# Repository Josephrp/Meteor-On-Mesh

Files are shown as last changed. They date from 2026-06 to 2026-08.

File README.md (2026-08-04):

# Meshtonic

**Meshtonic H4M Companion v2** is a custom carrier board and firmware stack for a [Seeed XIAO ESP32-S3 Plus](https://www.seeedstudio.com/Seeed-Studio-XIAO-ESP32S3-Plus-p-6361.html) that docks to a **HackRF + PortaPack H4M (Mayhem)** and can also run as a **standalone Meshtastic** mesh node.

**Repository:** [github.com/Josephrp/meshtonic](https://github.com/Josephrp/meshtonic) (formerly `Meteor-On-Mesh`)

<p align="center">
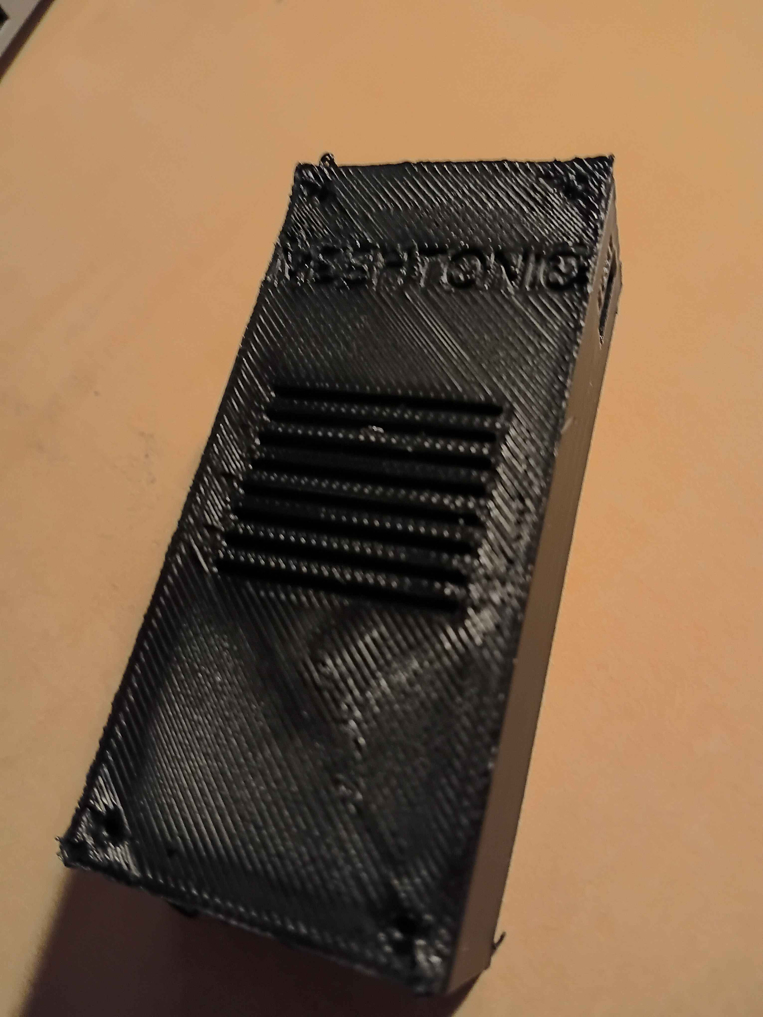
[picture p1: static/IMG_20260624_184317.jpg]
Meshtonic H4M Companion assembled
  
</p>

| Mode | Role |
|---|---|
| **Docked (Mayhem MDK)** | ESP32 is an I2C slave at `0x51` on the PortaPack MDK connector. Exposes GPS, sensors, web UI, and 1–4 LoRa radios to Mayhem; runs the on-device LoRa decoder EPApp. |
| **Standalone (Meshtastic)** | Flash the Meshtastic image instead. Board becomes a LoRa mesh node with GPS, TFT, and muxed sensors. |

The two ESP32 firmwares are **mutually exclusive** — flash one or the other depending on whether you are using the board docked or as a mesh node.

---

## Hardware overview

| Block | Parts |
|---|---|
| **MCU** | Seeed XIAO ESP32-S3 Plus (ESP32-S3, 16 MB flash, OPI PSRAM) |
| **LoRa** | Up to **4×** [Wio-SX1262](https://www.seeedstudio.com/) shields — shared SPI, per-radio CS on native GPIO, BUSY/DIO1/RST via **MCP23017** `@ 0x20` |
| **Sensors** | **TCA9548A** `@ 0x70` mux: BMM150, BMP280, SHT3x, BMI160; **AS5600** on the main I2C bus |
| **GPS** | NEO-6M (UART1) |
| **Display / storage** | ILI9341 240×320 SPI TFT, microSD |
| **Host link** | PortaPack H4M / MDK-compatible connector (I2C slave + power) |
| **Power** | USB / solar → **CN3170** LiPo charge → **TPS63020** 3.3 V buck-boost |

Canonical pin map (silicon GPIO numbers for the XIAO Plus — `Dn ≠ GPIOn` above D5):

- Shared SPI: MOSI / MISO / SCK = GPIO 38 / 39 / 40  
- I2C: SDA / SCL = GPIO 5 / 6  
- WIO1–4 CS: GPIO 3 / 4 / 10 / 13  
- MCP INTA: GPIO 44 · WIO1 DIO1: GPIO 12  
- Full table: [`firmwares/pin_mapping.cpp`](firmwares/pin_mapping.cpp) and the variant [`PIN_AUDIT.md`](firmwares/meshtastic/variants/esp32s3/diy/meshtonic_h4m_wio1/PIN_AUDIT.md)

<p align="center">
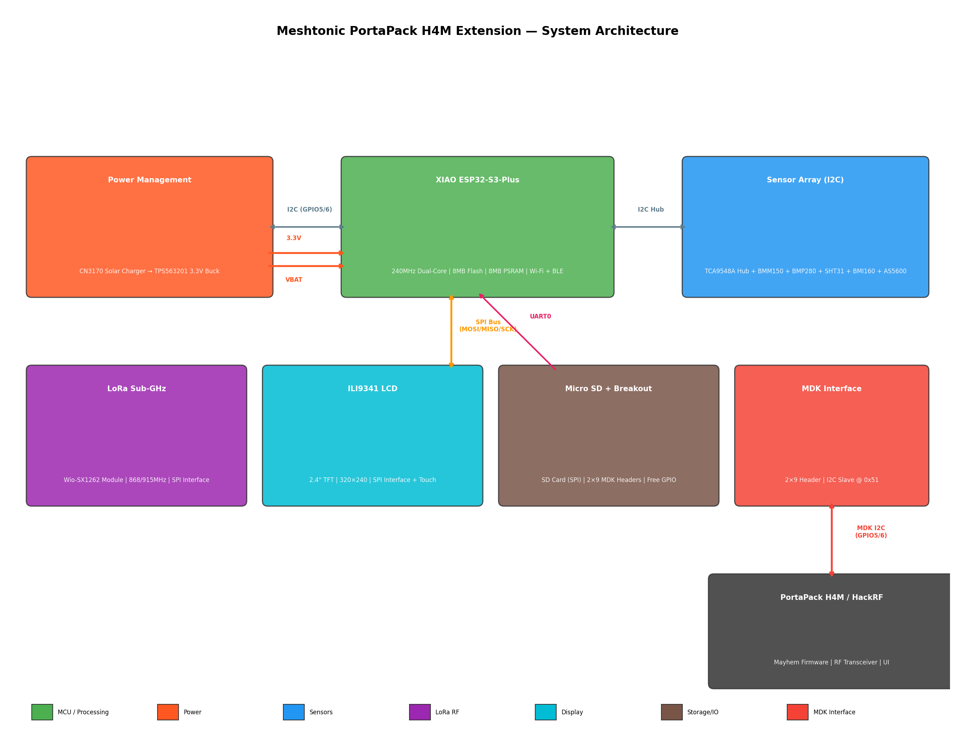
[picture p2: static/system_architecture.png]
System architecture
  
  <br />
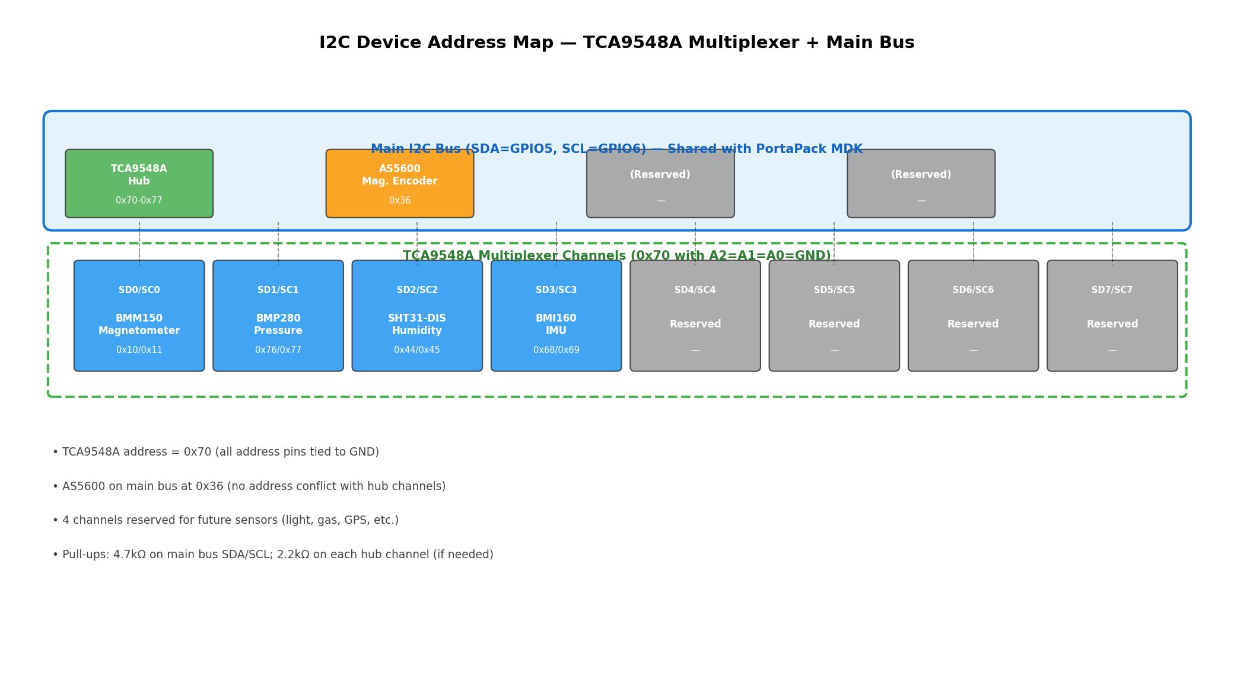
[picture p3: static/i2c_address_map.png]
I2C address map
  
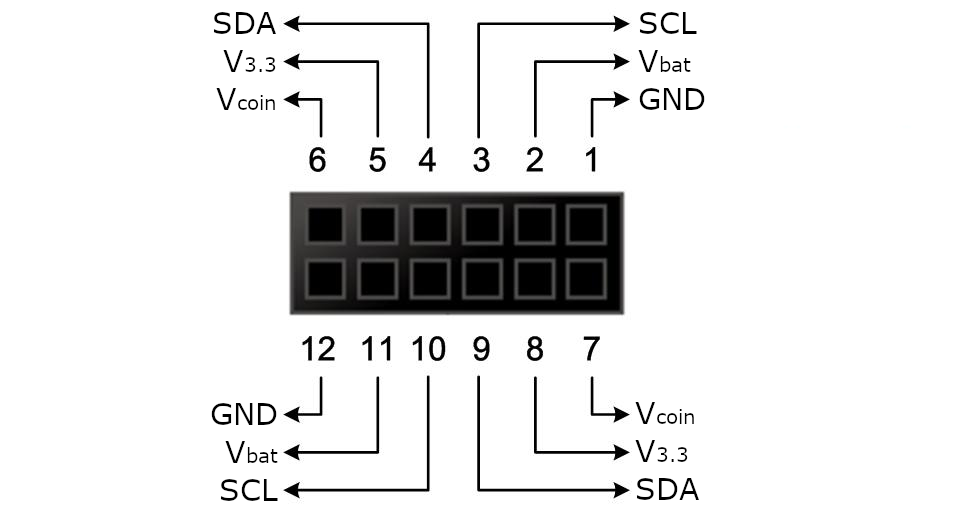
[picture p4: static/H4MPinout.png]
H4M pinout
  
</p>

Architecture notes for the docked LoRa path (MCP ISR → radio manager → decoder → web / PortaPack) live in [`static/diagrams.md`](static/diagrams.md).

### Enclosure

3D-printable case STLs (65 × 140 mm footprint):

- [`case/enclosure_base_65x140x32.stl`](case/enclosure_base_65x140x32.stl)
- [`case/enclosure_lid_65x140.stl`](case/enclosure_lid_65x140.stl)

---

## Software stack

| Tree | Upstream | Meshtonic role |
|---|---|---|
| [`firmwares/meshtastic/`](firmwares/meshtastic/) | [Meshtastic firmware](https://github.com/meshtastic/firmware) (GPL-3.0) | Custom board env `meshtonic-h4m-wio1` — WIO1-first standalone mesh |
| [`firmwares/mayhem-mdk/`](firmwares/mayhem-mdk/) | [ESP32-Portapack / Mayhem MDK](https://github.com/htotoo/ESP32-Portapack) (HTL) | Docked companion: `HW_VARIANT_MESHTONIC_H4M`, MCP + TCA drivers, multi-slot SX1262 manager, LoRa decoder EPApp, optional host LWD bridge |
| [`firmwares/mayhem-firmware/`](firmwares/mayhem-firmware/) | [PortaPack Mayhem](https://github.com/portapack-mayhem/mayhem-firmware) (GPL-3.0) | Vendored Mayhem tree + PortaPack UI app under `firmware/standalone/meshtonic_lora/` |

Shared first-party pin constants: [`firmwares/pin_mapping.cpp`](firmwares/pin_mapping.cpp).

### Docked LoRa decoder (MDK)

When Mayhem MDK is flashed with the Meshtonic H4M profile:

1. ESP32 auto-runs the LoRa Decoder EPApp.
2. Up to four Wio-SX1262 modules listen in parallel (narrowband).
3. Optional HackRF wideband path: PortaPack sends short IQ bursts over I2C (`0xA012`); ESP DSP + decode run on-device.
4. Status and packets paint on the PortaPack LCD (Apps over I2C) and/or the ESP web UI.

Protocol and backend IDs: [`firmwares/mayhem-mdk/docs/PORTAPACK_LORADEC.md`](firmwares/mayhem-mdk/docs/PORTAPACK_LORADEC.md).

```mermaid
flowchart TD
  Board["Meshtonic H4M (1-4 Wio SX1262)"] -->|MCP23017 + shared SPI| Radios["LoraRadio slots"]
  Radios --> EPApp["EPAppLoraDecoder"]
  EPApp --> Decode["Decode layer"]
  Decode --> Packets["LoraPacket"]
  Packets --> Web["Web / WS"]
  Packets --> PP["PortaPack I2C @ 0x51"]
  HostLWD["Host LWD optional"] -.-> Packets
```

---

## Repository map

```
meshtonic/
├── pcb/                 # KiCad project meshtonic_h4m_v2 (schematics, PCB, BOM, DFM)
├── firmwares/
│   ├── meshtastic/      # Meshtastic + meshtonic_h4m_wio1 variant
│   ├── mayhem-mdk/      # ESP32 Mayhem MDK + Meshtonic H4M profile
│   ├── mayhem-firmware/ # PortaPack Mayhem (+ meshtonic_lora PP app)
│   └── pin_mapping.cpp  # Canonical H4M v2 GPIO / MCP map
├── case/                # Enclosure STLs
├── static/              # Photos, pinout / architecture diagrams, demos
└── README.md
```

Local-only (gitignored) folders such as `refs/` and `backups/` may hold design plans and PCB snapshots on a developer machine; they are not part of the tracked tree.

---

## Getting started

### Prerequisites

| Firmware | Toolchain |
|---|---|
| Meshtastic | [PlatformIO](https://platformio.org/) (CLI or IDE) |
| Mayhem MDK | [ESP-IDF](https://docs.espressif.com/projects/esp-idf/en/latest/esp32s3/) targeting `esp32s3`, or the Docker builders under `firmwares/mayhem-mdk/docker/` |
| PortaPack app | Mayhem firmware build environment (see upstream Mayhem docs) |

Hardware bring-up checklist (I2C scan + radio):

- MCP23017 `@ 0x20`, TCA9548A `@ 0x70`, AS5600 `@ 0x36`
- SX1262 init on populated WIO slot(s)
- GPS NMEA on UART1
- ILI9341 bring-up (standalone Meshtastic)
- LoRa TX/RX with a second Meshtastic node (standalone)

### Flash Meshtastic (standalone)

```bash
cd firmwares/meshtastic
pio run -e meshtonic-h4m-wio1
pio run -e meshtonic-h4m-wio1 -t upload
pio device monitor -b 115200
```

- Board definition: [`boards/meshtonic_h4m_wio1.json`](firmwares/meshtastic/boards/meshtonic_h4m_wio1.json)
- Variant docs: [`variants/esp32s3/diy/meshtonic_h4m_wio1/`](firmwares/meshtastic/variants/esp32s3/diy/meshtonic_h4m_wio1/)
- Upload uses esptool @ 921600 with 1200 bps touch / wait-for-port (16 MB flash)
- Current Meshtastic port is **WIO1-first** (one radio). Multi-radio listening is implemented on the MDK side.

### Flash Mayhem MDK (docked companion)

```bash
cd firmwares/mayhem-mdk/Source
idf.py set-target esp32s3
# Select Meshtonic H4M pins: HW_VARIANT_MESHTONIC_H4M in code,
# and/or choose "Meshtonic H4M" in the web pin-config UI after first boot
idf.py build
idf.py -p <PORT> flash monitor
```

Docker alternative:

```bash
cd firmwares/mayhem-mdk/docker
# see build.ps1 / build-in-container.sh / docker-compose.yml
```

Pin preset for Meshtonic H4M: GPS RX = GPIO 7, shared I2C master+slave on GPIO 5/6 (`HW_VARIANT_MESHTONIC_H4M` in [`pinconfig.h`](firmwares/mayhem-mdk/Source/main/pinconfig.h)).

Optional host-side LoRa wideband decoder / bridge tooling: [`firmwares/mayhem-mdk/lora-wideband-decoder/`](firmwares/mayhem-mdk/lora-wideband-decoder/).

### PortaPack “Meshtonic LoRa” app

PortaPack-side UI that talks to the ESP over Apps-over-I2C lives in:

- [`firmwares/mayhem-firmware/firmware/standalone/meshtonic_lora/`](firmwares/mayhem-firmware/firmware/standalone/meshtonic_lora/)
- Reference / example: [`firmwares/mayhem-mdk/Source/extapps/meshtonic_lora_ui_example.cpp`](firmwares/mayhem-mdk/Source/extapps/meshtonic_lora_ui_example.cpp)

Build and install that app with your usual Mayhem standalone-app workflow, then launch it from the PortaPack App Manager (or rely on Meshtonic H4M auto-start of the ESP decoder).

---

## PCB and manufacturing

KiCad 8 project: **`pcb/meshtonic_h4m_v2`**

| Sheet | Contents |
|---|---|
| `meshtonic_h4m_v2.kicad_sch` | Root |
| `Power` | CN3170 charge, TPS63020 3.3 V, battery / solar |
| `Xiao_Core` | XIAO ESP32-S3 Plus |
| `LoRa` | WIO1–4 sockets, MCP23017 radio GPIO |
| `Sensors` | TCA9548A + environmental / IMU / mag |
| `Periferals` | TFT, microSD, GPS, Grove, misc |
| `H4M_Connector` / `MDK_Interface` | PortaPack dock |
| `Breakout_GPIO` | Expansion |

Also: `meshtonic_i2c-hub.kicad_*` for the I2C hub side project.

### BOM / fab

| Artifact | Purpose |
|---|---|
| [`pcb/meshtonic_h4m_v2.csv`](pcb/meshtonic_h4m_v2.csv) | Seeed Fusion–oriented PCBA BOM |
| [`pcb/meshtonic_h4m_v2_excluded_from_pcba.csv`](pcb/meshtonic_h4m_v2_excluded_from_pcba.csv) | Hand-fit / DNP (WIO sockets, display, test points, …) |
| [`pcb/_gen_seeed_bom.py`](pcb/_gen_seeed_bom.py) | Regenerates the Seeed BOM + exclusion list |
| [`pcb/dfm/`](pcb/dfm/) | Gerbers, drills, fab zip |

**Hand-fit after PCBA:** Wio-SX1262 modules (and their hybrid SMD+TH landings), display module, and any DNP connectors listed in the exclusion CSV.

Regenerate the Fusion BOM:

```bash
python pcb/_gen_seeed_bom.py
```

---

## Status

This is an active hardware + firmware bring-up project.

- PCB: Meshtonic H4M Companion **v2** (iterating layout / DFM)
- Meshtastic: custom `meshtonic-h4m-wio1` env — single-radio focus
- Mayhem MDK: Meshtonic H4M board profile, multi-radio LoRa decoder path in development
- PortaPack UI app and host LWD bridge: present; expect ongoing protocol/UI work

Demo media: [`static/`](static/) (photos + short videos).

---

## Licenses

This is a **multi-license** monorepo. The root [`LICENSE`](LICENSE) is the index; full texts live under [`LICENSES/`](LICENSES/).

| Component | License |
|---|---|
| `pcb/`, `case/`, `firmwares/pin_mapping.cpp` | [CERN-OHL-P-2.0](LICENSES/CERN-OHL-P-2.0.txt) |
| `README.md`, `static/` | [CC-BY-4.0](LICENSES/CC-BY-4.0.txt) |
| `firmwares/meshtastic/` | [GPL-3.0](firmwares/meshtastic/LICENSE) |
| `firmwares/mayhem-firmware/` | GPL-3.0 (see tree) |
| `firmwares/mayhem-mdk/` | Custom **HTL** — attribution, contribute improvements back, **no commercial use** ([`LICENSE`](firmwares/mayhem-mdk/LICENSE)) |
| `firmwares/mayhem-mdk/lora-wideband-decoder/` | See that subtree’s `LICENSE` |
| `pcb/libs/` | Upstream library licenses (unchanged) |

Meshtonic board support added inside a firmware tree follows that tree’s license unless a file says otherwise. Upstream copyrights remain with their respective authors.

---

## Links

- [This repository](https://github.com/Josephrp/meshtonic)
- [Meshtastic](https://meshtastic.org) · [firmware](https://github.com/meshtastic/firmware)
- [PortaPack Mayhem](https://github.com/portapack-mayhem/mayhem-firmware)
- [ESP32-Portapack / Mayhem MDK](https://github.com/htotoo/ESP32-Portapack) · [wiki](https://github.com/htotoo/ESP32-Portapack/wiki)
- [Seeed XIAO ESP32-S3 Plus](https://www.seeedstudio.com/Seeed-Studio-XIAO-ESP32S3-Plus-p-6361.html)
- In-repo diagrams: [`static/diagrams.md`](static/diagrams.md) · LoRa over I2C: [`docs/PORTAPACK_LORADEC.md`](firmwares/mayhem-mdk/docs/PORTAPACK_LORADEC.md)

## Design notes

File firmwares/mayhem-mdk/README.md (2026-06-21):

# ESP32-Portapack (ESP32PP)
An addon module for Portapack H4 / PortaRF to add GPS and extra sensors to it for more fun. (H2 too, but needs HW mod)

**This module is in early development. Suggest features via Issues, even for this module, even for the PortaPack (HackRf) part.**

## How to build one for yourself, or other questions? Check WIKI!
If you got the MDK hardware, it has a different pinout, so check the corresponding wiki page for that! Also download the right binary!

### Features:

- **Web interface** with remote control
- **GPS**
- **Compass**
- **Temperature + humidity + pressure + light**
- Portapack / PortaRF I2C interface support! Can add unique apps to PortaX!
- On system apps! The ESP can handle it's own apps built into it. For example Wifi SSID spoofer. (see [Wiki](https://github.com/htotoo/ESP32-Portapack/wiki/On-system-apps) for it)

For detailed info check Wiki

### Features not yet ready: 

- **IR blaster**
  - To add IR remote functions to PP. May be available only over I2C connection. Now only experimental RX.

- **LoRa**
  - Multi-protocol listener/decoder (Meshtastic, MeshCore, LoRaWAN, ...) using Meshtonic H4M 4x WIO SX1262 shields.
  - Rich native UI on HackRF/PortaPack screen via "Apps over I2C" (see docs/PORTAPACK_LORADEC.md). All RF on the WIO modules; the HackRF is used only for its screen + controls.

### Standalone apps
The module will supply additional apps for PortaX devices. Check the list in the [Wiki](https://github.com/htotoo/ESP32-Portapack/wiki/Apps-over-I2C)

Suggest in Issues if you get any ideas.

### Screenshots:
**ADS-B with location**

  

**ExtSensor app**



**Fox hunt app**



**SatTrack**



**Web app**



### More info
You can get more info in the [Wiki page](https://github.com/htotoo/ESP32-Portapack/wiki). Like, what modules are supported, functions with details. How to build and wire the module. How to flash it. How to start using it.

### Support
- Links are affiliate links! If you don't want to use them, feel free to just search for the modules yourself. Using the affiliate links gives me some credits, so I can buy and integrate more modules to this (or other) projects.
- If you want, you can buy me a coffee (fuel of programmers): https://www.buymeacoffee.com/htotoo
- This FW will be always open source and free to use all functions!

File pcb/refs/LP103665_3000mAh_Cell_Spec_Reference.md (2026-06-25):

# LP103665 / 103665 — 3.7 V 3000 mAh LiPo cell family reference

This is a **cell-format reference** for the pouch size commonly sold as Heltec / Meshtastic 3000 mAh packs (including AliExpress `1005008721775874`). It is **not** a certificate for any specific AliExpress shipment.

## Cell code meaning

| Digits | Meaning | Typical value |
| --- | --- | --- |
| `10` | Thickness (mm) | 10.0 mm |
| `36` | Width (mm) | 36.0 mm |
| `65` | Length (mm) | 65.0 mm |

Model names: **LP103665**, **PL103665**, **103665**, **FT103665P**.

## Electrical (industry typical for 3000 mAh 1S pouch + PCM)

| Parameter | Typical value | Notes |
| --- | --- | --- |
| Chemistry | 1S Li-ion / LiPo | Single-cell pouch |
| Nominal voltage | **3.7 V** | |
| Nominal capacity | **3000 mAh** | Verify printed label on received pack |
| Energy | **~11.1 Wh** | 3.7 V × 3 Ah |
| Charge voltage (max) | **4.20 V** | CC/CV; PCM may cut earlier |
| Discharge cut-off | **2.75–3.0 V** | PCM-dependent |
| Standard charge rate | **0.2C–0.5C** | 600–1500 mA for 3000 mAh |
| Max continuous charge | **1C** | 3000 mA — do not exceed without label proof |
| Standard discharge | **0.2C** | 600 mA |
| Max continuous discharge | **1C** | 3000 mA typical PCM limit |
| Peak / pulse discharge | **2C** | Some packs; verify label |
| Cycle life | **300–500** cycles to ≥80% | At 25 °C, 0.5C charge/discharge |
| Impedance | **≤50–180 mΩ** | Pack-level, vendor-dependent |

## Mechanical (bare cell vs pack)

| Item | Dimension | Notes |
| --- | --- | --- |
| Cell (T × W × L) | **10 × 36 × 65 mm** | Nominal bare pouch |
| Pack with PCM | **10 × 36 × 67 mm** | PCM adds ~1–2 mm to length |
| Weight | **~45–55 g** | With PCM and leads |
| Lead length | **50–150 mm** | Vendor-dependent |
| PCM | **Required** | OVP, UVP, over-current; some add NTC |

## Connector (often customized)

| Type | Pitch | Common on |
| --- | --- | --- |
| **JST PH** 2-pin | **2.0 mm** | Adafruit, SparkFun, many Meshtastic 3000 mAh packs, Meshtonic `J12` |
| **JST SH / “Micro JST 1.25”** 2-pin | **1.25 mm** | Heltec V3/V4 on-board battery socket, LilyGo T-Deck |

**Polarity is not standardized across vendors.** Always verify with a multimeter before first plug-in.

## Temperature and storage

| Mode | Range (typical) |
| --- | --- |
| Charge | **0 °C to +45 °C** |
| Discharge | **−20 °C to +60 °C** |
| Storage (short) | **−10 °C to +45 °C**, 45–75% RH |
| Long storage | Charge to **40–50%** SOC; cool dry place |

## Safety (pouch cell)

- No user-accessible safety vent (unlike some cylindrical cells). Failure mode is **swelling**, heat, or venting at seam — retire swollen packs.
- Do not puncture, crush, short, or charge unattended on flammable surfaces.
- PCM is mandatory for this project; bare unprotected cells are not acceptable on `J12`.

## Sources (cell family, not AliExpress listing)

| Source | URL |
| --- | --- |
| DNK Power — LP103665 3000 mAh product page | [https://www.dnkpower.com/products/103665-3-7v-3000mah-lithium-polymer-battery/](https://www.dnkpower.com/products/103665-3-7v-3000mah-lithium-polymer-battery/) |
| FelloTech — FT103665P 3000 mAh | [https://www.fellotech.com/3-7v-3000mah-103665-lipo-battery_p402.html](https://www.fellotech.com/3-7v-3000mah-103665-lipo-battery_p402.html) |
| SUJOR — 103665 3000 mAh | [https://www.sujorbattery.com/high-energy-density-battery/103665-3000mah-3-7v-lithium-polymer-battery-for-safety-helmet.html](https://www.sujorbattery.com/high-energy-density-battery/103665-3000mah-3-7v-lithium-polymer-battery-for-safety-helmet.html) |
| Akyga LP103665 distributor listing (AKY0944) | [https://elektronik.ropla.eu/en/magazyn/magazyn/?ic=AKY0944](https://elektronik.ropla.eu/en/magazyn/magazyn/?ic=AKY0944) |
| JST PH 2.0 mm connector guide | [https://keszoox.com/blogs/news/jst-ph-connector-complete-guide](https://keszoox.com/blogs/news/jst-ph-connector-complete-guide) |

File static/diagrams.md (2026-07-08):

#### Architecture Overview (data flow for backend=1)

```mermaid
flowchart TD
    A[MCP INTA GPIO ISR] -->|serviceInterruptsFromIsr| B[SXRadioManager]
    B -->|pending mask + handleDio1Irq| C[LoraRadio per slot]
    C -->|checkRxDone / poll| D[EPAppLoraDecoder::Loop]
    D -->|raw buf + rssi/snr| E[lora_decode_try_decrypt + parse + dispatch]
    E -->|enriched LoraPacket| F[pushPacket → packets ring]
    F --> G[sendPacketsToWeb / PP / display]
    H[Web/WS or PP SETCONFIG] --> I[setConfig → NVS → re-arm if needed]
    J[Radio policy] --> K[startCad or startRxContinuous per slot]
```

```mermaid
flowchart TD
  Board["Meshtonic H4M (1-4 Wio SX1262 + antennas)"] -->|MCP23017 CS/DIO1/BUSY/RST + shared SPI 11/12/13| LoraRadios["LoraRadio[0..3] (lora_radio.*)"]
  LoraRadios -->|CAD detect / RxDone + payload + RSSI/SNR| EPApp["EPAppLoraDecoder backend=1 (apps/ep_app_loradecoder.*)"]
  EPApp --> DecodeLayer["C++ decode layer (port LWD: header, CRC, AES retry, Meshtastic ports)"]
  DecodeLayer --> LoraPacket["LoraPacket (enriched)"]
  LoraPacket -->|push| Web["WS/HTTP /lwd or onboard + JSON packets"]
  LoraPacket --> Display
  LoraPacket -->|extend PP cmds| PP["PortaPack I2C @0x51"]
  HostLWD["Host LWD (HackRF wideband, optional)"] -->|bridge JSONL| LoraPacket
  Config["NVS + profile (radio_count, channels, keys) + web"] --> EPApp
```

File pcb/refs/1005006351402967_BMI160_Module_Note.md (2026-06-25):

# AliExpress item 1005006351402967 - BMI160 module note

Source URL:

- [AliExpress item 1005006351402967](https://fr.aliexpress.com/item/1005006351402967.html)

Identification status: medium confidence. Public search results identify the listing as a BMI160 6-axis motion sensor module. The authoritative chip datasheet was saved as `1005006351402967_BMI160_Bosch_Datasheet.pdf`.

Unverified details from the listing:

- Exact breakout PCB dimensions and mounting hole pattern.
- Whether the breakout has level shifting, onboard regulator, pullups, or selectable I2C address jumpers.
- Connector style and pin order.

Design implications:

- Treat the chip as 3.3 V logic unless the breakout proves otherwise.
- If using I2C, verify address `0x68` or `0x69` before sharing a downstream bus.
- Mount rigidly to the case/PCB if vibration or orientation data matters; do not leave on a loose cable.

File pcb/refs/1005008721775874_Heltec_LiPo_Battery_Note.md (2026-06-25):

# AliExpress item 1005008721775874 — Heltec LiPo battery note

Source URL:

- [AliExpress item 1005008721775874](https://www.aliexpress.com/item/1005008721775874.html)

## Identification

| Field | Value |
| --- | --- |
| Listing title (cached) | **Heltec 3.7 V LiPo Battery 3000 mAh / 800 mAh PL103665** — for T114 V2, LoRa 32 V3, LoRa node dev boards |
| Likely cell format | **PL103665 / LP103665** (10 × 36 × 65 mm pouch) when 3000 mAh variant is shipped |
| Alternate SKU on same listing | **800 mAh** smaller pack — same listing ID, different capacity |
| Manufacturer datasheet | **None tied to this AliExpress ID** |
| Cell-family reference | `pcb/refs/LP103665_3000mAh_Cell_Spec_Reference.md` |

**Confidence:** **medium** for 3000 mAh PL103665 identity from listing title and community cross-use; **low** for exact connector type, polarity, PCM thresholds, and true capacity until the received pack is measured and labeled.

## Unverified until received part

- Printed mAh on pouch label (3000 vs 800 vs overstated).
- Connector: **JST PH 2.0 mm** vs **JST SH 1.25 mm** (Heltec boards often use 1.25 mm on-board).
- Wire polarity at connector (vendor-dependent).
- PCM over-current and charge-current limit on protection board.
- True thickness with PCM (67 mm length is common).

## Meshtonic design implications

- `J12` is **JST PH 2.0 mm** horizontal (`PCM_SparkFun-Connector:JST_1x02_P2.0mm_Horizontal_SMD`). If the pack ships **1.25 mm**, use an adapter cable or re-crimp — do not force the wrong pitch.
- **Verify polarity with a meter** before first connection. Meshtonic `J12` PCB pads: **pin 1 = GND**, **pin 2 = VBAT** (SparkFun footprint `-_1` / `+_2`). This matches Adafruit/SparkFun LiPo convention but **differs from `SPEC.md` §14** (which incorrectly states pin 1 = VBAT).
- Board charge current (`CN3170` `R6` = 2.0 kΩ) ≈ **594 mA** — appropriate for **3000 mAh** (~0.2C). If the **800 mAh** variant arrives, **lower `R6`** or do not charge on-board until current is reduced (~160 mA for 0.2C).
- Reserve a **padded battery pocket** (~67 × 38 × 12 mm planning envelope) and **strain relief**; keep cell away from `U1`/`U2` heat and sharp case edges.
- Pouch cells **swell** slightly; do not design a friction-fit cavity from nominal dimensions alone.

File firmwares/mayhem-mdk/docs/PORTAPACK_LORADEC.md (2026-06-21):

# PortaPack LoRa Decoder — On-Device Protocol (no host PC)

The Meshtonic H4M runs the **LoRa Decoder** EPApp on the ESP32 at boot. When a PortaPack/HackRF is attached over I2C, the ESP32 processes IQ bursts on-chip and shows status on **both** the ESP OLED and the PortaPack LCD.

## Architecture

```
HackRF (in PortaPack)  →  energy detect + short IQ burst
        ↓ I2C (PP CMD 0xA012)
ESP32-S3               →  lora_dsp (Schmidl-Cox + dechirp) + lora_decode (multi-protocol)
        ↓
ESP OLED + PP LCD      →  decoded packets, preset, band stats
        ↑
4× WIO SX1262          →  narrowband multi-slot listen (parallel, no PC)
```

No computer is required. Optional WiFi web UI is for remote monitoring only.

## Start the app on PortaPack

1. Launch ESP app **04** (LoRa Decoder) via App Manager, or rely on Meshtonic H4M auto-start.
2. PortaPack polls `PPCMD_LORADEC_GETUI` (0xA013) at ~2 Hz to paint its screen.
3. PortaPack wideband path: capture 1–2 Msps burst (~2–8 ms), send via `PPCMD_LORADEC_FEEDIQ` (0xA012).

## I2C commands (ESP32 slave 0x51)

| CMD | Dir | Purpose |
|-----|-----|---|
| `0xA00E` | PP→ESP req | GETSTATUS — running, backend, center, slot mask |
| `0xA00F` | PP→ESP req | GETPACKETS — last 4 packets (compact binary) |
| `0xA010` | PP→ESP data | SETCONFIG — center_mhz, radio_count, backend |
| `0xA011` | PP→ESP data | CONTROL — see below |
| `0xA012` | PP→ESP data | FEEDIQ — HackRF IQ burst chunks |
| `0xA013` | PP→ESP req | GETUI — 6×20 char lines for PP LCD |

### CONTROL (0xA011) byte 0

| Op | Action |
|----|---|
| 0 | STOP |
| 1 | START |
| 2 | Arm WIO radios |
| 3 | Disarm WIO radios |
| 4 | Backend = HackRF DSP only |
| 5 | Backend = WIO only |
| 6 | Backend = hybrid (WIO + HackRF) |
| 7 | Apply preset — bytes 1…N = preset id ASCII (e.g. `US915-meshtastic`) |

### FEEDIQ (0xA012) payload

| Sub | Bytes | Meaning |
|-----|---|---|
| 0 | 1+4+4+4 | START: `float center_mhz`, `float fs_hz`, `uint32_t sample_count` |
| 1 | 1+4N | CHUNK: little-endian sc16 IQ pairs (I,Q,I,Q,…) |
| 2 | 0 | FLUSH — process partial buffer |

Max burst: **4096** complex samples per transaction (~8 ms @ 2 Msps). PortaPack should:

1. Tune HackRF to preset center (e.g. 915 MHz US).
2. Run coarse energy / max-hold on PP firmware.
3. On trigger, capture burst at **1–2 Msps sc16**, send START + CHUNK(s) + FLUSH.
4. ESP32 runs `lora_dsp_feed_sc16` + `lora_decode_process_air_ex`, pushes packets to both displays.

### GETUI (0xA013) response

| Offset | Field |
|---|---|
| 0 | running (0/1) |
| 1 | backend (0=bridge, 1=wio, 2=hackrf, 3=hybrid) |
| 2 | packet count (mod 256) |
| 3 | PortaPack linked (0/1) |
| 4 | active WIO radio count |
| 5 | HackRF burst count (mod 256) |
| 6–125 | six lines × 20 ASCII chars (space padded) |

## Backends

| ID | Name | Use |
|----|---|-----|
| 1 | `wio` | Standalone H4M — 4× SX1262 only |
| 2 | `hackrf` | PortaPack only — IQ bursts |
| 3 | `hybrid` | Both (default when PP connects) |
| 0 | `bridge` | Optional WiFi ingest from host (dev only) |

ESP web/serial: `LORA:BACKEND:hybrid`, `LORA:PRESET:US915-meshtastic`, `LORA:START`.

## Rich Native "Apps over I2C" UI (SatTrack pattern) — Recommended

For the best experience on the HackRF color screen:

- The ESP32PP registers a **MeshtonicLoRa** app via `PPHandler::add_app(...)` (binary starts with `standalone_app_info` header).
- PP discovers it via the standard module protocol (`I2cDev_PPmod` → device_info + getStandaloneAppInfo).
- User taps the icon (placed under RX); PP downloads the UI binary over the standard APP_TRANSFER path and runs it natively.
- While running, the PP-side UI uses the high-level custom commands below to fetch live data and send controls.
- All actual RF and decode happens on the Meshtonic 4× WIO SX1262 shields (WIO backend preferred). HackRF is used only for its screen + controls.

### New high-level custom commands for the rich UI (0xa02x range)

| CMD | Dir | Purpose |
|---|---|---|
| `PPCMD_LORADEC_STATUS`  (0xa020) | PP req → ESP | Returns `lora_rich_status_t` (running, backend, radio_count, active_preset, total, mask) |
| `PPCMD_LORADEC_PACKETS` (0xa021) | PP req → ESP | Returns array of `lora_packet_compact_t` (slot/region/preset/proto/rssi/info + preview) |
| `PPCMD_LORADEC_PRESETS` (0xa022) | PP req → ESP | Returns list of `lora_preset_entry_t` from the generated presets (presets.toml is the source) |
| `PPCMD_LORADEC_APPLY` (0xa023) | PP → ESP | Send preset id (null-terminated) to apply immediately on the WIO radios |
| `PPCMD_LORADEC_CONTROL` (0xa024) | PP → ESP | start/stop, clear, backend hints, etc. (byte 0 = op) |

These coexist with the older basic LORADEC commands (0xa00e–0xa013) and GETUI.

### Fallback / coexistence

- The basic EPApp commands (`GETSTATUS`, `GETPACKETS`, `CONTROL`, `GETUI`, `FEEDIQ`) continue to work for simple views and the on-ESP OLED.
- The rich app uses the new 0xa02x commands for full packet lists, preset browsing, and live status.
- When the rich app is active on the PP screen, the ESP should be in WIO (or hybrid-as-appropriate) backend and must **not** arm the HackRF RF path for LoRa demod.

## Legacy / simple PortaPack integration (still supported)

The older flow (launch EPApp 04, poll GETUI, optionally FEEDIQ) remains for basic LCD status or when no rich binary is registered.

## Implementation notes (this repo)

- `pp_commands.hpp` — command IDs
- `ppi2c/pp_structures.hpp` — `standalone_app_info`, `lora_*_t` compact records
- `main.cpp` — registration of app binary + `add_custom_command` send/got callbacks
- `apps/ep_app_loradecoder.*` + `lora_decoder_feed.h` — data providers and `lora_rich_apply_preset`
- `extapps/meshtonic_lora.h` — placeholder binary (header + tiny body). Replace with a real built image from the Mayhem firmware tree following the SatTrack example.

Reference real pattern: `extapps/sattrack.h`, registration + callbacks in `main.cpp`, `I2cDev_PPmod` on the PP side.

## Building the real rich UI binary (PortaPack Mayhem firmware side)

1. In the Mayhem repo, create `firmware/standalone/meshtonic_lora/` (or a minimal module app) that:
   - Begins with a correct `standalone_app_info` at the image front.
   - Uses the PP UI framework (Painter, widgets, encoder) to render packet list / slot bars / preset picker.
   - On a timer or button, issues the 0xa02x custom commands via the module I2C path to fetch data from the ESP.
   - On user action (choose preset, start/stop) sends APPLY / CONTROL.
2. Build the image, convert to C array (e.g. `xxd -i meshtonic_lora.bin > meshtonic_lora.h`), and drop into this repo's `Source/extapps/`.
3. Rebuild the ESP firmware — the app will now appear and run as a first-class citizen on the HackRF screen.

All RF work stays on the WIO shields. The onboard HackRF RF is not used for LoRa in this app.

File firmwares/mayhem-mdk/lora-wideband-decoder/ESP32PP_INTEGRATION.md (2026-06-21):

# LoRa Wideband Decoder — Vendored + ESP32PP / Mayhem MDK Integration

This directory is a **comprehensive vendor** of the LoRa Wideband Decoder (LWD) into the Mayhem MDK (ESP32PP) firmware tree.

## Architecture (on-device first — no PC required)

| Layer | Component | Role |
|---|---|---|
| ESP32 EPApp | `ep_app_loradecoder.cpp` | Standalone app on Meshtonic OLED; auto-starts on H4M |
| 4× WIO SX1262 | `lora_radio` + `lora_decode.cpp` | Narrowband multi-band listen + full C++ decode |
| HackRF + PortaPack | I2C `PPCMD_LORADEC_FEEDIQ` | IQ bursts → ESP32 `lora_dsp` + decode (see `docs/PORTAPACK_LORADEC.md`) |
| Presets | `presets.toml` → `lora_bands.h` | Single source for region/profile PHY |
| Optional host | Python LWD + bridge | Dev/lab only — **not required** for field use |

## Backends (`config.backend`)

1. **WIO (1)** — 4× SX1262 on Meshtonic H4M; default standalone mode
2. **HackRF DSP (2)** — PortaPack sends IQ bursts over I2C; ESP32 processes on-chip
3. **Hybrid (3)** — WIO narrowband + HackRF wideband bursts (auto when PortaPack connects)
4. **Host bridge (0)** — optional WiFi POST from a PC (development only)

## Registered band presets (29)

Generated from `presets.toml`. Examples:

| Preset | Region | PHY | Use |
|---|---|---|---|
| `US915-meshtastic` | US915 | SF11/250k @ 906.875+ | Default H4M US listen |
| `US-meshcore` | US915 | SF7/62.5k @ 910.525+ | MeshCore narrow |
| `US915-lorawan` | US915 | LoRaWAN grid 902.3+ | LoRaWAN monitor |
| `EU868-meshtastic` | EU868 | 869.525 | EU Meshtastic |
| `EU-meshcore` | EU868 | 869.525/869.618 | EU MeshCore |
| `CN470-meshtastic` | CN470 | 486.3+ | China |
| … | … | … | See `LORA:PRESETS` |

Regenerate C headers after editing presets:

```bash
python firmwares/mayhem-mdk/tools/gen_lora_bands.py
```

## ESP32 web commands (`LORA:` prefix, app id 04)

| Command | Effect |
|---|---|
| `LORA:START` / `STOP` | Session on/off |
| `LORA:PRESET:US915-meshtastic` | Apply 4-slot preset + re-arm |
| `LORA:REGION:EU868` | Shorthand region preset |
| `LORA:SLOT:3=US-meshcore` | Single slot preset |
| `LORA:PRESETS` | List preset IDs (JSON) |
| `LORA:CHLIST:0=906.875,11,250000,5,cad,US915-meshtastic` | Manual PHY + optional preset |
| `LORA:DECODE:mode=cpp\|python\|auto` | Decode tier |
| `LORA:DECODE:sidecar=http://host:8765` | Python sidecar URL |
| `LORA:KEYS:…` / `LORA:KEYS:sync` | Key management / export JSON |
| `LORA:STATUS` / `PACKETS` | Push JSON status / packets |

## JSON contract (`loradec_status` / `loradec_packets`)

Packets include: `slot`, `region`, `profile`, `band`, `proto`, `confidence`, `decrypted`, `decode_backend`.

Status includes `bands_in_use[]` with per-protocol counts and `presets_available`.

## Host workflows

### Wideband + bridge

```bash
cd lora-wideband-decoder
python run/meshtonic_listener.py --preset US915-meshtastic --mode wideband --esp http://192.168.4.1
# Or manually:
python -m src.soapy_rx --driver hackrf -f 915.0e6 -s 20e6 --format sc16 \
  | python src/decoder.py --harness /tmp/lwd.jsonl
python meshtonic_bridge_example.py --url http://192.168.4.1/lwd/packet --infile /tmp/lwd.jsonl
```

### Narrowband Python decode (sidecar)

```bash
python run/narrowband_service.py --esp http://192.168.4.1 --preset US915-meshtastic
# On ESP: LORA:DECODE:mode=python
```

### Decode test vector

```bash
python tools/decode_payload.py --preset US915-meshtastic --hex "ff..."
python firmwares/mayhem-mdk/tools/equiv_harness.py
```

## HTTP endpoints

| Endpoint | Method | Purpose |
|---|---|---|
| `/lwd/packet` | POST | Full `LoraDecodedRecord` JSON from host bridge |
| `/lwd/presets` | GET | List all band presets (JSON) |
| `/meshtonic/packet` | POST | Alias for `/lwd/packet` |

## Key store

- ESP NVS: `lora_keys` blob (structured entries with `protocol` field)
- Host: `lora-wideband-decoder/lora_keys.json` (Meshtastic + MeshCore defaults)
- Sync: `LORA:KEYS:sync` exports ESP key list as JSON

## Protocols decoded

| Protocol | Python LWD | On-device C++ |
|---|---|---|
| Meshtastic | Full AES-CTR + protobuf | Full |
| MeshCore | Full (Ed25519, channel decrypt) | Structural sniff |
| LoRaWAN | MHDR + grid + behavioral | Structural + grid |
| LoRaMesher, APRS, Reticulum, disaster.radio, RadioHead, EByte | Full | Structural sniff |

## Hardware

- WIO modules are band-matched (433 / 868 / 915). Match preset region to installed modules.
- Recommended US H4M: slots 0–2 `US915-meshtastic`, slot 3 `US-meshcore`.
- CAD RX policy recommended for 4-radio power budget.

## Files

- `src/lora/` — presets loader, LoRaWAN grid (all regions)
- `src/narrowband_dispatch.py` — payload-only decode API
- `presets.toml` — band registry
- `tools/gen_lora_bands.py` — generates firmware `lora_bands.h/.cpp`

## Updating the vendor

1. Replace `lora-wideband-decoder/` from upstream
2. Re-run `tools/gen_lora_bands.py` if presets changed
3. Re-test bridge + `equiv_harness.py`

Passive receive only where permitted.

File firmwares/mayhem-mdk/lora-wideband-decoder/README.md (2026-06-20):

# LORA Wideband Decoder

A self-hosted, single-user intercept receiver for LoRa traffic on typical and non-typical frequencies. Streams
IQ from your SDR, demodulates and decodes in software near-real-time, surfaces
everything in a local web UI.

## I wanna use it!

Debian / Ubuntu:

```bash
./install.sh
python3 run/web.py          # opens http://127.0.0.1:5000
```

Open the URL it prints, configure your SDR in the Config tab, hit **Start** in the UI, and intercepted
packets stream in live. The pipeline (SDR capture + detector + decoder)
is launched from the web UI based on `lora.toml`.

If your SDR is already plugged in and you've rebooted (or re-logged in)
after the installer added you to `plugdev`, the UI's **Config →
SDR/Radio → Detect** finds it automatically.

## What it does

- Captures wideband IQ from any SoapySDR-compatible SDR or bladeRF.
- Decodes Meshtastic, LoRaWAN, and MeshCore across SF7–SF12 at every
  standard bandwidth (62.5, 125, 250, 500 kHz).
- Surfaces decoded packets, node identities, and a live spectrum
  waterfall in a local Flask web UI.
- Keeps up with real-world Meshtastic and LoRaWAN traffic in real time
  on a multi-core host at 28 Msps wideband.
- Will attempt to give you as much information as possible for LORA protocols that has non-typical byte ordering to allow for custom protocol implementation.

## Supported SDRs

| Device | Path | Notes |
|---|---|---|
| **bladeRF** | native `bladeRF-cli` | Validated default at 28 Msps. (SoapyBladeRF fails at this rate; native CLI works) |
| **USRP B210 / B205mini** | SoapyUHD | Rated ~30 Msps over USB 3.0. (Tested at 28MHz)|
| HackRF | SoapySDR | Capped at 20 Msps (hardware). |
| RTL-SDR, Airspy, LimeSDR, PlutoSDR, … | SoapySDR | Varies — see device specs. |

Named profiles + live capability probing live in `src/sdr_profiles.py`.

## Building from source

If `./install.sh` doesn't fit (non-Debian distro, custom Python):

```bash
pip install -r requirements.txt
# distro packages: soapysdr-tools, python3-soapysdr,
# soapysdr-module-{bladerf,hackrf,rtlsdr,...},
# libusb-1.0, libfftw3-dev, python3-dev
```

Requires Python 3.11+ for `lora.toml` (stdlib `tomllib`). Older Python
runs fine but falls back to coded defaults from `src/lora_config.py`.

### Running in a Python venv (optional)

If you prefer an isolated install (e.g. deploying to `/opt/lwd/`),
create the venv with `--system-site-packages` so it can reach the
apt-installed SoapySDR:

```bash
python3 -m venv --system-site-packages /opt/lwd/virtenv
source /opt/lwd/virtenv/bin/activate
pip install -r requirements.txt
```

**Why this flag is required**: `python3-soapysdr` ships as a SWIG-
generated C extension bound to the system python interpreter — it is
NOT pip-installable. Without `--system-site-packages`, `import SoapySDR`
from inside the venv fails even though `apt` reports it installed.
Other Python deps (numpy, scipy, flask, etc.) still pin cleanly inside
the venv; the flag only adds a fallback to system `dist-packages` for
modules the venv itself doesn't provide.

A venv created without the flag can't be retrofitted — delete and
recreate it. If `install.sh` is run inside an active venv, it detects
whether the flag is set and warns if it isn't.

Most users don't need a venv — `./install.sh` installs to the user site
via `pip --user` and the project runs without any activation step. Use
a venv only if you specifically want isolation or are deploying to a
controlled path.

## Reporting issues

If something isn't working — pipeline failure, crash, or a protocol that
isn't being recognised — please include the matching artifact below so the
problem can be reproduced without guessing.

1. **Verbose server (recommended for almost everything)**:

   ```bash
   python3 run/web.py --debug
   ```

   Starts the server normally and writes `lora_debug_<timestamp>.txt`
   to the project root, while also streaming the SDR capture
   subprocess output live to the terminal. Click **Start** in the UI
   and reproduce the issue; the bundle grows as the pipeline runs.
   Attach the file to the GitHub issue.

2. **Standalone collector** — use when the web UI won't start at all:

   ```bash
   python3 run/collect_debug.py
   ```

   Writes the same `lora_debug_<timestamp>.txt` to the project root —
   environment info, SoapySDR/SDR state, USB inventory, your config,
   plus a brief capture probe against your configured SDR. Attach the
   file to the GitHub issue.

3. **Unknown-protocol report** — use when frames are being received but
   not decoded (mystery devices, "no decodes" with traffic visible in
   the waterfall, suspected new/unsupported protocol):

   - In the web UI: open the **Advanced Options** panel and toggle
     **Unknown** on.
   - Click **Start** and let it run while the unknown traffic is
     active — a few minutes is usually enough, longer is better.
   - Scroll back to **Advanced Options → Unknown-protocol report**
     and click **Download**. That saves
     `lora_unknown_report.jsonl` — raw bytes plus PHY parameters
     (SF, BW, sync word, frequency) for every captured frame the
     decoder couldn't identify.
   - Attach the file to the GitHub issue.

All three modes scrub `$HOME` paths, hostname, IPs, and MAC addresses
before output; SDR serials and SoapySDR module versions are kept
because they are needed to diagnose hardware-specific bugs. The
unknown-protocol report contains only on-air bytes and PHY parameters
— no PII, no decoded content.

## Docs

- [Identification & protocols](docs/identification.md): how protocols
  are labeled, channel keys, Meshtastic preset list.
- [Headless mode](docs/headless.md): running it without the web UI.
- [Performance & tuning](docs/performance.md): throughput knobs and
  what to change when things drop samples.
- [Environment-variable overrides](docs/env-overrides.md): optional
  runtime overrides for `lora.toml`.
- [Security & deployment](docs/security.md): network exposure,
  privileges, hosting.

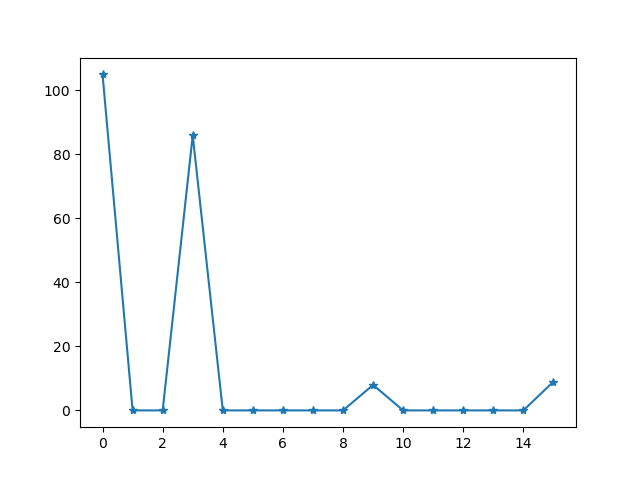
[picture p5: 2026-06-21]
firmwares/mayhem-firmware/hackrf/docs/images/dc_spike_example_spectrum.png

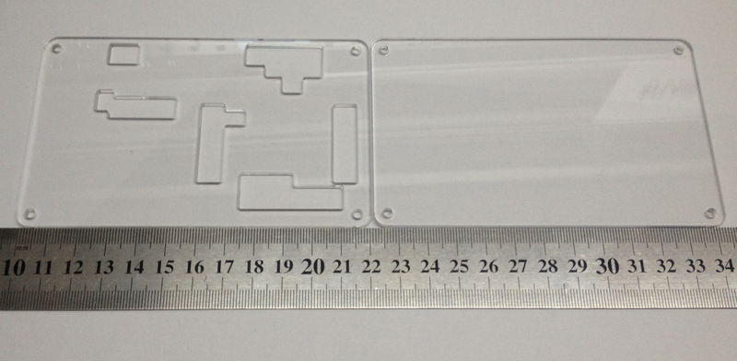
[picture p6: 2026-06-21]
firmwares/mayhem-firmware/hackrf/hardware/hackrf-one/PlasticCase_CAD/HackRF_One_Case.png

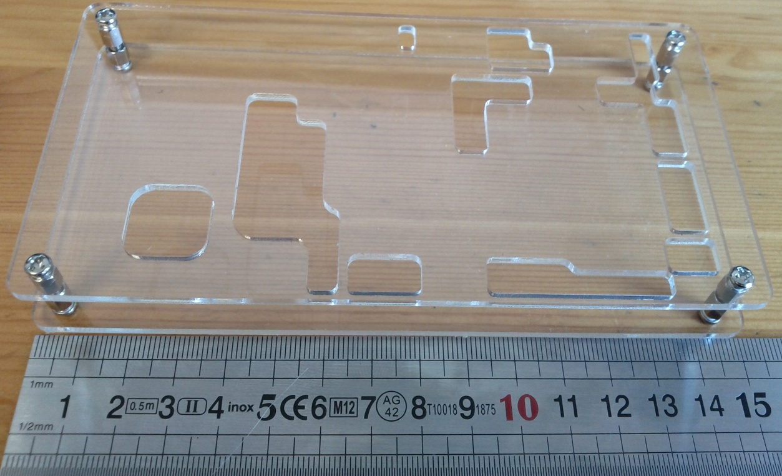
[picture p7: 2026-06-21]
firmwares/mayhem-firmware/hackrf/hardware/jawbreaker/SoBv1_DP17298/SoBv1-DP17298-jawbreaker.jpg

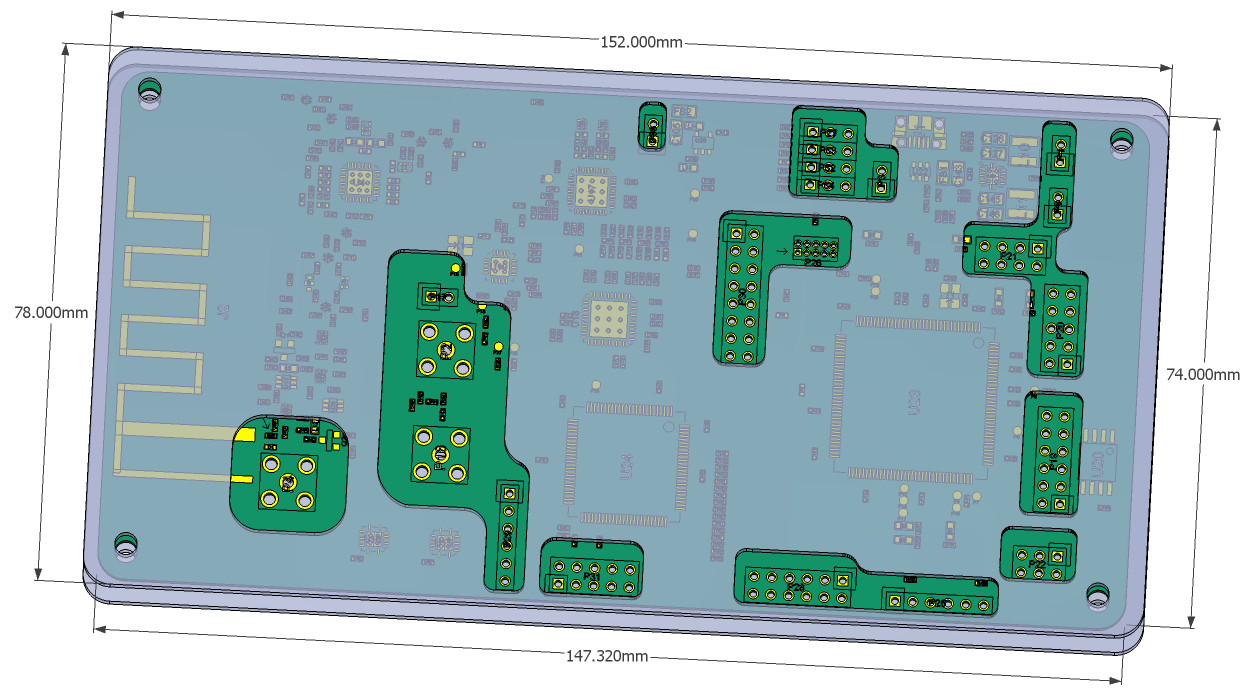
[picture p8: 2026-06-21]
firmwares/mayhem-firmware/hackrf/hardware/jawbreaker/SoBv1_DP17298/jawbreaker_and_case.png

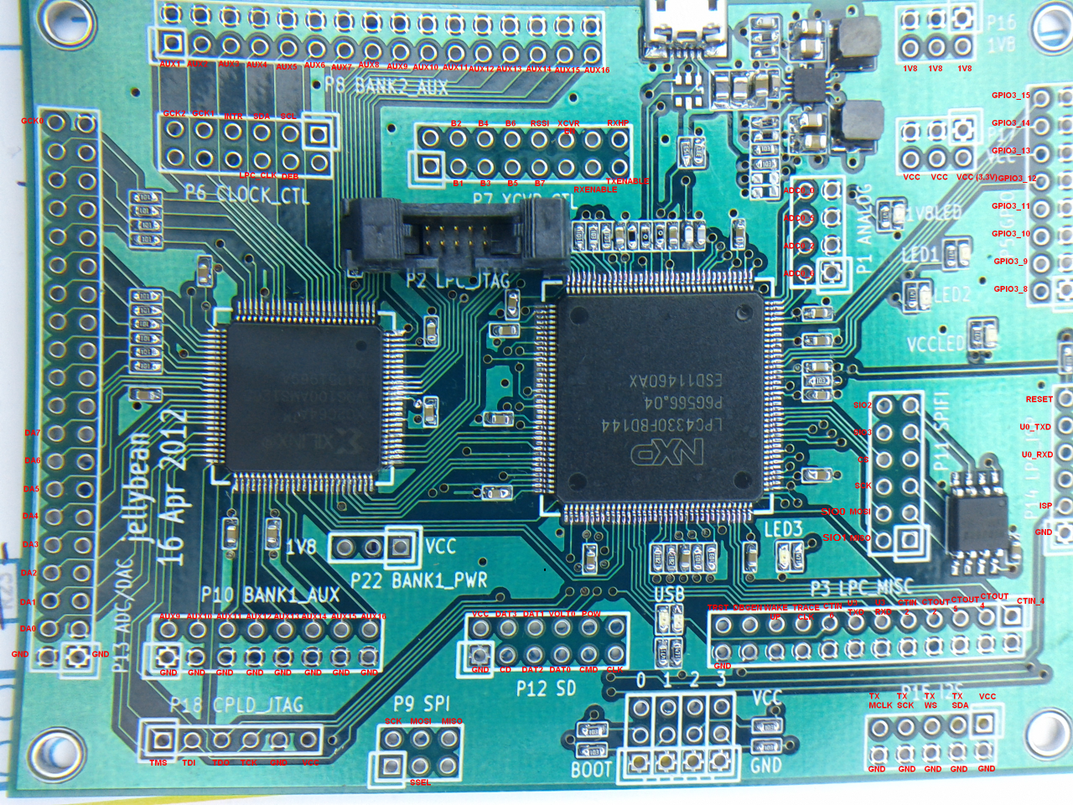
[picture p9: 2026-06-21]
firmwares/mayhem-firmware/hackrf/hardware/jellybean/JellyBean_pins.png

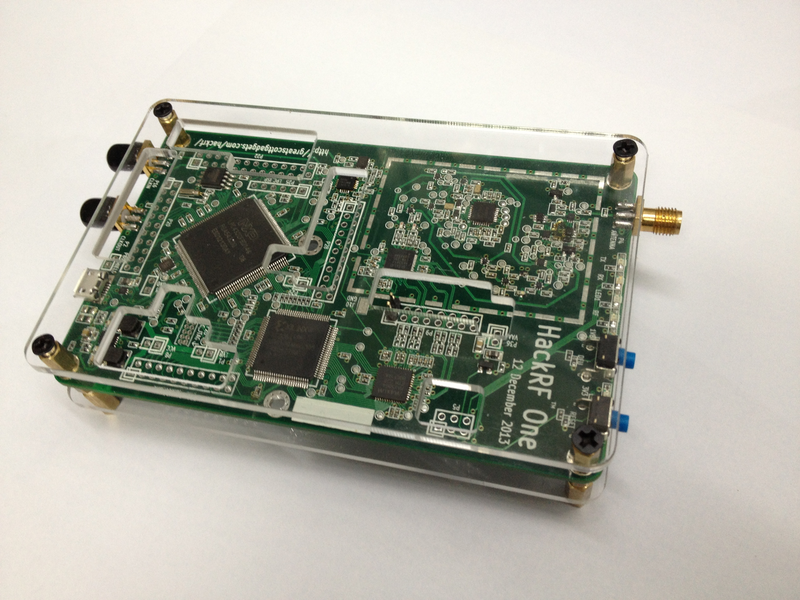
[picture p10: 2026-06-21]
firmwares/mayhem-firmware/hackrf/hardware/hackrf-one/PlasticCase_CAD/Case_With_HackRF.png

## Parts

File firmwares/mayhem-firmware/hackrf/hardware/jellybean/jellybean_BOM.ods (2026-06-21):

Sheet: JellyBean_BOM
Ref | Value | Manufacturer | Footprint | Details | DigiKey Quantity | DigiKey PN
R1 | 0 | Panasonic | ERJ-3GEY0R00V | RES 0.0 OHM 1/10W 0603 SMD | 2 | P0.0GCT-ND
R2 | 0 | Panasonic | ERJ-3GEY0R00V | RES 0.0 OHM 1/10W 0603 SMD
R18 | 100 | Panasonic | ERJ-3GEYJ101V | RES 100 OHM 1/10W 5% 0603 SMD | 10 | P100GCT-ND
R19 | 100 | Panasonic | ERJ-3GEYJ101V | RES 100 OHM 1/10W 5% 0603 SMD
R20 | 100 | Panasonic | ERJ-3GEYJ101V | RES 100 OHM 1/10W 5% 0603 SMD
R21 | 100 | Panasonic | ERJ-3GEYJ101V | RES 100 OHM 1/10W 5% 0603 SMD
R22 | 100 | Panasonic | ERJ-3GEYJ101V | RES 100 OHM 1/10W 5% 0603 SMD
R23 | 100 | Panasonic | ERJ-3GEYJ101V | RES 100 OHM 1/10W 5% 0603 SMD
R24 | 100 | Panasonic | ERJ-3GEYJ101V | RES 100 OHM 1/10W 5% 0603 SMD
R25 | 100 | Panasonic | ERJ-3GEYJ101V | RES 100 OHM 1/10W 5% 0603 SMD
R26 | 100 | Panasonic | ERJ-3GEYJ101V | RES 100 OHM 1/10W 5% 0603 SMD
R27 | 100 | Panasonic | ERJ-3GEYJ101V | RES 100 OHM 1/10W 5% 0603 SMD
R12 | 470 | Panasonic | ERJ-3GEYJ471V | RES 470 OHM 1/10W 5% 0603 SMD | 7 | P470GCT-ND
R13 | 470 | Panasonic | ERJ-3GEYJ471V | RES 470 OHM 1/10W 5% 0603 SMD
R15 | 470 | Panasonic | ERJ-3GEYJ471V | RES 470 OHM 1/10W 5% 0603 SMD
R29 | 470 | Panasonic | ERJ-3GEYJ471V | RES 470 OHM 1/10W 5% 0603 SMD
R3 | 470 | Panasonic | ERJ-3GEYJ471V | RES 470 OHM 1/10W 5% 0603 SMD
R8 | 470 | Panasonic | ERJ-3GEYJ471V | RES 470 OHM 1/10W 5% 0603 SMD
R9 | 470 | Panasonic | ERJ-3GEYJ471V | RES 470 OHM 1/10W 5% 0603 SMD
R30 | 1k8 | Panasonic | ERJ-3GEYJ182V | RES 1.8K OHM 1/10W 5% 0603 SMD | 2 | P1.8KGCT-ND
R31 | 1k8 | Panasonic | ERJ-3GEYJ182V | RES 1.8K OHM 1/10W 5% 0603 SMD
R16 | 10k | Panasonic | ERJ-3GEYJ103V | RES 10K OHM 1/10W 5% 0603 SMD | 13 | P10KGCT-ND
R17 | 10k | Panasonic | ERJ-3GEYJ103V | RES 10K OHM 1/10W 5% 0603 SMD
R28 | 10k | Panasonic | ERJ-3GEYJ103V | RES 10K OHM 1/10W 5% 0603 SMD
R32 | 10k | Panasonic | ERJ-3GEYJ103V | RES 10K OHM 1/10W 5% 0603 SMD
R39 | 10k | Panasonic | ERJ-3GEYJ103V | RES 10K OHM 1/10W 5% 0603 SMD
R4 | 10k | Panasonic | ERJ-3GEYJ103V | RES 10K OHM 1/10W 5% 0603 SMD
R40 | 10k | Panasonic | ERJ-3GEYJ103V | RES 10K OHM 1/10W 5% 0603 SMD
R41 | 10k | Panasonic | ERJ-3GEYJ103V | RES 10K OHM 1/10W 5% 0603 SMD
R42 | 10k | Panasonic | ERJ-3GEYJ103V | RES 10K OHM 1/10W 5% 0603 SMD
R43 | 10k | Panasonic | ERJ-3GEYJ103V | RES 10K OHM 1/10W 5% 0603 SMD
R5 | 10k | Panasonic | ERJ-3GEYJ103V | RES 10K OHM 1/10W 5% 0603 SMD
R6 | 10k | Panasonic | ERJ-3GEYJ103V | RES 10K OHM 1/10W 5% 0603 SMD
R7 | 10k | Panasonic | ERJ-3GEYJ103V | RES 10K OHM 1/10W 5% 0603 SMD
R14 | 12k | Panasonic | ERJ-3EKF1202V | RES 12.0K OHM 1/10W 1% 0603 SMD | 1 | P12.0KHCT-ND
R10 | 15k | Panasonic | ERJ-3GEYJ153V | RES 15K OHM 1/10W 5% 0603 SMD | 1 | P15KGCT-ND
R11 | 33k | Panasonic | ERJ-3GEYJ333V | RES 33K OHM 1/10W 5% 0603 SMD | 1 | P33KGCT-ND
R36 | 160k+560k in parallel (to obtain 3,3V instead of 2.7V) | Panasonic | ERJ-3EKF1603V | RES 160K OHM 1/10W 1% 0603 SMD | 1 | P160KHCT-ND
R35 | 180k | Panasonic | ERJ-3EKF1803V | RES 180K OHM 1/10W 1% 0603 SMD | 1 | P180KHCT-ND
R37 | 360k | Panasonic | ERJ-3EKF3603V | RES 360K OHM 1/10W 1% 0603 SMD | 1 | P360KHCT-ND
R38 | 560k | Panasonic | ERJ-3EKF5603V | RES 560K OHM 1/10W 1% 0603 SMD | 2 | P560KHCT-ND
C24 | 22pF | Murata | GRM1885C1H220JA01D | CAP CER 22PF 50V 5% NP0 0603 | 10 | 490-1411-1-ND
C18 | 47pF | Murata | GRM1885C1H470JA01D | CAP CER 47PF 50V 5% NP0 0603 | 10 | 490-1419-1-ND
C1 | 100nF | Murata | GRM188R71C104KA01D | CAP CER 0.1UF 16V 10% X7R 0603 | 30 | 490-1532-1-ND
C10 | 100nF | Murata | GRM188R71C104KA01D | CAP CER 0.1UF 16V 10% X7R 0603
C11 | 100nF | Murata | GRM188R71C104KA01D | CAP CER 0.1UF 16V 10% X7R 0603
C12 | 100nF | Murata | GRM188R71C104KA01D | CAP CER 0.1UF 16V 10% X7R 0603
C13 | 100nF | Murata | GRM188R71C104KA01D | CAP CER 0.1UF 16V 10% X7R 0603
C14 | 100nF | Murata | GRM188R71C104KA01D | CAP CER 0.1UF 16V 10% X7R 0603
C15 | 100nF | Murata | GRM188R71C104KA01D | CAP CER 0.1UF 16V 10% X7R 0603
C17 | 100nF | Murata | GRM188R71C104KA01D | CAP CER 0.1UF 16V 10% X7R 0603
C19 | 100nF | Murata | GRM188R71C104KA01D | CAP CER 0.1UF 16V 10% X7R 0603
C2 | 100nF | Murata | GRM188R71C104KA01D | CAP CER 0.1UF 16V 10% X7R 0603
C20 | 100nF | Murata | GRM188R71C104KA01D | CAP CER 0.1UF 16V 10% X7R 0603
C22 | 100nF | Murata | GRM188R71C104KA01D | CAP CER 0.1UF 16V 10% X7R 0603
C23 | 100nF | Murata | GRM188R71C104KA01D | CAP CER 0.1UF 16V 10% X7R 0603
C25 | 100nF | Murata | GRM188R71C104KA01D | CAP CER 0.1UF 16V 10% X7R 0603
C26 | 100nF | Murata | GRM188R71C104KA01D | CAP CER 0.1UF 16V 10% X7R 0603
C29 | 100nF | Murata | GRM188R71C104KA01D | CAP CER 0.1UF 16V 10% X7R 0603
C3 | 100nF | Murata | GRM188R71C104KA01D | CAP CER 0.1UF 16V 10% X7R 0603
C32 | 100nF | Murata | GRM188R71C104KA01D | CAP CER 0.1UF 16V 10% X7R 0603
C33 | 100nF | Murata | GRM188R71C104KA01D | CAP CER 0.1UF 16V 10% X7R 0603
C4 | 100nF | Murata | GRM188R71C104KA01D | CAP CER 0.1UF 16V 10% X7R 0603
C5 | 100nF | Murata | GRM188R71C104KA01D | CAP CER 0.1UF 16V 10% X7R 0603
C7 | 100nF | Murata | GRM188R71C104KA01D | CAP CER 0.1UF 16V 10% X7R 0603
C8 | 100nF | Murata | GRM188R71C104KA01D | CAP CER 0.1UF 16V 10% X7R 0603
C9 | 100nF | Murata | GRM188R71C104KA01D | CAP CER 0.1UF 16V 10% X7R 0603
C16 | 100pF | Murata | GRM1885C1H101JA01D | CAP CER 100PF 50V 5% NP0 0603 | 10 | 490-1427-1-ND
C6 | 4u7 | Taiyo Yuden | LMK212BJ475KD-T | CAP CER 4.7UF 10V 10% X5R 0805 | 1 | 587-1297-1-ND
C21 | 10uF | Murata | GRM21BR61A106KE19L | CAP CER 10UF 10V 10% X5R 0805 | 10 | 490-1709-1-ND
C27 | 10uF | Murata | GRM21BR61A106KE19L | CAP CER 10UF 10V 10% X5R 0805
C28 | 10uF | Murata | GRM21BR61A106KE19L | CAP CER 10UF 10V 10% X5R 0805
C30 | 10uF | Murata | GRM21BR61A106KE19L | CAP CER 10UF 10V 10% X5R 0805
C31 | 10uF | Murata | GRM21BR61A106KE19L | CAP CER 10UF 10V 10% X5R 0805
L1 | 4u7 | Taiyo Yuden | NRG4026T4R7M | INDUCTOR 4.7UH 1.6A 20% SMD | 2 | 587-2382-1-ND
L2 | 4u7 | Taiyo Yuden | NRG4026T4R7M | INDUCTOR 4.7UH 1.6A 20% SMD
FB1 | FILTER | Murata | BLM21PG221SN1D | FERRITE CHIP 220 OHM 2000MA 0805 | 1 | 490-1054-1-ND
U1 | GSG-IP4220CZ6 | NXP | IP4220CZ6,125 | IC USB DUAL ESD PROTECT 6TSOP | 1 | 568-3529-1-ND
J1 | GSG-USB-MICRO-B | FCI | 10103594-0001LF | CONN RCPT STD MICRO USB TYPE B | 1 | 609-4050-1-ND
U4 | GSG-XC2C64A-7VQG100C | Xilinx | XC2C64A-7VQG100C | IC CR-II CPLD 64MCELL 100-VQFP | 1 | 122-1409-ND
U2 | LPC43XXFBD144 | NXP | LPC4330FBD144,551 | IC MCU 32BIT 144LQFP | 1 | 568-9450-ND
U5 | TPS62410 | Texas Instruments | TPS62410DRCR | IC BUCK SYNC DUAL ADJ 0.8A 10SON | 1 | 296-25488-1-ND
D3 | LED3 | Everlight | QTLP601CRTR | LED RED STD BRIGHT 0603 SMD | 1 | 1080-1407-1-ND
D5 | 1V8LED | Everlight | QTLP600CYTR | LED YLW SUPER BRIGHT 0606 SMD | 3 | 1080-1404-1-ND
D2 | LED2 | Everlight | QTLP600CYTR | LED YLW SUPER BRIGHT 0606 SMD
D7 | USBLED0 | Everlight | QTLP600CYTR | LED YLW SUPER BRIGHT 0606 SMD
D1 | LED1 | Everlight | QTLP601C4TR | LED GREEN STD BRIGHT 0603 SMD | 3 | 1080-1405-1-ND
D6 | USBLED1 | Everlight | QTLP601C4TR | LED GREEN STD BRIGHT 0603 SMD
D4 | VCCLED | Everlight | QTLP601C4TR | LED GREEN STD BRIGHT 0603 SMD
U3 | W25Q80BV | Winbond | W25Q80BVSSIG | IC FLASH 8MBIT 8SOIC | 1 | W25Q80BVSSIG-ND
P2 | LPC_JTAG | Samtec Inc | EHF-105-01-L-D | CONN HEADER .05" 10POS DUAL T/H | 1 | SAM8205-ND
P16 | 1V8
P13 | ADC/DAC
P1 | ANALOG
P10 | BANK1_AUX
P22 | BANK1_PWR
P8 | BANK2_AUX
P4 | BOOT0
P19 | BOOT1
P20 | BOOT2
P21 | BOOT3
P6 | CLOCK_CTL
P18 | CPLD_JTAG
R33 | DNP
R34 | DNP
P5 | GPIO
P15 | I2S
P14 | LPC_ISP
P3 | LPC_MISC
P12 | SD
P9 | SPI
P11 | SPIFI
P7 | XCVR_CTL
P17 | VCC

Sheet: ImportPart_DigiKey
2,P0.0GCT-ND
10,P100GCT-ND
7,P470GCT-ND
2,P1.8KGCT-ND
13,P10KGCT-ND
1,P12.0KHCT-ND
1,P15KGCT-ND
1,P33KGCT-ND
1,P160KHCT-ND
1,P180KHCT-ND
1,P360KHCT-ND
2,P560KHCT-ND
10,490-1411-1-ND
10,490-1419-1-ND
30,490-1532-1-ND
10,490-1427-1-ND
1,587-1297-1-ND
10,490-1709-1-ND
2,587-2382-1-ND
1,490-1054-1-ND
1,568-3529-1-ND
1,609-4050-1-ND
1,122-1409-ND
1,568-9450-ND
1,296-25488-1-ND
1,1080-1407-1-ND
3,1080-1404-1-ND
3,1080-1405-1-ND
1,W25Q80BVSSIG-ND
1,SAM8205-ND

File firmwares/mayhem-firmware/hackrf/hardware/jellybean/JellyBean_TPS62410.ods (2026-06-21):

 | TPS62410 VCC |  | TPS62410 1V8
R36 (OHM) | 160000 | R35 (OHM) | 180000
R38 (OHM) | 560000 | R37 (OHM) | 360000
 | VCC (Converter1) |  | 1V8
Out Voltage | 2,7 | Out Voltage | 1,8
After Fix 3.3V
 | TPS62410 VCC
R36 (OHM) | 124444 | 160KOHM in // with 560KOHM
R38 (OHM) | 560000
 | VCC (Converter1)
Out Voltage | 3,3

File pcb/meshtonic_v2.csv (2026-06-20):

Reference | Qty | Value | DNP | Exclude from BOM | Exclude from Board | Footprint | Datasheet
C1,C2,C8,C10,C12,C14 | 6 | 10uF |  |  |  | PCM_SparkFun-Capacitor:C_0603_1608Metric_Polar | https://datasheets.kyocera-avx.com/tc-series.pdf
C3,C4,C5 | 3 | 22uF |  |  |  | PCM_SparkFun-Capacitor:C_0603_1608Metric | https://cdn.sparkfun.com/assets/8/a/4/a/5/Kemet_Capacitor_Datasheet.pdf
C6,C7,C9,C11,C13,C15,C18 | 7 | CERAMIC-100NF-50V-10%-X7R_0805_ |  |  |  | Capacitor_SMD:C_0805_2012Metric
C16,C17 | 2 | 100nF |  |  |  | Capacitor_SMD:C_0603_1608Metric
D1 | 1 | Red |  |  |  | PCM_SparkFun-LED:LED_0402_1005Metric_Red | https://www.sunledusa.com/products/spec/XZMDK68W-2.pdf
D2,D3 | 2 | 1N5819 |  |  |  | Diode_THT:D_DO-41_SOD81_P10.16mm_Horizontal | http://www.vishay.com/docs/88525/1n5817.pdf
D4,D5 | 2 | Green |  |  |  | PCM_SparkFun-LED:LED_1206_3216Metric_Green | https://www.inolux-corp.com/datasheet/SMDLED/Mono%20Color%20Top%20View/IN-S126AT%20Series_V1.0.pdf
D6,D7,D8 | 3 | LED-SMD-RED-DIFFUSED_0603_ |  |  |  | LED_SMD:LED_0603_1608Metric
DISP1 | 1 | CR2013-MI2120 |  |  | Excluded from board |  | http://pan.baidu.com/s/11Y990
J1,J3,J4,J5,J6 | 5 | GROVE-CONNECTOR-DIP_4P-2.0_ |  |  |  | seeed:GROVE-HW4-2.0
J2 | 1 | GROVE-CONNECTOR-DIP-90D_4P-2.0_ |  |  |  | seeed:GROVE-HW4-2.0-90D
J7 | 1 | seeed:GROVE-HW4-2.0 |  |  |  | seeed:GROVE-HW4-2.0
J8 | 1 | GROVE-CONNECTOR-SMD_4+2P-2.0_ |  |  |  | Connector:GROVE-HW4-SMD-2.0
J9,J10,J11 | 3 | Conn_01x02 |  |  |  | PCM_SparkFun-Connector:1x02_P2.54mm
J12 | 1 | JST_2mm_LiPo |  |  |  | PCM_SparkFun-Connector:JST_1x02_P2.0mm_Horizontal_SMD
J13 | 1 | Screw_Terminal_01x02 |  |  |  | Connector_PinHeader_2.54mm:PinHeader_1x02_P2.54mm_Vertical
J14 | 1 | Micro_SD_Card_passive_clk |  |  |  | seeed:MICRO-SD9+4P-SMD-16.1X14.5X1.85MM | https://www.we-online.com/components/products/datasheet/693072010801.pdf
J15 | 1 | H4M_2x6_MDK |  |  |  | Connector_PinHeader_2.54mm:PinHeader_2x06_P2.54mm_Horizontal | H4M/MDK mirrored 2x6
J16,J17,J18,J19 | 4 | Conn_Coaxial | DNP |  | Excluded from board | PCM_SparkFun-Connector:1x02
JP_H4M_3V1 | 1 | 3V3_ISO |  |  |  | PCM_SparkFun-Connector:1x02_P2.54mm
JP_VBAT_H4M1 | 1 | VBAT_ISO |  |  |  | PCM_SparkFun-Connector:1x02_P2.54mm
J_AS1 | 1 | AS5600_LANDING |  |  |  | Connector:GROVE-HW4-SMD-2.0
J_BMI1 | 1 | BMI160_LANDING |  |  |  | Connector:GROVE-HW4-SMD-2.0
J_BMM1 | 1 | BMM150_LANDING |  |  |  | Connector:GROVE-HW4-SMD-2.0
J_BMP1 | 1 | BMP280_LANDING |  |  |  | Connector:GROVE-HW4-SMD-2.0
J_DISP1 | 1 | DISP_SPI_9P |  |  |  | Connector_PinHeader_2.54mm:PinHeader_1x09_P2.54mm_Vertical | http://pan.baidu.com/s/11Y990
J_SHT1 | 1 | SHT31_LANDING |  |  |  | Connector:GROVE-HW4-SMD-2.0
J_WIO1,J_WIO2,J_WIO3,J_WIO4 | 4 | WioSX1262_Shield_Socket |  |  |  | New_XIAO_Series_Footprints:XIAO-ESP32-S3-DIP
L1 | 1 | 1.5uH |  |  |  | PCM_SparkFun-Coil:0805 | https://mm.digikey.com/Volume0/opasdata/d220001/medias/docus/1221/MBKK2012T1R0M_SS.pdf
R1,R_H4M_SCL1,R_H4M_SDA1 | 3 | 33 |  |  |  | PCM_SparkFun-Resistor:R_0402_1005Metric | https://www.vishay.com/docs/20035/dcrcwe3.pdf
R2 | 1 | 1k |  |  |  | PCM_SparkFun-Resistor:R_0402_1005Metric | https://www.vishay.com/docs/20035/dcrcwe3.pdf
R3,R7 | 2 | 1k |  |  |  | PCM_SparkFun-Resistor:R_0603_1608Metric | https://www.vishay.com/docs/20035/dcrcwe3.pdf
R4 | 1 | 560k |  |  |  | PCM_SparkFun-Resistor:R_0402_1005Metric | https://www.vishay.com/docs/20035/dcrcwe3.pdf
R5 | 1 | 2.0k |  |  |  | PCM_SparkFun-Resistor:R_0402_1005Metric | https://www.vishay.com/docs/20035/dcrcwe3.pdf
R6 | 1 | 100k |  |  |  | PCM_SparkFun-Resistor:R_0603_1608Metric | https://www.vishay.com/docs/20035/dcrcwe3.pdf
R8 | 1 | 0 |  |  |  | PCM_SparkFun-Resistor:R_0603_1608Metric | https://industrial.panasonic.com/cdbs/www-data/pdf/RDN0000/AOA0000C313.pdf
R9,R10,R11,R12,R13,R14,R15,R16,R17,R18,R19,R20,R21,R22,R23,R24,R25,R26,R27,R28,R29,R30,R31,R32,R33,R36,R37,R38,R39,R40,R41 | 31 | 10k |  |  |  | PCM_SparkFun-Resistor:R_0603_1608Metric | https://www.vishay.com/docs/20035/dcrcwe3.pdf
R34,R35 | 2 | R_0603 |  |  |  | PCM_Resistor_SMD_AKL:R_0603_1608Metric
R42,R43,R44 | 3 | 330 |  |  |  | PCM_SparkFun-Resistor:R_0603_1608Metric | https://www.vishay.com/docs/20035/dcrcwe3.pdf
SC1 | 1 | Solar_Cells |  |  |  | Connector_PinHeader_2.54mm:PinHeader_1x02_P2.54mm_Vertical
ST1,ST2,ST3 | 3 | Standoff |  |  |  | PCM_SparkFun-Hardware:Standoff_Reflow-M3.0
ST4 | 1 | Standoff |  |  | Excluded from board | PCM_SparkFun-Hardware:Standoff_Reflow-M3.0
TP1 | 1 | TestPoint |  |  |  | PCM_SparkFun-Connector:TestPoint-0.5mm
TP_H4M_3V1,TP_H4M_SCL1,TP_H4M_SDA1,TP_VBAT_H4M1 | 4 | 0.5mm |  |  |  | PCM_SparkFun-Connector:TestPoint-0.5mm
U1 | 1 | TPS63020DSJR |  |  |  | TPS63020:DSJ14_2P85X1P58 | TPS63020DSJR
U2 | 1 | CN3170 |  |  |  | Package_SO:SOIC-8-1EP_3.9x4.9mm_P1.27mm_EP2.41x3.3mm_ThermalVias | http://www.consonance-elec.com/en/static/upload/file/20221107/1667805770192920.pdf
U3 | 1 | XIAO-S3-Plus |  |  |  | Seeed_Xiao:XIAO-ESP32-S3-Plus-SMD
U4 | 1 | TCA9548APWR |  |  |  | Package_SO:TSSOP-24_4.4x7.8mm_P0.65mm | http://www.ti.com/lit/ds/symlink/tca9548a.pdf
U5 | 1 | MCP23017x-x-SS |  |  |  | Package_SO:SSOP-28_5.3x10.2mm_P0.65mm | https://ww1.microchip.com/downloads/aemDocuments/documents/APID/ProductDocuments/DataSheets/MCP23017-Data-Sheet-DS20001952.pdf
WIO1,WIO2,WIO3,WIO4 | 4 | WIO_LANDING_12P |  |  | Excluded from board | Wio:Wio-SX1262-12P

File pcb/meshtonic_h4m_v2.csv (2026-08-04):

Designator | Manufacturer Part Number or Seeed SKU | Qty | Link
C1,C2,C8,C10,C12,C14 | TACL106M006XTA | 6 | https://www.digikey.com/en/products/detail/kyocera-avx/TACL106M006XTA/3885426
C3,C4,C5 | GRM188R60J226MEA0D | 3 | https://www.digikey.com/en/products/detail/murata-electronics/GRM188R60J226MEA0D/4280542
C6,C7,C9,C11,C13,C15,C18 | 302010165 | 7 | https://www.seeedstudio.com/opl.html
C16,C17 | 302010138 | 2 | https://www.seeedstudio.com/opl.html
D1 | XZMDK68W-2 | 1 | https://www.sunledusa.com/products/spec/XZMDK68W-2.pdf
D2,D3 | 1N5819-E3/54 | 2 | https://www.digikey.com/en/products/detail/vishay-general-semiconductor-diodes-division/1N5819-E3-54/2799665
D4,D5 | IN-S126ATG | 2 | https://www.inolux-corp.com/datasheet/SMDLED/Mono%20Color%20Top%20View/IN-S126AT%20Series_V1.0.pdf
D6,D7,D8 | 304090042 | 3 | https://www.seeedstudio.com/opl.html
J1,J3,J4,J5,J6,J7 | 320110033 | 6 | https://www.seeedstudio.com/opl.html
J2 | 320110034 | 1 | https://www.seeedstudio.com/opl.html
J8,J_AS1,J_BMI1,J_BMM1,J_BMP1,J_SHT1 | 1125S-SMT-4P | 6 | https://statics3.seeedstudio.com/fusion/opl/datasheet/320110030.pdf
J9,J10,J11,JP_H4M_3V1,JP_VBAT_H4M1,J13,SC1 | 320020016 | 7 | https://www.seeedstudio.com/opl.html
J12 | S2B-PH-SM4-TB(LF)(SN) | 1 | https://www.digikey.com/en/products/detail/jst-sales-america-inc/S2B-PH-SM4-TB-LF-SN/926633
J14 | TF-01 | 1 | https://statics3.seeedstudio.com/fusion/opl/datasheet/320090008.pdf
J15 | 68021-212HLF | 1 | https://www.digikey.com/en/products/detail/amphenol-icc-fci/68021-212HLF/1535637
J_DISP1 | PRPC009SAAN-RC | 1 | https://www.digikey.com/en/products/detail/sullins-connector-solutions/PRPC009SAAN-RC/2775213
L1 | MBKK2012T1R5M | 1 | https://www.digikey.com/en/products/detail/taiyo-yuden/MBKK2012T1R5M/5035317
R1,R_H4M_SCL1,R_H4M_SDA1 | RC0402JR-0733RL | 3 | https://www.digikey.com/en/products/detail/yageo/RC0402JR-0733RL/727310
R2 | 301010006 | 1 | https://www.seeedstudio.com/opl.html
R3,R7 | 301010291 | 2 | https://www.seeedstudio.com/opl.html
R4 | RC0402JR-07560KL | 1 | https://www.digikey.com/en/products/detail/yageo/RC0402JR-07560KL/5918752
R5 | RC0402JR-072KL | 1 | https://www.digikey.com/en/products/detail/yageo/RC0402JR-072KL/5918740
R6 | 301010089 | 1 | https://www.seeedstudio.com/opl.html
R8,R34 | 301010292 | 2 | https://www.seeedstudio.com/opl.html
R9,R10,R11,R12,R13,R14,R15,R16,R17,R18,R19,R20,R21,R22,R23,R24,R25,R26,R27,R28,R29,R30,R31,R32,R33,R35,R36,R37,R38,R39,R40,R41,R45 | 301010293 | 33 | https://www.seeedstudio.com/opl.html
R42,R43,R44 | 301010300 | 3 | https://www.seeedstudio.com/opl.html
ST1,ST2,ST3 | 9774030360R | 3 | https://www.digikey.com/en/products/detail/w%C3%BCrth-elektronik/9774030360R/4810228
U1 | TPS63020DSJR | 1 | https://www.ti.com/product/TPS63020
U2 | CN3170 | 1 | http://www.consonance-elec.com/en/static/upload/file/20221107/1667805770192920.pdf
U3 | 102010671 | 1 | https://www.seeedstudio.com/Seeed-Studio-XIAO-ESP32S3-Plus-p-6361.html
U4 | TCA9548APWR | 1 | https://www.ti.com/product/TCA9548A
U5 | MCP23017-E/SS | 1 | https://www.microchip.com/en-us/product/mcp23017

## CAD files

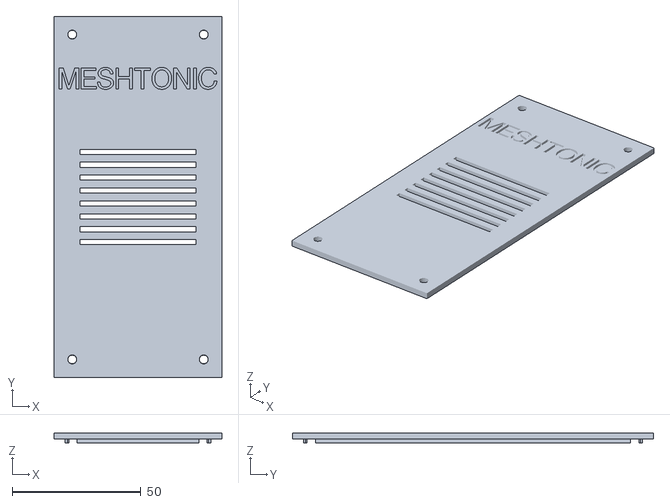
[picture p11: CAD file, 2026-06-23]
case/enclosure_lid_65x140.stl
65.0 x 140.0 x 4.00

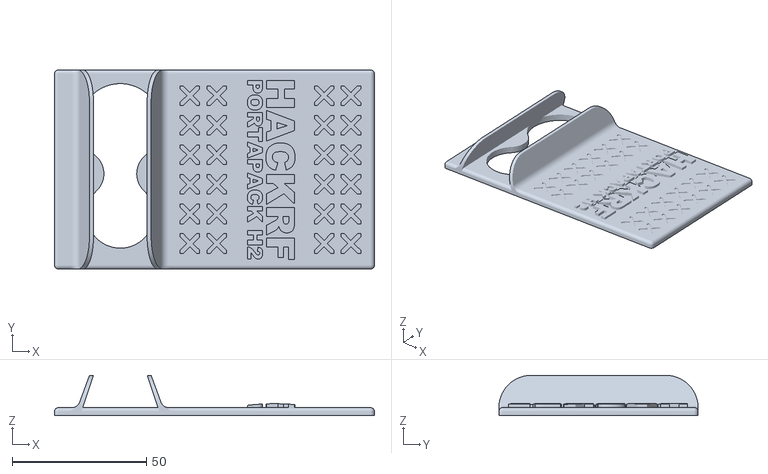
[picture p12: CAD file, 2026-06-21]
firmwares/mayhem-firmware/hardware/portapack_h2/3d_printed/cover/revisited_cover.stl
119.2 x 74.2 x 15.0

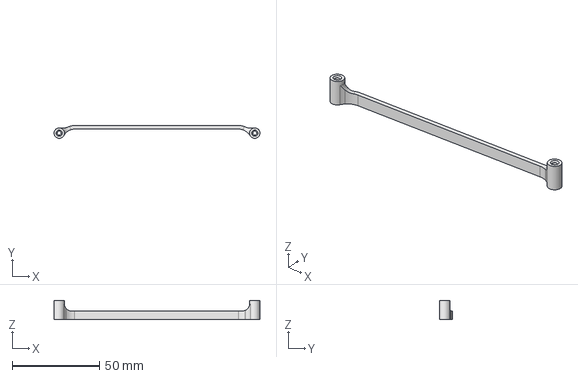
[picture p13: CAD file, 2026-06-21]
firmwares/mayhem-firmware/hardware/portapack_h2/3d_printed/enclosure/revisited_support.stp
118.3 x 7.32 x 11.0 mm

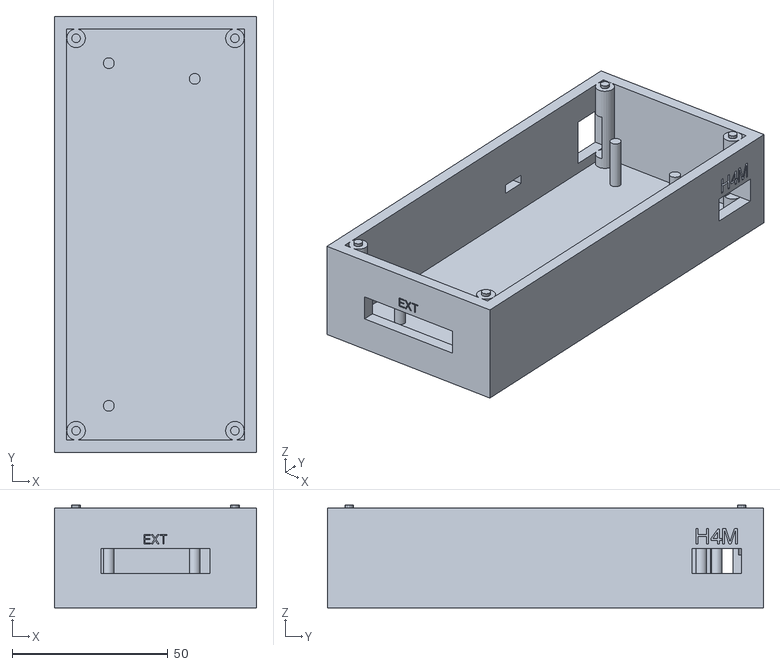
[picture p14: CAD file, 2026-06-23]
case/enclosure_base_65x140x32.stl
65.0 x 140.0 x 33.0

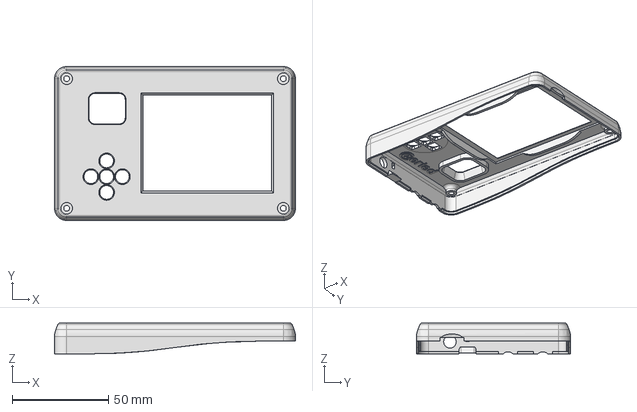
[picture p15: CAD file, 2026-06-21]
firmwares/mayhem-firmware/hardware/portapack_h2/3d_printed/enclosure/revisited_up.stp
124.9 x 79.8 x 15.9 mm

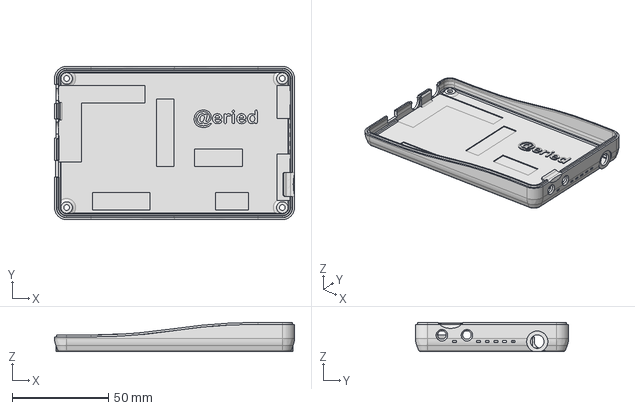
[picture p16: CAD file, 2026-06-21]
firmwares/mayhem-firmware/hardware/portapack_h2/3d_printed/enclosure/revisited_down.stp
124.9 x 79.8 x 15.2 mm

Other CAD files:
firmwares/mayhem-firmware/hackrf/hardware/jawbreaker/SoBv1_DP17298/SoBv1-DP17298-jawbreaker-Bottom.skp
firmwares/mayhem-firmware/hackrf/hardware/jawbreaker/SoBv1_DP17298/SoBv1-DP17298-jawbreaker-Top.skp
firmwares/mayhem-firmware/hardware/portapack_h2/3d_printed/enclosure/revisited_down.stl
firmwares/mayhem-firmware/hardware/portapack_h2/3d_printed/enclosure/revisited_support.stl
firmwares/mayhem-firmware/hardware/portapack_h2/3d_printed/enclosure/revisited_up.stl

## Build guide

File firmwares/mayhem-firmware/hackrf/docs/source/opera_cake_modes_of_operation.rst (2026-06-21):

==================
Modes of Operation
==================

Opera Cake supports three modes of operation: ``manual``, ``frequency``, and ``time``. The operating mode can be set with the ``--mode`` or ``-m`` option, and the active operating mode is displayed with the ``--list`` or ``-l`` option.

Manual Mode
~~~~~~~~~~~

The default mode of operation is ``manual``. In manual mode, fixed port connections are configured with the ``-a`` and ``-b`` options as in the :ref:`port configuration examples <portconfiguration>`. If the operating mode has been changed, it can be changed back to manual mode with:

.. code-block:: sh

	hackrf_operacake -m manual

Frequency Mode
~~~~~~~~~~~~~~

In frequency mode, the A0 port connection switches automatically whenever the HackRF is tuned to a different frequency. This is useful when antennas for different frequency bands are connected to various ports.

The bands are specified in priority order. The final band specified will be used for frequencies not covered by the other bands specified.

To assign frequency bands to ports you must use the ``-f <port:min:max>`` option for each band, with the minimum and maximum frequencies specified in MHz. For example, to use port A1 for 100 MHz to 600 MHz, A3 for 600 MHz to 1200 MHz, and B2 for 0 MHz to 4 GHz:

.. code-block:: sh

	hackrf_operacake -m frequency -f A1:100:600 -f A3:600:1200 -f B2:0:4000

If tuning to precisely 600 MHz, A1 will be used as it is listed first. Tuning to any frequency over 4 GHz will use B2 as it is the last listed and therefore the default port.

Only the A0 port connection is specified in frequency mode. Whenever the A0 connection is switched, the B0 connection is also switched to the secondary port mirroring A0's secondary port. For example, when A0 switches to B2, B0 is switched to A2.

Once configured, an Opera Cake will remain in frequency mode until the mode is reconfigured or until the HackRF One is reset. You can pre-configure the Opera Cake in frequency mode, and the automatic switching will continue to work while using other software.

Although multiple Opera Cakes on a single HackRF One may be set to frequency mode at the same time, they share a single switching plan. This can be useful, for example, for a filter bank consisting of eight filters.

Time Mode
~~~~~~~~~

In time mode, the A0 port connection switches automatically over time, counted in units of the sample period. This is useful for experimentation with pseudo-doppler direction finding.

To cycle through four ports, one port every 1000 samples:

.. code-block:: none

	hackrf_operacake -m time -t A1:1000 -t A2:1000 -t A3:1000 -t A4:1000

When the duration on multiple ports is the same, the ``-w`` option can be used to set the default dwell time:

.. code-block:: none

	hackrf_operacake --mode time -w 1000 -t A1 -t A2 -t A3 -t A4

Only the A0 port connection is specified in time mode. Whenever the A0 connection is switched, the B0 connection is switched to the secondary port mirroring A0's secondary port. For example, when A0 switches to B2, B0 is switched to A2.

Once configured, an Opera Cake will remain in time mode until the mode is reconfigured or until the HackRF One is reset. You can pre-configure the Opera Cake in time mode, and the automatic switching will continue to work while using other software.

Although multiple Opera Cakes on a single HackRF One may be set to time mode at the same time, they share a single switching plan.

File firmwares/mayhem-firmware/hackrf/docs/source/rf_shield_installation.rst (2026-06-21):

===============================================
RF Shield Installation Instructions
===============================================

HackRF Pro ships with an RF shield as standard.

Official Great Scott Gadgets HackRF Ones do not come from the factory with an RF shield installed around the radio section of the PCB. They do, however, have pads in place so that one may be installed if a user has a reason and an inclination to do so. The reason that they do not come preinstalled is that early testing revealed that the RF shield did little to improve the performance of the HackRF One. The recommended RF shield is the BMI-S-230-F-R (frame) with the BMI-S-230-C (shield). A two part RF shield is recommended because the shield section can be removed to allow access to the RF section of the HackRF One. This can be important if it becomes necessary to probe any part of the RF section, or to replace any parts of the RF section. However, even with a two part RF shield, it can be difficult to access the RF section of the HackRF One in certain situations. The following steps are a basic set of instructions for installing a RF shield on a HackRF One.

**CAUTION: Soldering a RF shield onto a HackRF One comes with a certain amount of risk. Beyond the inherent risks of soldering itself, this process may damage the HackRF One and no warranty is available to cover damage incurred from this process. If you do choose to install a RF shield on your HackRF One please proceed with caution.**

1. Remove the HackRF One from the injection molded plastic case. 

  **BE WARNED: Opening the plastic case of your HackRF One will most likely destroy the tabs that hold it together.**  

  Instructions for removing a HackRF One from its case can be found :ref:`here <open_your_hackrf_one>`.

2. Prepare the HackRF One PCB for soldering on the shield frame, by adding flux to the RF shield pads around the radio section on the PCB.

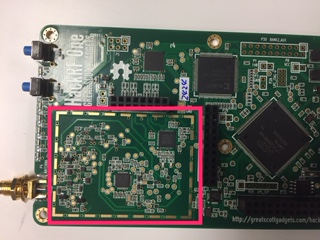
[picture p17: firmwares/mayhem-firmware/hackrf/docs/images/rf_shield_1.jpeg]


3. Place the RF shield frame on the HackRF One, aligning it so that it makes contact with all of the pads around the RF section of the board.

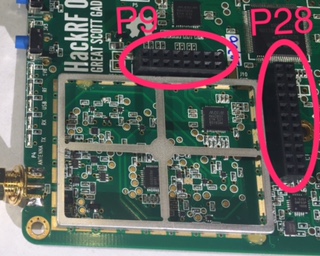
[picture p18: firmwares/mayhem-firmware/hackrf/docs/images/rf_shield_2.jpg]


4. Solder the shield to one pad to anchor it to the H1. Visually inspect the frame to assure that it is still aligned properly.

+---------------------------------------+---------------------------------------+
| 
+---------------------------------------+---------------------------------------+

5. Connect the frame to another pad on the opposite side from the first connection. Again, check that the frame is still aligned properly.

+---------------------------------------+---------------------------------------+
| 
+---------------------------------------+---------------------------------------+

6. Connect at least one more pad, and then remove the pick and place bridge from the frame. *Removing the pick and place bridge is optional, but it is recommended.*

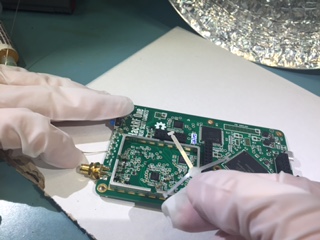
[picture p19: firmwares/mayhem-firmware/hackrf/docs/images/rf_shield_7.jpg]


7. Continue soldering the rest of the pads to the frame.

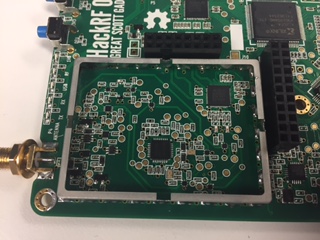
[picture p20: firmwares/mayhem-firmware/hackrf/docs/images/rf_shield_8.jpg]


8. Clean the flux and soldering residue with the appropriate solvent for the type of flux used. Be sure to let the HackRF One dry completely before plugging it in to a power source.

9. Place the RF shield onto the frame and snap it into place.

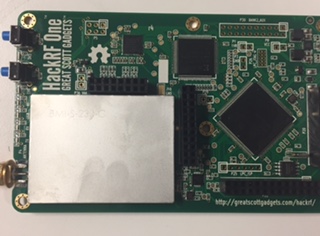
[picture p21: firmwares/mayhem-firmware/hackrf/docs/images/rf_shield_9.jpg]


10. If desired, put the HackRF One back into the plastic case, if it is still able to click together.

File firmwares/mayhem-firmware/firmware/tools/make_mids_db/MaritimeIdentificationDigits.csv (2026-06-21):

Digit | Allocated to
201 | Albania (Republic of)
202 | Andorra (Principality of)
203 | Austria
204 | Portugal - Azores
205 | Belgium
206 | Belarus (Republic of)
207 | Bulgaria (Republic of)
208 | Vatican City State
209 | Cyprus (Republic of)
210 | Cyprus (Republic of)
211 | Germany (Federal Republic of)
212 | Cyprus (Republic of)
213 | Georgia
214 | Moldova (Republic of)
215 | Malta
216 | Armenia (Republic of)
218 | Germany (Federal Republic of)
219 | Denmark
220 | Denmark
224 | Spain
225 | Spain
226 | France
227 | France
228 | France
229 | Malta
230 | Finland
231 | Denmark - Faroe Islands
232 | United Kingdom of Great Britain and Northern Ireland
233 | United Kingdom of Great Britain and Northern Ireland
234 | United Kingdom of Great Britain and Northern Ireland
235 | United Kingdom of Great Britain and Northern Ireland
236 | United Kingdom of Great Britain and Northern Ireland - Gibraltar
237 | Greece
238 | Croatia (Republic of)
239 | Greece
240 | Greece
241 | Greece
242 | Morocco (Kingdom of)
243 | Hungary
244 | Netherlands (Kingdom of the)
245 | Netherlands (Kingdom of the)
246 | Netherlands (Kingdom of the)
247 | Italy
248 | Malta
249 | Malta
250 | Ireland
251 | Iceland
252 | Liechtenstein (Principality of)
253 | Luxembourg
254 | Monaco (Principality of)
255 | Portugal - Madeira
256 | Malta
257 | Norway
258 | Norway
259 | Norway
261 | Poland (Republic of)
262 | Montenegro
263 | Portugal
264 | Romania
265 | Sweden
266 | Sweden
267 | Slovak Republic
268 | San Marino (Republic of)
269 | Switzerland (Confederation of)
270 | Czech Republic
271 | Turkey
272 | Ukraine
273 | Russian Federation
274 | North Macedonia (Republic of)
275 | Latvia (Republic of)
276 | Estonia (Republic of)
277 | Lithuania (Republic of)
278 | Slovenia (Republic of)
279 | Serbia (Republic of)
301 | United Kingdom of Great Britain and Northern Ireland - Anguilla
303 | United States of America - Alaska (State of)
304 | Antigua and Barbuda
305 | Antigua and Barbuda
306 | Netherlands (Kingdom of the) - Bonaire, Sint Eustatius and Saba
306 | Netherlands (Kingdom of the) - Curaçao
306 | Netherlands (Kingdom of the) - Sint Maarten (Dutch part)
307 | Netherlands (Kingdom of the) - Aruba
308 | Bahamas (Commonwealth of the)
309 | Bahamas (Commonwealth of the)
310 | United Kingdom of Great Britain and Northern Ireland - Bermuda
311 | Bahamas (Commonwealth of the)
312 | Belize
314 | Barbados
316 | Canada
319 | United Kingdom of Great Britain and Northern Ireland - Cayman Islands
321 | Costa Rica
323 | Cuba
325 | Dominica (Commonwealth of)
327 | Dominican Republic
329 | France - Guadeloupe (French Department of)
330 | Grenada
331 | Denmark - Greenland
332 | Guatemala (Republic of)
334 | Honduras (Republic of)
336 | Haiti (Republic of)
338 | United States of America
339 | Jamaica
341 | Saint Kitts and Nevis (Federation of)
343 | Saint Lucia
345 | Mexico
347 | France - Martinique (French Department of)
348 | United Kingdom of Great Britain and Northern Ireland - Montserrat
350 | Nicaragua
351 | Panama (Republic of)
352 | Panama (Republic of)
353 | Panama (Republic of)
354 | Panama (Republic of)
355 | Panama (Republic of)
356 | Panama (Republic of)
357 | Panama (Republic of)
358 | United States of America - Puerto Rico
359 | El Salvador (Republic of)
361 | France - Saint Pierre and Miquelon (Territorial Collectivity of)
362 | Trinidad and Tobago
364 | United Kingdom of Great Britain and Northern Ireland - Turks and Caicos Islands
366 | United States of America
367 | United States of America
368 | United States of America
369 | United States of America
370 | Panama (Republic of)
371 | Panama (Republic of)
372 | Panama (Republic of)
373 | Panama (Republic of)
374 | Panama (Republic of)
375 | Saint Vincent and the Grenadines
376 | Saint Vincent and the Grenadines
377 | Saint Vincent and the Grenadines
378 | United Kingdom of Great Britain and Northern Ireland - British Virgin Islands
379 | United States of America - United States Virgin Islands
401 | Afghanistan
403 | Saudi Arabia (Kingdom of)
405 | Bangladesh (People's Republic of)
408 | Bahrain (Kingdom of)
410 | Bhutan (Kingdom of)
412 | China (People's Republic of)
413 | China (People's Republic of)
414 | China (People's Republic of)
416 | China (People's Republic of) - Taiwan (Province of China)
417 | Sri Lanka (Democratic Socialist Republic of)
419 | India (Republic of)
422 | Iran (Islamic Republic of)
423 | Azerbaijan (Republic of)
425 | Iraq (Republic of)
428 | Israel (State of)
431 | Japan
432 | Japan
434 | Turkmenistan
436 | Kazakhstan (Republic of)
437 | Uzbekistan (Republic of)
438 | Jordan (Hashemite Kingdom of)
440 | Korea (Republic of)
441 | Korea (Republic of)
443 | State of Palestine (In accordance with Resolution 99 Rev. Dubai, 2018)
445 | Democratic People's Republic of Korea
447 | Kuwait (State of)
450 | Lebanon
451 | Kyrgyz Republic
453 | China (People's Republic of) - Macao (Special Administrative Region of China)
455 | Maldives (Republic of)
457 | Mongolia
459 | Nepal (Federal Democratic Republic of)
461 | Oman (Sultanate of)
463 | Pakistan (Islamic Republic of)
466 | Qatar (State of)
468 | Syrian Arab Republic
470 | United Arab Emirates
471 | United Arab Emirates
472 | Tajikistan (Republic of)
473 | Yemen (Republic of)
475 | Yemen (Republic of)
477 | China (People's Republic of) - Hong Kong (Special Administrative Region of China)
478 | Bosnia and Herzegovina
501 | France - Adelie Land
503 | Australia
506 | Myanmar (Union of)
508 | Brunei Darussalam
510 | Micronesia (Federated States of)
511 | Palau (Republic of)
512 | New Zealand
514 | Cambodia (Kingdom of)
515 | Cambodia (Kingdom of)
516 | Australia - Christmas Island (Indian Ocean)
518 | New Zealand - Cook Islands
520 | Fiji (Republic of)
523 | Australia - Cocos (Keeling) Islands
525 | Indonesia (Republic of)
529 | Kiribati (Republic of)
531 | Lao People's Democratic Republic
533 | Malaysia
536 | United States of America - Northern Mariana Islands (Commonwealth of the)
538 | Marshall Islands (Republic of the)
540 | France - New Caledonia
542 | New Zealand - Niue
544 | Nauru (Republic of)
546 | France - French Polynesia
548 | Philippines (Republic of the)
550 | Timor-Leste (Democratic Republic of)
553 | Papua New Guinea
555 | United Kingdom of Great Britain and Northern Ireland - Pitcairn Island
557 | Solomon Islands
559 | United States of America - American Samoa
561 | Samoa (Independent State of)
563 | Singapore (Republic of)
564 | Singapore (Republic of)
565 | Singapore (Republic of)
566 | Singapore (Republic of)
567 | Thailand
570 | Tonga (Kingdom of)
572 | Tuvalu
574 | Viet Nam (Socialist Republic of)
576 | Vanuatu (Republic of)
577 | Vanuatu (Republic of)
578 | France - Wallis and Futuna Islands
601 | South Africa (Republic of)
603 | Angola (Republic of)
605 | Algeria (People's Democratic Republic of)
607 | France - Saint Paul and Amsterdam Islands
608 | United Kingdom of Great Britain and Northern Ireland - Ascension Island
609 | Burundi (Republic of)
610 | Benin (Republic of)
611 | Botswana (Republic of)
612 | Central African Republic
613 | Cameroon (Republic of)
615 | Congo (Republic of the)
616 | Comoros (Union of the)
617 | Cabo Verde (Republic of)
618 | France - Crozet Archipelago
619 | Côte d'Ivoire (Republic of)
620 | Comoros (Union of the)
621 | Djibouti (Republic of)
622 | Egypt (Arab Republic of)
624 | Ethiopia (Federal Democratic Republic of)
625 | Eritrea
626 | Gabonese Republic
627 | Ghana
629 | Gambia (Republic of the)
630 | Guinea-Bissau (Republic of)
631 | Equatorial Guinea (Republic of)
632 | Guinea (Republic of)
633 | Burkina Faso
634 | Kenya (Republic of)
635 | France - Kerguelen Islands
636 | Liberia (Republic of)
637 | Liberia (Republic of)
638 | South Sudan (Republic of)
642 | Libya (State of)
644 | Lesotho (Kingdom of)
645 | Mauritius (Republic of)
647 | Madagascar (Republic of)
649 | Mali (Republic of)
650 | Mozambique (Republic of)
654 | Mauritania (Islamic Republic of)
655 | Malawi
656 | Niger (Republic of the)
657 | Nigeria (Federal Republic of)
659 | Namibia (Republic of)
660 | France - Reunion (French Department of)
661 | Rwanda (Republic of)
662 | Sudan (Republic of the)
663 | Senegal (Republic of)
664 | Seychelles (Republic of)
665 | United Kingdom of Great Britain and Northern Ireland - Saint Helena
666 | Somalia (Federal Republic of)
667 | Sierra Leone
668 | Sao Tome and Principe (Democratic Republic of)
669 | Eswatini (Kingdom of)
670 | Chad (Republic of)
671 | Togolese Republic
672 | Tunisia
674 | Tanzania (United Republic of)
675 | Uganda (Republic of)
676 | Democratic Republic of the Congo
677 | Tanzania (United Republic of)
678 | Zambia (Republic of)
679 | Zimbabwe (Republic of)
701 | Argentine Republic
710 | Brazil (Federative Republic of)
720 | Bolivia (Plurinational State of)
725 | Chile
730 | Colombia (Republic of)
735 | Ecuador
740 | United Kingdom of Great Britain and Northern Ireland - Falkland Islands (Malvinas)
745 | France - Guiana (French Department of)
750 | Guyana
755 | Paraguay (Republic of)
760 | Peru
765 | Suriname (Republic of)
770 | Uruguay (Eastern Republic of)
775 | Venezuela (Bolivarian Republic of)

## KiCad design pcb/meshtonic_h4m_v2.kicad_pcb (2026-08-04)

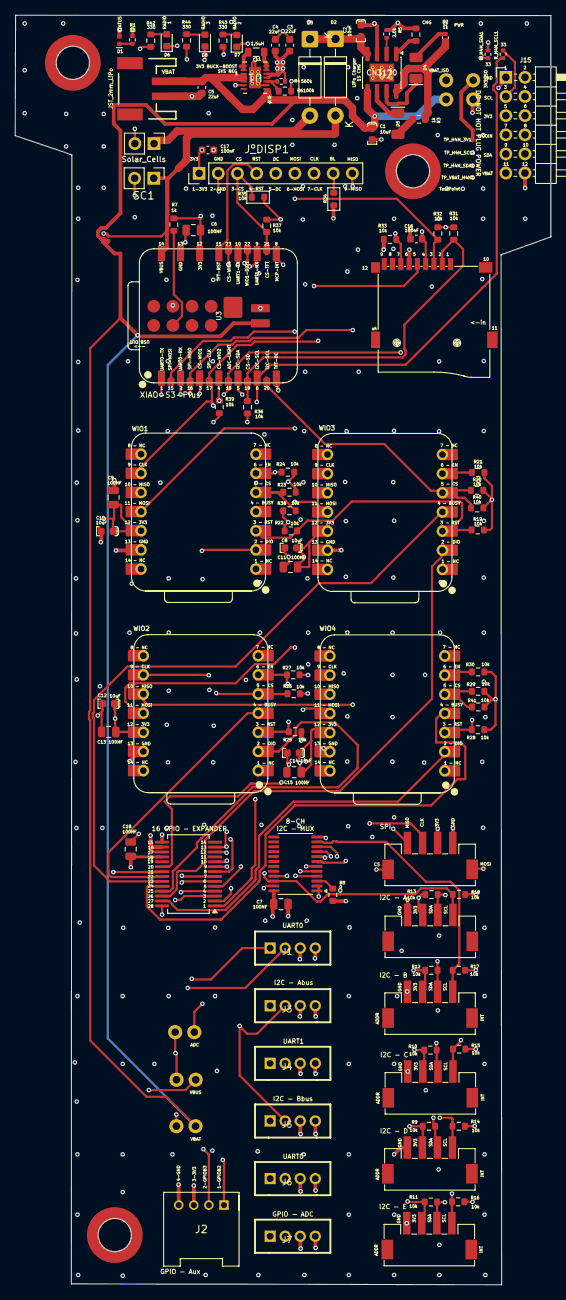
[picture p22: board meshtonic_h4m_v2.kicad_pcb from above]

Board: 6 copper layers, 71.1 x 168.4 mm, 115 parts (0 on the bottom side), 70 nets.

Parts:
C1, C2, C8, C10, C12, C14: 10uF; C_0603_1608Metric_Polar
C3, C4, C5: 22uF; C_0603_1608Metric
C6, C7, C9, C11, C13, C15, C18: CERAMIC-100NF-50V-10%-X7R_0805_; C_0805_2012Metric
C16, C17: 100nF; C_0603_1608Metric
D1: Red; LED_0402_1005Metric_Red
D2, D3: 1N5819; D_DO-41_SOD81_P10.16mm_Horizontal
D4, D5: Green; LED_1206_3216Metric_Green
D6, D7, D8: LED-SMD-RED-DIFFUSED_0603_; LED_0603_1608Metric
J1, J3, J4, J5, J6, J7: GROVE-CONNECTOR-DIP_4P-2.0_; GROVE-HW4-2.0
J2: GROVE-CONNECTOR-DIP-90D_4P-2.0_; GROVE-HW4-2.0-90D
J8: GROVE-CONNECTOR-SMD_4+2P-2.0_; GROVE-HW4-SMD-2.0
J9, J10, J11: Conn_01x02; 1x02_P2.54mm
J12: JST_2mm_LiPo; JST_1x02_P2.0mm_Horizontal_SMD
J13: Screw_Terminal_01x02; PinHeader_1x02_P2.54mm_Vertical
J14: Micro_SD_Card_passive_clk; MICRO-SD9+4P-SMD-16.1X14.5X1.85MM
J15: H4M_2x6_MDK; PinHeader_2x06_P2.54mm_Horizontal
JP_H4M_3V1: 3V3_ISO; 1x02_P2.54mm
JP_VBAT_H4M1: VBAT_ISO; 1x02_P2.54mm
J_AS1: AS5600_LANDING; GROVE-HW4-SMD-2.0
J_BMI1: BMI160_LANDING; GROVE-HW4-SMD-2.0
J_BMM1: BMM150_LANDING; GROVE-HW4-SMD-2.0
J_BMP1: BMP280_LANDING; GROVE-HW4-SMD-2.0
J_DISP1: DISP_SPI_9P; PinHeader_1x09_P2.54mm_Vertical
J_SHT1: SHT31_LANDING; GROVE-HW4-SMD-2.0
J_WIO1, J_WIO2, J_WIO3, J_WIO4: WioSX1262_Shield_Socket; XIAO-ESP32-S3-DIP
L1: 1.5uH; 0805
R1: 33; R_0402_1005Metric
R2: 1k; R_0402_1005Metric
R3, R7: 1k; R_0603_1608Metric
R4: 560k; R_0402_1005Metric
R5: 2.0k; R_0402_1005Metric
R6: 100k; R_0603_1608Metric
R8, R34: 0; R_0603_1608Metric
R9, R10, R11, R12, R13, R14, R15, R16, R17, R18, R19, R20, R21, R22, R23, R24, R25, R26, R27, R28, R29, R30, R31, R32, R33, R35, R36, R37, R38, R39, R40, R41, R45: 10k; R_0603_1608Metric
R42, R43, R44: 330; R_0603_1608Metric
R_H4M_SCL1, R_H4M_SDA1: 33; R_0402_1005Metric
SC1: Solar_Cells; PinHeader_1x02_P2.54mm_Vertical
ST1, ST2, ST3: Standoff; Standoff_Reflow-M3.0
TP1: TestPoint; TestPoint-0.5mm
TP_H4M_3V1, TP_H4M_SCL1, TP_H4M_SDA1: 0.5mm; TestPoint-0.5mm
TP_VBAT_H4M1: 0.5mm; TestPoint-0.5mm
U1: TPS63020DSJR; DSJ14_2P85X1P58
U2: CN3170; SOIC-8-1EP_3.9x4.9mm_P1.27mm_EP2.41x3.3mm_ThermalVias
U3: XIAO-S3-Plus; XIAO-ESP32-S3-Plus-SMD
U4: TCA9548APWR; TSSOP-24_4.4x7.8mm_P0.65mm
U5: MCP23017x-x-SS; SSOP-28_5.3x10.2mm_P0.65mm

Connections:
3V3: C3.1, C4.1, C6.2, C7.1, C8.1, C9.1, C10.1, C11.1, C12.1, C13.1, C14.1, C15.1, C16.1, C17.2, C18.2, D1.2 (A), D6.1 (+), D7.1 (+), D8.1 (+), J1.3, J2.3, J3.3, J4.3, J5.3, J6.3, J7.3, J8.2, J14.4 (VDD), JP_H4M_3V1.2, J_AS1.3, J_BMI1.3, J_BMM1.3, J_BMP1.3, J_DISP1.1 (VCC), J_SHT1.3, J_WIO1.12, J_WIO2.12, J_WIO3.12, J_WIO4.12, R4.1, R7.2, R8.1, R9.1, R10.1, R11.1, R12.1, R13.1, R14.1, R15.1, R16.1, R17.1, R18.1, R19.2, R20.2, R21.2, R22.2, R23.2, R24.2, R25.2, R26.2, R27.2, R28.2, R29.2, R30.2, R31.2, R32.2, R33.2, R34.2, R35.2, R36.2, R37.2, R38.2, R39.2, R40.2, R41.2, U1.4 (VOUT), U1.5 (VOUT), U3.12 (3V3_OUT), U4.24 (VCC), U5.9 (V_{DD}), U5.18 (~RESET)
/Periferals/LED WIO 1: R42.1, U5.6 (GPB5)
/Periferals/LED WIO 2: R43.1, U5.7 (GPB6)
/Periferals/LED WIO 3: R44.1, U5.8 (GPB7)
/Power/VIN_CHG: C2.2, D2.1 (K), D3.1 (K), U2.4 (VIN)
ADC_LIGHT: J7.2, J11.1, TP1.1 (1_1), U3.18 (D14)
CS_GROVE: J8.6, U5.2 (GPB1)
CS_SD: J14.2 (DAT3/CD), R31.1, R36.1, U3.19 (D15)
CS_TFT: J_DISP1.3 (CS), R35.1, R37.1, U3.21 (D19)
CS_WIO1: J_WIO1.5, R23.1, R38.1, U3.3 (D2)
CS_WIO2: J_WIO2.5, R26.1, R39.1, U3.4 (D3)
CS_WIO3: J_WIO3.5, R20.1, R40.1, U3.20 (D16)
CS_WIO4: J_WIO4.5, R29.1, R41.1, U3.23 (D17)
GND: C1.2, C2.1, C3.2, C4.2, C5.1, C6.1, C7.2, C8.2, C9.2, C10.2, C11.2, C12.2, C13.2, C14.2, C15.2, C16.2, C17.1, C18.1, J1.4, J2.4, J3.4, J4.4, J5.4, J6.4, J7.4, J8.1, J9.2, J10.2, J11.2, J12.1 (-), J13.2, J14.6 (VSS), J15.1, J15.12, J_AS1.4, J_BMI1.4, J_BMM1.4, J_BMP1.4, J_DISP1.2 (GND), J_SHT1.4, J_WIO1.13, J_WIO2.13, J_WIO3.13, J_WIO4.13, R1.2, R5.1, R6.1, R45.2, SC1.2 (-), U1.2 (GND), U1.13 (PS/SYNC), U1.15 (EPAD), U2.3 (GND), U2.9 (GND), U3.13 (GND), U3.27 (GND), U3.33 (GND), U4.1 (A0), U4.2 (A1), U4.12 (GND), U4.21 (A2), U5.10 (V_{SS}), U5.15 (A0), U5.16 (A1), U5.17 (A2)
H4M_3V3: J15.5, J15.8, JP_H4M_3V1.1, TP_H4M_3V1.1 (1_1)
H4M_SCL: J15.3, J15.10, R_H4M_SCL1.1, TP_H4M_SCL1.1 (1_1)
H4M_SDA: J15.4, J15.9, R_H4M_SDA1.1, TP_H4M_SDA1.1 (1_1)
I2C_SCL: J3.1, J5.1, J_AS1.1, R18.2, R_H4M_SCL1.2, U3.6 (D5), U4.22 (SCL), U5.12 (SCK)
I2C_SDA: J3.2, J5.2, J_AS1.2, R13.2, R_H4M_SDA1.2, U3.5 (D4), U4.23 (SDA), U5.13 (SDA)
LORA_RST: J_WIO1.3, J_WIO2.3, J_WIO3.3, J_WIO4.3, R19.1, R22.1, R25.1, R28.1, U5.5 (GPB4)
MCP_GPA7: J7.1, U5.28 (GPA7)
MCP_GPB2: J2.1, U5.3 (GPB2)
MCP_GPB3: J2.2, U5.4 (GPB3)
MCP_INT: U3.8 (D7), U5.20 (INTA)
unnamed: D1.1 (K), R1.1
unnamed: D4.2 (A), R2.2
unnamed: D4.1 (K), U2.7 (~CHRG)
unnamed: D5.2 (A), R3.2
unnamed: D5.1 (K), U2.6 (~DONE)
unnamed: D6.2 (-), R42.2
unnamed: D7.2 (-), R43.2
unnamed: D8.2 (-), R44.2
unnamed: L1.1, U1.6 (L2), U1.7 (L2)
unnamed: L1.2, U1.8 (L1), U1.9 (L1)
unnamed: R4.2, R6.2, U1.3 (FB)
unnamed: R5.2, U2.2 (ISET)
unnamed: R45.1, U2.1 (TEMP)
unnamed: R7.1, U3.26 (EN)
unnamed: R8.2, U4.3 (~RESET)
SENS0_SCL: J_BMM1.1, R14.2, U4.5 (SC0)
SENS0_SDA: J_BMM1.2, R9.2, U4.4 (SD0)
SENS1_SCL: J_BMP1.1, R15.2, U4.7 (SC1)
SENS1_SDA: J_BMP1.2, R10.2, U4.6 (SD1)
SENS2_SCL: J_SHT1.1, R16.2, U4.9 (SC2)
SENS2_SDA: J_SHT1.2, R11.2, U4.8 (SD2)
SENS3_SCL: J_BMI1.1, R17.2, U4.11 (SC3)
SENS3_SDA: J_BMI1.2, R12.2, U4.10 (SD3)
SPI_CLK: J8.3, J14.5 (CLK), J_DISP1.7 (SCK), J_WIO1.9, J_WIO2.9, J_WIO3.9, J_WIO4.9, U3.17 (D13)
SPI_MISO: J8.4, J14.7 (DAT0), J_DISP1.9 (MISO), J_WIO1.10, J_WIO2.10, J_WIO3.10, J_WIO4.10, R33.1, U3.16 (D12)
SPI_MOSI: J8.5, J14.3 (CMD), J_DISP1.6 (MOSI), J_WIO1.11, J_WIO2.11, J_WIO3.11, J_WIO4.11, R32.1, U3.15 (D11)
TFT_BL: J_DISP1.8 (LED), R34.1
TFT_DC: J_DISP1.5 (D/C), U3.7 (D6)
TFT_RST: J_DISP1.4 (RESET), U3.11 (D10)
UART0_RX: J1.1, J6.1, U3.2 (D1)
UART0_TX: J1.2, J6.2, U3.1 (D0)
UART1_RX: J4.1, U3.9 (D8)
UART1_TX: J4.2, U3.10 (D9)
VBAT: C1.1, C5.2, J9.1, J12.2 (+), JP_VBAT_H4M1.2, R2.1, R3.1, U1.1 (VINA), U1.10 (VIN), U1.11 (VIN), U1.12 (EN), U2.5 (BAT), U2.8 (FB), U3.32 (VBAT)
VBAT_H4M: J15.2, J15.11, JP_VBAT_H4M1.1, TP_VBAT_H4M1.1 (1_1)
VBUS: D2.2 (A), D3.2 (A), J10.1, J13.1, SC1.1 (+), U3.14 (VBUS)
VCOIN_H4M: J15.6, J15.7
WIO1_BUSY: J_WIO1.4, U5.21 (GPA0)
WIO1_DIO1: J_WIO1.2, U3.22 (D18)
WIO2_BUSY: J_WIO2.4, U5.22 (GPA1)
WIO2_DIO1: J_WIO2.2, U5.25 (GPA4)
WIO3_BUSY: J_WIO3.4, U5.23 (GPA2)
WIO3_DIO1: J_WIO3.2, U5.26 (GPA5)
WIO4_BUSY: J_WIO4.4, U5.24 (GPA3)
WIO4_DIO1: J_WIO4.2, U5.27 (GPA6)
WIO_RF_SW_EN: J_WIO1.6, J_WIO2.6, J_WIO3.6, J_WIO4.6, R21.1, R24.1, R27.1, R30.1, U5.1 (GPB0)

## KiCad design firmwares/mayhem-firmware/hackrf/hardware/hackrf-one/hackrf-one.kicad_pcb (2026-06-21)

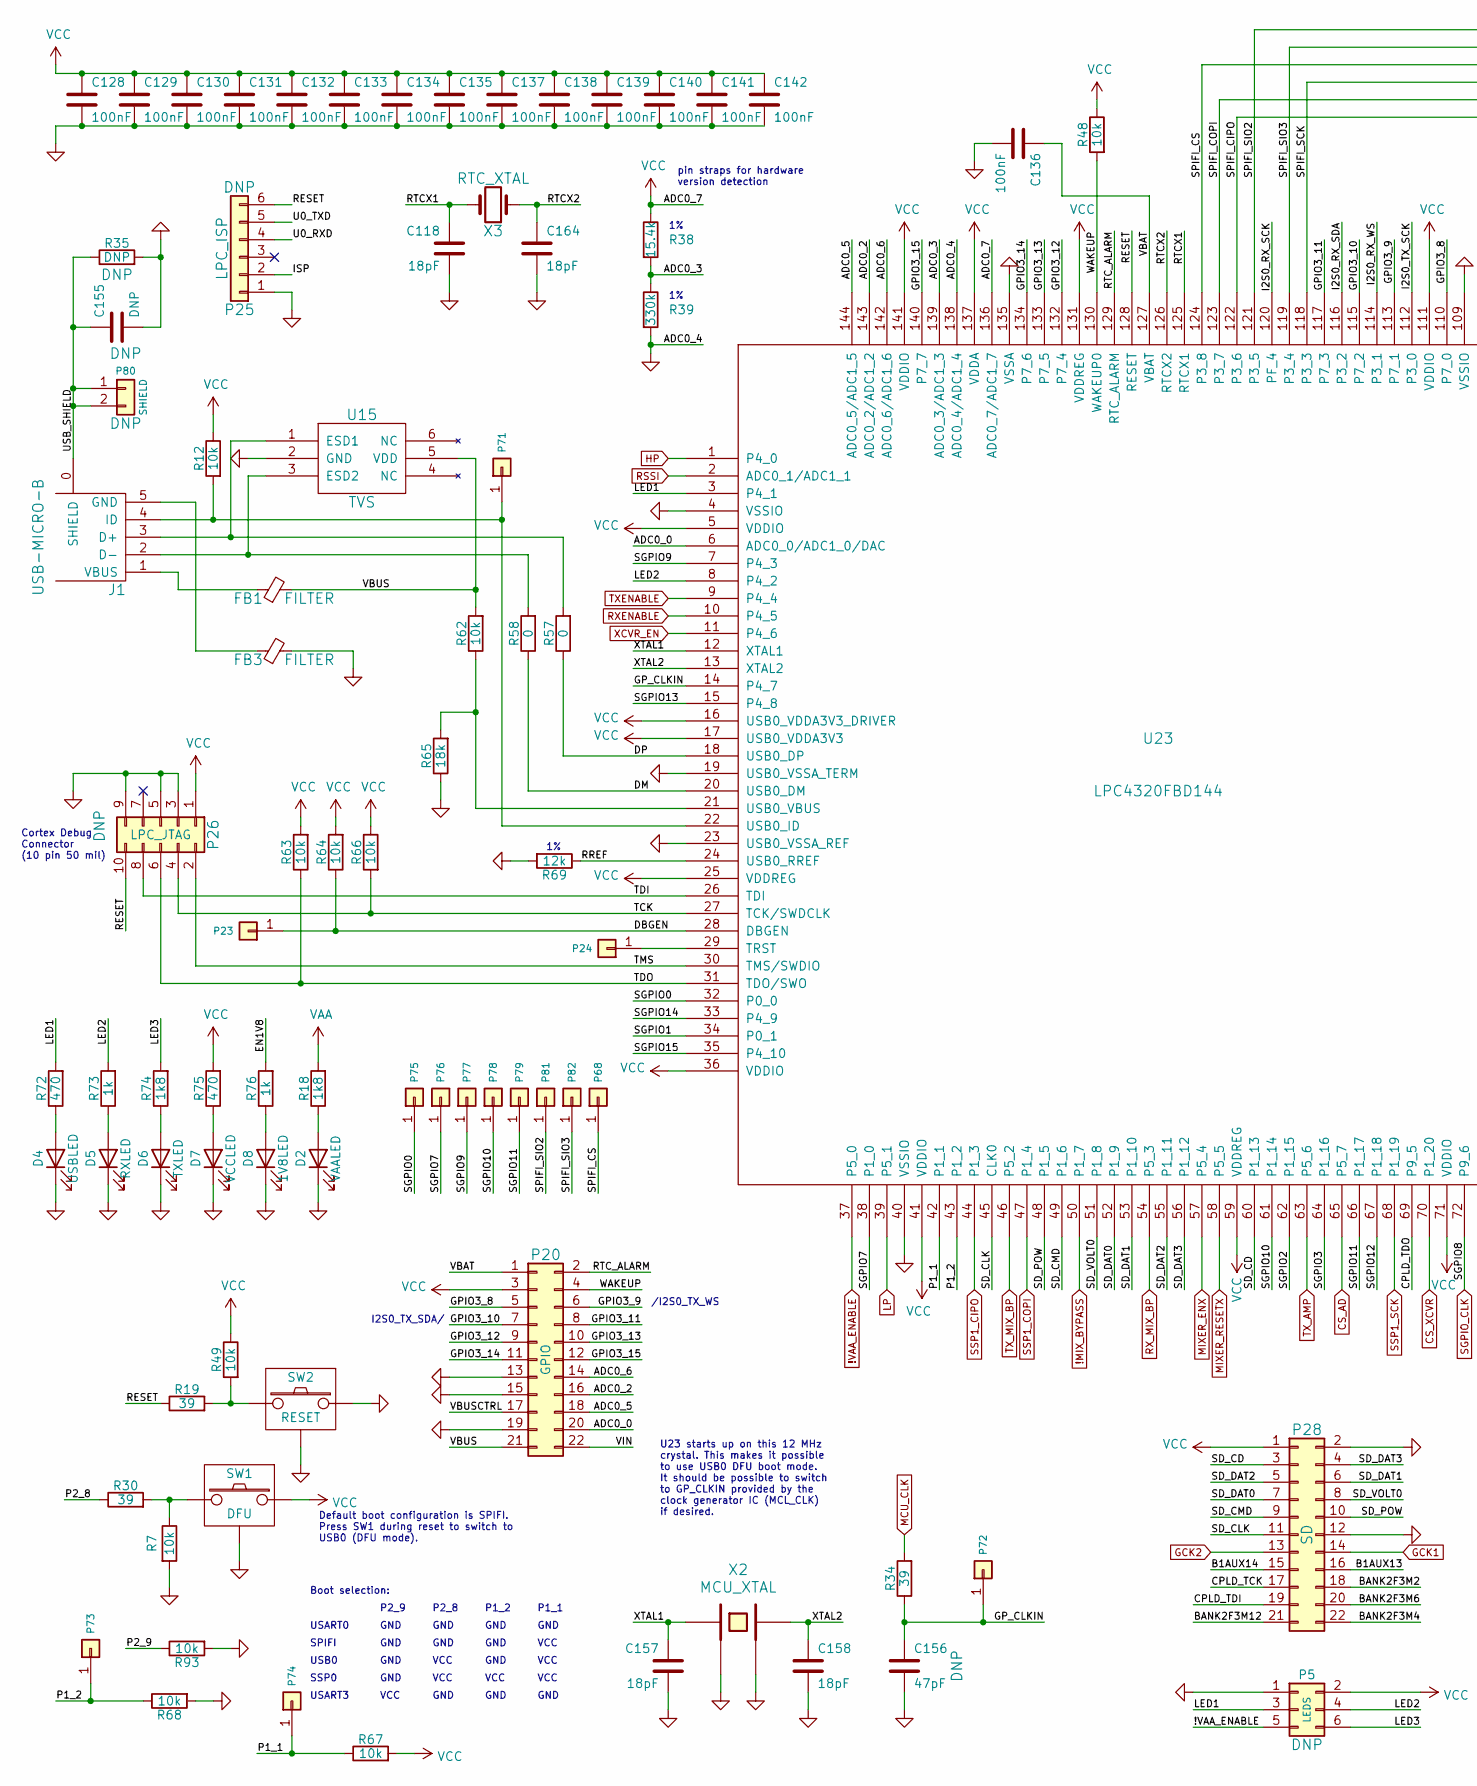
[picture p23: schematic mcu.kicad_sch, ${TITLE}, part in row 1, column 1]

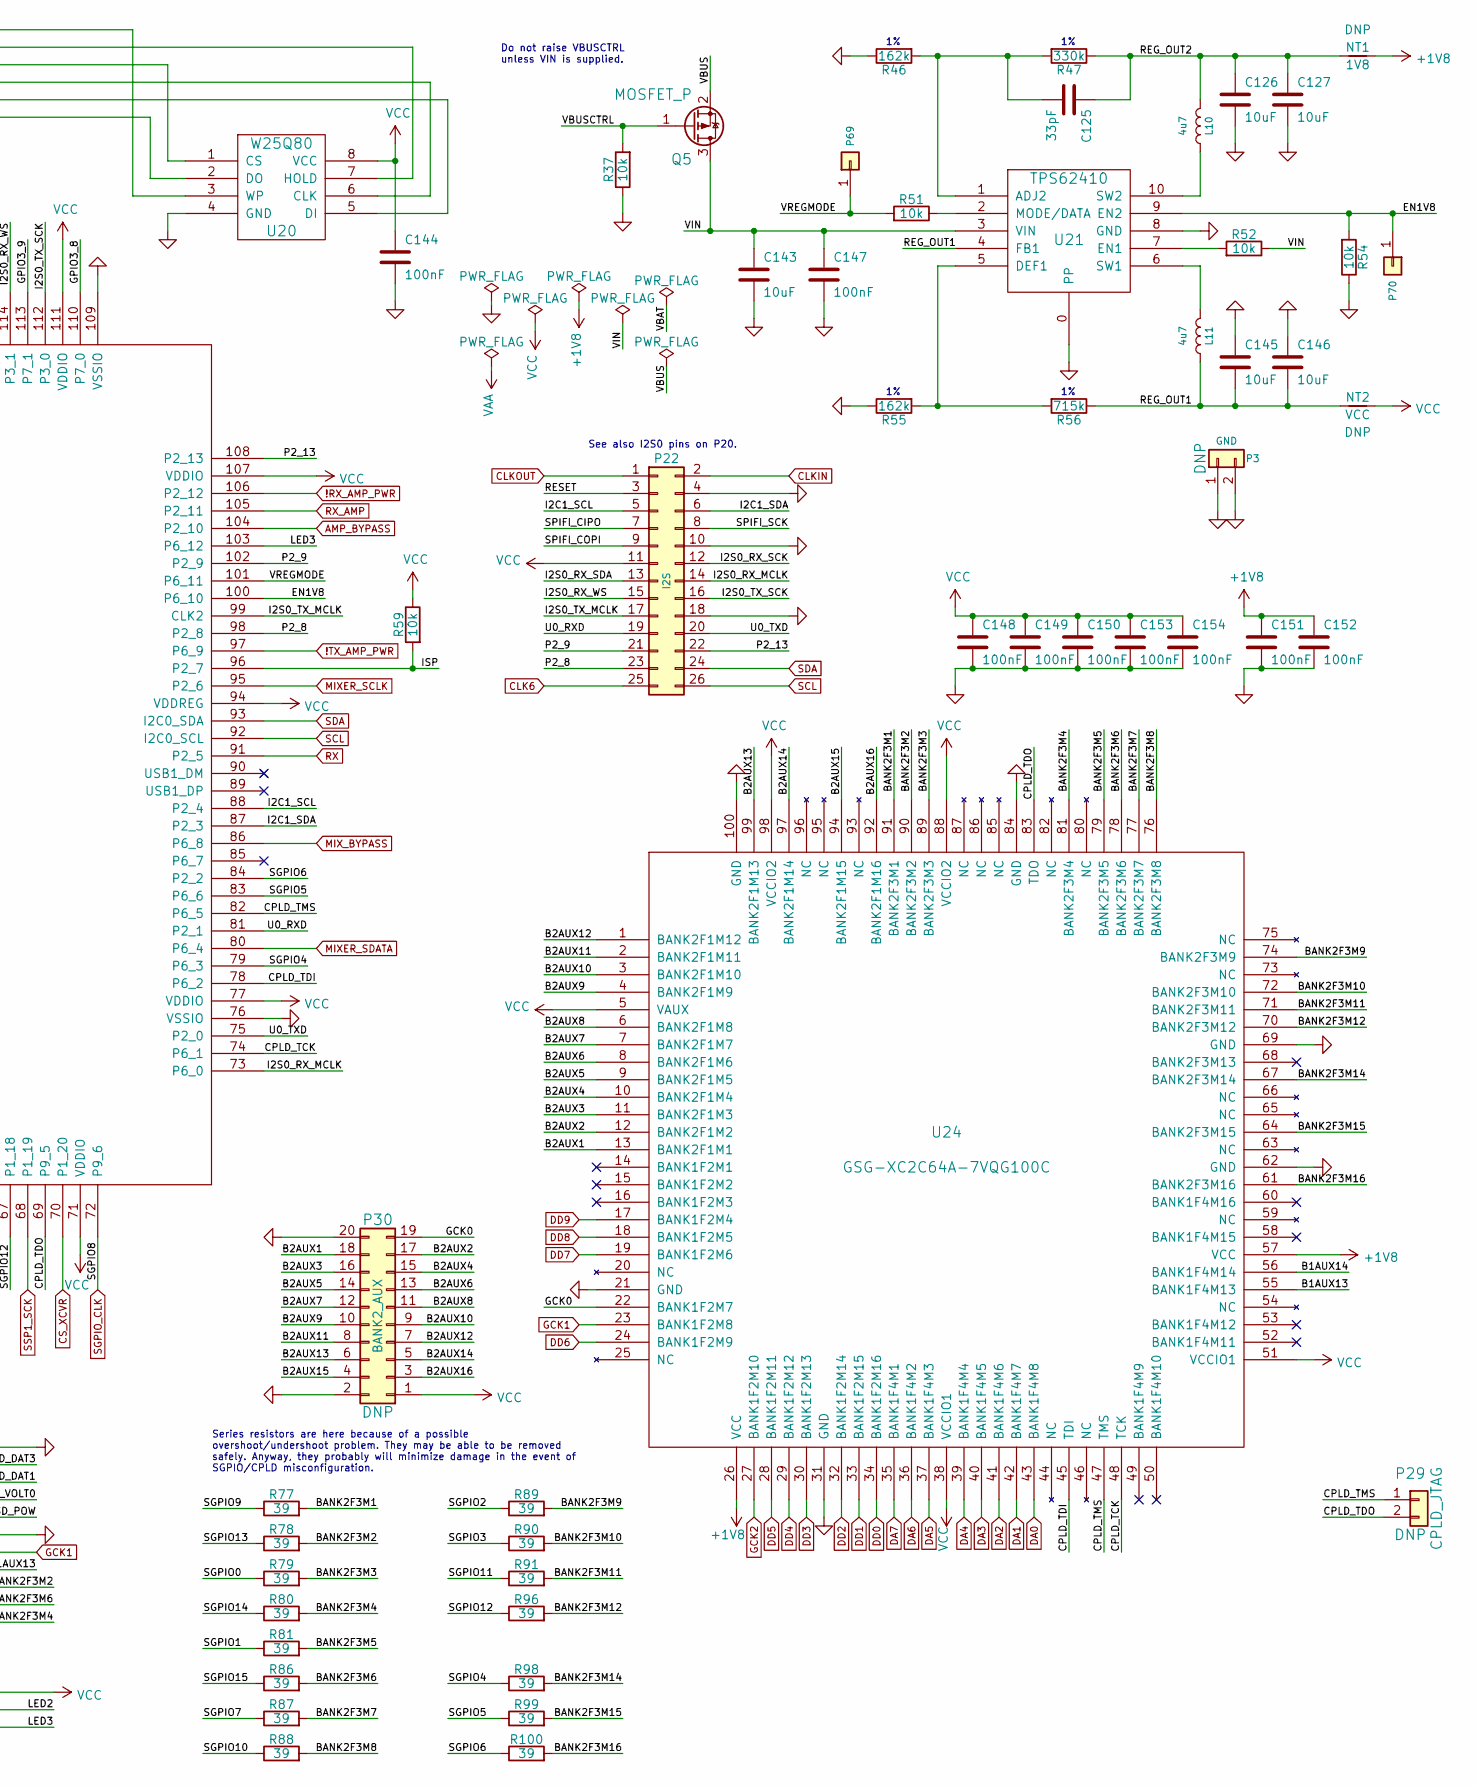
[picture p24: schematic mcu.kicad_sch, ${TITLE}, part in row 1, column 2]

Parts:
C118, C157, C158, C164: 18pF; GSG-0402; Part Number CL05C180JB5NNNC
C125: 33pF; GSG-0402; Part Number CL05C330JB5NNNC
C126, C127, C143, C145, C146: 10uF; GSG-0805; Part Number CL21A106KOQNNNE
C128, C129, C130, C131, C132, C133, C134, C135, C136, C137, C138, C139, C140, C141, C142, C144, C147, C148, C149, C150, C151, C152, C153, C154: 100nF; GSG-0402; Part Number CL05A104KA5NNNC
C155: DNP; GSG-0805
C156: 47pF; GSG-0402; Part Number CL05C470JB5NNNC
D2: VAALED; LTST-S220; Part Number LTST-S220KRKT
D4: USBLED; LTST-S220; Part Number LTST-S220KGKT
D5: RXLED; LTST-S220; Part Number LTST-S220KSKT
D6: TXLED; LTST-S220; Part Number LTST-S220KRKT
D7: VCCLED; LTST-S220; Part Number LTST-S220KGKT
D8: 1V8LED; LTST-S220; Part Number LTST-S220KSKT
FB1, FB3: FILTER; GSG-0805; Part Number BLM21PG221SN1D
J1: USB-MICRO-B; GSG-USB-MICROB-FCI-10103592-EXT; Part Number 10103592-0001LF
L10, L11: 4u7; GSG-NRG4026; Part Number NRS4018T4R7MDGJ
NT1: 1V8; HEADER-1x2-SHORTED
NT2: VCC; HEADER-1x2-SHORTED
P3: GND; GSG-HEADER-NOMARK-1x2
P5: LEDS; GSG-HEADER-2x3
P20: GPIO; GSG-HEADER-2x11; Part Number PPPC112LFBN-RC
P22: I2S; GSG-HEADER-2x13; Part Number PPPC132LFBN-RC
P23: DBGEN; GSG-TESTPOINT-50MIL
P24: TRST; GSG-TESTPOINT-50MIL
P25: LPC_ISP; GSG-HEADER-1x6
P26: LPC_JTAG; GSG-50MIL-HEADER-2x5-TH; Part Number GRPB052VWVN-RC
P28: SD; GSG-HEADER-2x11; Part Number PPPC112LFBN-RC
P29: CPLD_JTAG; GSG-HEADER-1x2
P30: BANK2_AUX; GSG-HEADER-2x10
P68: SPIFI_CS; GSG-TESTPOINT-50MIL
P69: VREGMODE; GSG-TESTPOINT-50MIL
P70: EN_1V8; GSG-TESTPOINT-50MIL
P71: ID; GSG-TESTPOINT-50MIL
P72: GP_CLKIN; GSG-TESTPOINT-50MIL
P73: P1_2; GSG-TESTPOINT-50MIL
P74: P1_1; GSG-TESTPOINT-50MIL
P75: SGPIO0; GSG-TESTPOINT-50MIL
P76: SGPIO7; GSG-TESTPOINT-50MIL
P77: SGPIO9; GSG-TESTPOINT-50MIL
P78: SGPIO10; GSG-TESTPOINT-50MIL
P79: SGPIO11; GSG-TESTPOINT-50MIL
P80: SHIELD; GSG-HEADER-NOMARK-1x2
P81: SPIFI_SIO2; GSG-TESTPOINT-50MIL
P82: SPIFI_SIO3; GSG-TESTPOINT-50MIL
Q5: MOSFET_P; SOT23-3; Part Number YJL2301C
R7, R12, R37, R48, R49, R51, R52, R54, R59, R62, R63, R64, R66, R67, R68, R93: 10k; GSG-0402; Part Number RMCF0402JT10K0
R18, R74: 1k8; GSG-0402; Part Number RMCF0402JT1K80
R19, R30, R34, R77, R78, R79, R80, R81, R86, R87, R88, R89, R90, R91, R96, R98, R99, R100: 39; GSG-0402; Part Number RMCF0402JT39R0
R35: DNP; GSG-0805
R38: 15.4k; GSG-0402; Part Number RC0402FR-0715K4L
R39, R47: 330k; GSG-0402; Part Number RMCF0402FT330K
R46, R55: 162k; GSG-0402; Part Number RMCF0402FT162K
R56: 715k; GSG-0402; Part Number RMCF0402FT715K
R57, R58: 0; GSG-0402; Part Number RMCF0402ZT0R00
R65: 18k; GSG-0402; Part Number RC0402JR-0718KL
R69: 12k; GSG-0402; Part Number RC0402FR-0712KL
R72, R75: 470; GSG-0402; Part Number RMCF0402JT470R
R73, R76: 1k; GSG-0402; Part Number RMCF0402FT1K00
SW1: DFU; GSG-SWITCH-FSMRA; Part Number FSMRA3JH
SW2: RESET; GSG-SWITCH-FSMRA; Part Number FSMRA3JH
U15: TVS; GSG-LXES1TBCC2-004; Part Number VBUS54CV-HSF-G4-08
U20: W25Q80; GSG-SOIC8-208; Part Number W25Q80DVSSIG
U21: TPS62410; GSG-S-PVSON-N10; Part Number TPS62410DRCR
U23: LPC4320FBD144; GSG-LQFP144; Part Number LPC4320FBD144,551
U24: GSG-XC2C64A-7VQG100C; GSG-VQ100; Part Number XC2C64A-7VQG100C
X2: MCU_XTAL; GSG-XTAL3.2x2.5mm; Part Number 7V-12.000MAAE-T
X3: RTC_XTAL; GSG-XTAL-AB26TRQ; Part Number AB26TRQ-32.768KHZ-T

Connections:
!MIX_BYPASS: U23.50 (P1_7); also elsewhere on the board
!RX_AMP_PWR: U23.106 (P2_12); also elsewhere on the board
!TX_AMP_PWR: U23.97 (P6_9); also elsewhere on the board
!VAA_ENABLE: P5.5, U23.37 (P5_0); also elsewhere on the board
+1V8: C151.1, C152.1, NT1.1, U24.26 (VCC), U24.57 (VCC)
/mcu/usb/power/ADC0_0: P20.20, U23.6 (ADC0_0/ADC1_0/DAC)
/mcu/usb/power/ADC0_2: P20.16, U23.143 (ADC0_2/ADC1_2)
/mcu/usb/power/ADC0_3: R38.2, R39.1, U23.139 (ADC0_3/ADC1_3)
/mcu/usb/power/ADC0_5: P20.18, U23.144 (ADC0_5/ADC1_5)
/mcu/usb/power/ADC0_6: P20.14, U23.142 (ADC0_6/ADC1_6)
/mcu/usb/power/B1AUX13: P28.16, U24.55 (BANK1F4M13)
/mcu/usb/power/B1AUX14: P28.15, U24.56 (BANK1F4M14)
/mcu/usb/power/B2AUX1: P30.18, U24.13 (BANK2F1M1)
/mcu/usb/power/B2AUX2: P30.17, U24.12 (BANK2F1M2)
/mcu/usb/power/B2AUX3: P30.16, U24.11 (BANK2F1M3)
/mcu/usb/power/B2AUX4: P30.15, U24.10 (BANK2F1M4)
/mcu/usb/power/B2AUX5: P30.14, U24.9 (BANK2F1M5)
/mcu/usb/power/B2AUX6: P30.13, U24.8 (BANK2F1M6)
/mcu/usb/power/B2AUX7: P30.12, U24.7 (BANK2F1M7)
/mcu/usb/power/B2AUX8: P30.11, U24.6 (BANK2F1M8)
/mcu/usb/power/B2AUX9: P30.10, U24.4 (BANK2F1M9)
/mcu/usb/power/B2AUX10: P30.9, U24.3 (BANK2F1M10)
/mcu/usb/power/B2AUX11: P30.8, U24.2 (BANK2F1M11)
/mcu/usb/power/B2AUX12: P30.7, U24.1 (BANK2F1M12)
/mcu/usb/power/B2AUX13: P30.6, U24.99 (BANK2F1M13)
/mcu/usb/power/B2AUX14: P30.5, U24.97 (BANK2F1M14)
/mcu/usb/power/B2AUX15: P30.4, U24.94 (BANK2F1M15)
/mcu/usb/power/B2AUX16: P30.3, U24.92 (BANK2F1M16)
/mcu/usb/power/BANK2F3M1: R77.2, U24.91 (BANK2F3M1)
/mcu/usb/power/BANK2F3M2: P28.18, R78.2, U24.90 (BANK2F3M2)
/mcu/usb/power/BANK2F3M3: R79.2, U24.89 (BANK2F3M3)
/mcu/usb/power/BANK2F3M4: P28.22, R80.2, U24.81 (BANK2F3M4)
/mcu/usb/power/BANK2F3M5: R81.2, U24.79 (BANK2F3M5)
/mcu/usb/power/BANK2F3M6: P28.20, R86.2, U24.78 (BANK2F3M6)
/mcu/usb/power/BANK2F3M7: R87.2, U24.77 (BANK2F3M7)
/mcu/usb/power/BANK2F3M8: R88.2, U24.76 (BANK2F3M8)
/mcu/usb/power/BANK2F3M9: R89.2, U24.74 (BANK2F3M9)
/mcu/usb/power/BANK2F3M10: R90.2, U24.72 (BANK2F3M10)
/mcu/usb/power/BANK2F3M11: R91.2, U24.71 (BANK2F3M11)
/mcu/usb/power/BANK2F3M12: P28.21, R96.2, U24.70 (BANK2F3M12)
/mcu/usb/power/BANK2F3M14: R98.2, U24.67 (BANK2F3M14)
/mcu/usb/power/BANK2F3M15: R99.2, U24.64 (BANK2F3M15)
/mcu/usb/power/BANK2F3M16: R100.2, U24.61 (BANK2F3M16)
/mcu/usb/power/CPLD_TCK: P28.17, U23.74 (P6_1), U24.48 (TCK)
/mcu/usb/power/CPLD_TDI: P28.19, U23.78 (P6_2), U24.45 (TDI)
/mcu/usb/power/CPLD_TDO: P29.2, U23.69 (P9_5), U24.83 (TDO)
/mcu/usb/power/CPLD_TMS: P29.1, U23.82 (P6_5), U24.47 (TMS)
/mcu/usb/power/DBGEN: P23.1, R64.1, U23.28 (DBGEN)
/mcu/usb/power/DM: R58.1, U23.20 (USB0_DM)
/mcu/usb/power/DP: R57.1, U23.18 (USB0_DP)
/mcu/usb/power/EN1V8: P70.1, R54.2, R76.2, U21.9 (EN2), U23.100 (P6_10)
/mcu/usb/power/GCK0: P30.19, U24.22 (BANK1F2M7)
/mcu/usb/power/GPIO3_8: P20.5, U23.110 (P7_0)
/mcu/usb/power/GPIO3_9: P20.6, U23.113 (P7_1)
/mcu/usb/power/GPIO3_10: P20.7, U23.115 (P7_2)
/mcu/usb/power/GPIO3_11: P20.8, U23.117 (P7_3)
/mcu/usb/power/GPIO3_12: P20.9, U23.132 (P7_4)
/mcu/usb/power/GPIO3_13: P20.10, U23.133 (P7_5)
/mcu/usb/power/GPIO3_14: P20.11, U23.134 (P7_6)
/mcu/usb/power/GPIO3_15: P20.12, U23.140 (P7_7)
/mcu/usb/power/GP_CLKIN: C156.1, P72.1, R34.1, U23.14 (P4_7)
/mcu/usb/power/I2C1_SCL: P22.5, U23.88 (P2_4)
/mcu/usb/power/I2C1_SDA: P22.6, U23.87 (P2_3)
/mcu/usb/power/I2S0_RX_MCLK: P22.14, U23.73 (P6_0)
/mcu/usb/power/I2S0_RX_SCK: P22.12, U23.120 (PF_4)
/mcu/usb/power/I2S0_RX_SDA: P22.13, U23.116 (P3_2)
/mcu/usb/power/I2S0_RX_WS: P22.15, U23.114 (P3_1)
/mcu/usb/power/I2S0_TX_MCLK: P22.17, U23.99 (CLK2)
/mcu/usb/power/I2S0_TX_SCK: P22.16, U23.112 (P3_0)
/mcu/usb/power/ISP: P25.2, R59.2, U23.96 (P2_7)
/mcu/usb/power/LED1: P5.3, R72.2, U23.3 (P4_1)
/mcu/usb/power/LED2: P5.4, R73.2, U23.8 (P4_2)
/mcu/usb/power/LED3: P5.6, R74.2, U23.103 (P6_12)
/mcu/usb/power/P1_1: P74.1, R67.1, U23.42 (P1_1)
/mcu/usb/power/P1_2: P73.1, R68.1, U23.43 (P1_2)
/mcu/usb/power/P2_8: P22.23, R30.1, U23.98 (P2_8)
/mcu/usb/power/P2_9: P22.21, R93.1, U23.102 (P2_9)
/mcu/usb/power/P2_13: P22.22, U23.108 (P2_13)
/mcu/usb/power/REG_OUT1: C145.2, C146.2, L11.1, NT2.2, R56.1, U21.4 (FB1)
/mcu/usb/power/REG_OUT2: C125.1, C126.1, C127.1, L10.2, NT1.2, R47.1
/mcu/usb/power/RESET: P22.3, P25.6, P26.10, R19.1, U23.128 (RESET)
/mcu/usb/power/RREF: R69.1, U23.24 (USB0_RREF)
/mcu/usb/power/RTCX1: C118.1, U23.125 (RTCX1), X3.2
/mcu/usb/power/RTCX2: C164.1, U23.126 (RTCX2), X3.1
/mcu/usb/power/RTC_ALARM: P20.2, U23.129 (RTC_ALARM)
/mcu/usb/power/SD_CD: P28.3, U23.60 (P1_13)
/mcu/usb/power/SD_CLK: P28.11, U23.45 (CLK0)
/mcu/usb/power/SD_CMD: P28.9, U23.49 (P1_6)
/mcu/usb/power/SD_DAT0: P28.7, U23.52 (P1_9)
/mcu/usb/power/SD_DAT1: P28.6, U23.53 (P1_10)
/mcu/usb/power/SD_DAT2: P28.5, U23.55 (P1_11)
/mcu/usb/power/SD_DAT3: P28.4, U23.56 (P1_12)
/mcu/usb/power/SD_POW: P28.10, U23.48 (P1_5)
/mcu/usb/power/SD_VOLT0: P28.8, U23.51 (P1_8)
/mcu/usb/power/SGPIO0: P75.1, R79.1, U23.32 (P0_0)
/mcu/usb/power/SGPIO1: R81.1, U23.34 (P0_1)
/mcu/usb/power/SGPIO2: R89.1, U23.62 (P1_15)
/mcu/usb/power/SGPIO3: R90.1, U23.64 (P1_16)
/mcu/usb/power/SGPIO4: R98.1, U23.79 (P6_3)
/mcu/usb/power/SGPIO5: R99.1, U23.83 (P6_6)
/mcu/usb/power/SGPIO6: R100.1, U23.84 (P2_2)
/mcu/usb/power/SGPIO7: P76.1, R87.1, U23.38 (P1_0)
/mcu/usb/power/SGPIO9: P77.1, R77.1, U23.7 (P4_3)
/mcu/usb/power/SGPIO10: P78.1, R88.1, U23.61 (P1_14)
/mcu/usb/power/SGPIO11: P79.1, R91.1, U23.66 (P1_17)
/mcu/usb/power/SGPIO12: R96.1, U23.67 (P1_18)
/mcu/usb/power/SGPIO13: R78.1, U23.15 (P4_8)
/mcu/usb/power/SGPIO14: R80.1, U23.33 (P4_9)
/mcu/usb/power/SGPIO15: R86.1, U23.35 (P4_10)
/mcu/usb/power/SPIFI_CIPO: P22.7, U20.2 (DO), U23.122 (P3_6)
/mcu/usb/power/SPIFI_COPI: P22.9, U20.5 (DI), U23.123 (P3_7)
/mcu/usb/power/SPIFI_CS: P68.1, U20.1 (CS), U23.124 (P3_8)
/mcu/usb/power/SPIFI_SCK: P22.8, U20.6 (CLK), U23.118 (P3_3)
/mcu/usb/power/SPIFI_SIO2: P81.1, U20.3 (WP), U23.121 (P3_5)
/mcu/usb/power/SPIFI_SIO3: P82.1, U20.7 (HOLD), U23.119 (P3_4)
/mcu/usb/power/TCK: P26.4, R66.2, U23.27 (TCK/SWDCLK)
/mcu/usb/power/TDI: P26.8, U23.26 (TDI)
/mcu/usb/power/TDO: P26.6, R63.1, U23.31 (TDO/SWO)
/mcu/usb/power/TMS: P26.2, U23.30 (TMS/SWDIO)
/mcu/usb/power/U0_RXD: P22.19, P25.4, U23.81 (P2_1)
/mcu/usb/power/U0_TXD: P22.20, P25.5, U23.75 (P2_0)
/mcu/usb/power/USB_SHIELD: C155.1, J1.0 (SHIELD), P80.1, P80.2, R35.1
/mcu/usb/power/VBAT: C136.1, P20.1, U23.127 (VBAT)
/mcu/usb/power/VBUS: FB1.2, P20.21, Q5.2 (S), R62.2, U15.5 (VDD)
/mcu/usb/power/VBUSCTRL: P20.17, Q5.1 (G), R37.2
/mcu/usb/power/VIN: C143.1, C147.1, P20.22, Q5.3 (D), R52.1, U21.3 (VIN)
/mcu/usb/power/VREGMODE: P69.1, R51.2, U23.101 (P6_11)
/mcu/usb/power/WAKEUP: P20.4, R48.2, U23.130 (WAKEUP0)
/mcu/usb/power/XTAL1: C157.1, U23.12 (XTAL1), X2.1
/mcu/usb/power/XTAL2: C158.1, U23.13 (XTAL2), X2.3
AMP_BYPASS: U23.104 (P2_10); also elsewhere on the board
CLK6: P22.25; also elsewhere on the board
CLKIN: P22.2; also elsewhere on the board
CLKOUT: P22.1; also elsewhere on the board
CS_AD: U23.65 (P5_7); also elsewhere on the board
CS_XCVR: U23.70 (P1_20); also elsewhere on the board
DA0: U24.43 (BANK1F4M8); also elsewhere on the board
DA1: U24.42 (BANK1F4M7); also elsewhere on the board
DA2: U24.41 (BANK1F4M6); also elsewhere on the board
DA3: U24.40 (BANK1F4M5); also elsewhere on the board
DA4: U24.39 (BANK1F4M4); also elsewhere on the board
DA5: U24.37 (BANK1F4M3); also elsewhere on the board
DA6: U24.36 (BANK1F4M2); also elsewhere on the board
DA7: U24.35 (BANK1F4M1); also elsewhere on the board
DD0: U24.34 (BANK1F2M16); also elsewhere on the board
DD1: U24.33 (BANK1F2M15); also elsewhere on the board
DD2: U24.32 (BANK1F2M14); also elsewhere on the board
DD3: U24.30 (BANK1F2M13); also elsewhere on the board
DD4: U24.29 (BANK1F2M12); also elsewhere on the board
DD5: U24.28 (BANK1F2M11); also elsewhere on the board
DD6: U24.24 (BANK1F2M9); also elsewhere on the board
DD7: U24.19 (BANK1F2M6); also elsewhere on the board
DD8: U24.18 (BANK1F2M5); also elsewhere on the board
DD9: U24.17 (BANK1F2M4); also elsewhere on the board
GCK1: P28.14, U24.23 (BANK1F2M8); also elsewhere on the board
GCK2: P28.13, U24.27 (BANK1F2M10); also elsewhere on the board
GND: C118.2, C126.2, C127.2, C128.2, C129.2, C130.2, C131.2, C132.2, C133.2, C134.2, C135.2, C136.2, C137.2, C138.2, C139.2, C140.2, C141.2, C142.2, C143.2, C144.2, C145.1, C146.1, C147.2, C148.2, C149.2, C150.2, C151.2, C152.2, C153.2, C154.2, C155.2, C156.2, C157.2, C158.2, C164.2, D2.1 (K), D4.1 (K), D5.1 (K), D6.1 (K), D7.1 (K), D8.1 (K), FB3.2, P3.1, P3.2, P5.1, P20.13, P20.15, P20.19, P22.4, P22.10, P22.18, P25.1, P26.3, P26.5, P26.9, P28.2, P28.12, P30.2, P30.20, R7.2, R35.2, R37.1, R39.2, R46.1, R54.1, R55.1, R65.1, R68.2, R69.2, R93.2, SW1.0 (SHIELD), SW2.0 (SHIELD), SW2.1, U15.2 (GND), U20.4 (GND), U21.0 (PP), U21.8 (GND), U23.4 (VSSIO), U23.19 (USB0_VSSA_TERM), U23.23 (USB0_VSSA_REF), U23.40 (VSSIO), U23.76 (VSSIO), U23.109 (VSSIO), U23.135 (VSSA), U23.138 (ADC0_4/ADC1_4), U24.21 (GND), U24.31 (GND), U24.62 (GND), U24.69 (GND), U24.84 (GND), U24.100 (GND), X2.2, X2.4; also elsewhere on the board
HP: U23.1 (P4_0); also elsewhere on the board
LP: U23.39 (P5_1); also elsewhere on the board
MCU_CLK: R34.2; also elsewhere on the board
MIXER_ENX: U23.57 (P5_4); also elsewhere on the board
MIXER_RESETX: U23.58 (P5_5); also elsewhere on the board
MIXER_SCLK: U23.95 (P2_6); also elsewhere on the board
MIXER_SDATA: U23.80 (P6_4); also elsewhere on the board
MIX_BYPASS: U23.86 (P6_8); also elsewhere on the board
unnamed: C125.2, R46.2, R47.2, U21.1 (ADJ2)
unnamed: D2.2 (A), R18.1
unnamed: D4.2 (A), R72.1
unnamed: D5.2 (A), R73.1
unnamed: D6.2 (A), R74.1
unnamed: D7.2 (A), R75.1
unnamed: D8.2 (A), R76.1
unnamed: FB1.1, J1.1 (VBUS)
unnamed: FB3.1, J1.5 (GND)
unnamed: J1.2 (D-), R58.2, U15.3 (ESD2)
unnamed: J1.3 (D+), R57.2, U15.1 (ESD1)
unnamed: J1.4 (ID), P71.1, R12.2, U23.22 (USB0_ID)
unnamed: L10.1, U21.10 (SW2)
unnamed: L11.2, U21.6 (SW1)
unnamed: P24.1, U23.29 (TRST)
unnamed: R19.2, R49.2, SW2.2
unnamed: R7.1, R30.2, SW1.2
unnamed: R51.1, U21.2 (MODE/DATA)
unnamed: R52.2, U21.7 (EN1)
unnamed: R55.2, R56.2, U21.5 (DEF1)
unnamed: R62.1, R65.2, U23.21 (USB0_VBUS)
RSSI: U23.2 (ADC0_1/ADC1_1); also elsewhere on the board
RX: U23.91 (P2_5); also elsewhere on the board
RXENABLE: U23.10 (P4_5); also elsewhere on the board
RX_AMP: U23.105 (P2_11); also elsewhere on the board
RX_MIX_BP: U23.54 (P5_3); also elsewhere on the board
SCL: P22.26, U23.92 (I2C0_SCL); also elsewhere on the board
SDA: P22.24, U23.93 (I2C0_SDA); also elsewhere on the board
SGPIO_CLK: U23.72 (P9_6); also elsewhere on the board
SSP1_CIPO: U23.44 (P1_3); also elsewhere on the board
SSP1_COPI: U23.47 (P1_4); also elsewhere on the board
SSP1_SCK: U23.68 (P1_19); also elsewhere on the board
TXENABLE: U23.9 (P4_4); also elsewhere on the board
TX_AMP: U23.63 (P5_6); also elsewhere on the board
TX_MIX_BP: U23.46 (P5_2); also elsewhere on the board
VAA: R18.2; also elsewhere on the board
VCC: C128.1, C129.1, C130.1, C131.1, C132.1, C133.1, C134.1, C135.1, C137.1, C138.1, C139.1, C140.1, C141.1, C142.1, C144.1, C148.1, C149.1, C150.1, C153.1, C154.1, NT2.1, P5.2, P20.3, P22.11, P26.1, P28.1, P30.1, R12.1, R38.1, R48.1, R49.1, R59.1, R63.2, R64.2, R66.1, R67.2, R75.2, SW1.1, U20.8 (VCC), U23.5 (VDDIO), U23.16 (USB0_VDDA3V3_DRIVER), U23.17 (USB0_VDDA3V3), U23.25 (VDDREG), U23.36 (VDDIO), U23.41 (VDDIO), U23.59 (VDDREG), U23.71 (VDDIO), U23.77 (VDDIO), U23.94 (VDDREG), U23.107 (VDDIO), U23.111 (VDDIO), U23.131 (VDDREG), U23.136 (ADC0_7/ADC1_7), U23.137 (VDDA), U23.141 (VDDIO), U24.5 (VAUX), U24.38 (VCCIO1), U24.51 (VCCIO1), U24.88 (VCCIO2), U24.98 (VCCIO2); also elsewhere on the board
XCVR_EN: U23.11 (P4_6); also elsewhere on the board

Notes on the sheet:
GND
VCC
Series resistors are here because of a possible overshoot/undershoot problem. They may be able to be removed safely. Anyway, they probably will minimize damage in the event of SGPIO/CPLD misconfiguration.
Default boot configuration is SPIFI. Press SW1 during reset to switch to USB0 (DFU mode).
I2S0_TX_SDA/
USB0
Boot selection:
pin straps for hardware version detection
See also I2S0 pins on P20.
/I2S0_TX_WS
USART0
SSP0
P2_8
P1_1
P2_9
USART3
Do not raise VBUSCTRL unless VIN is supplied.
Cortex Debug Connector (10 pin 50 mil)
P1_2
U23 starts up on this 12 MHz crystal. This makes it possible to use USB0 DFU boot mode. It should be possible to switch to GP_CLKIN provided by the clock generator IC (MCL_CLK) if desired.
SPIFI

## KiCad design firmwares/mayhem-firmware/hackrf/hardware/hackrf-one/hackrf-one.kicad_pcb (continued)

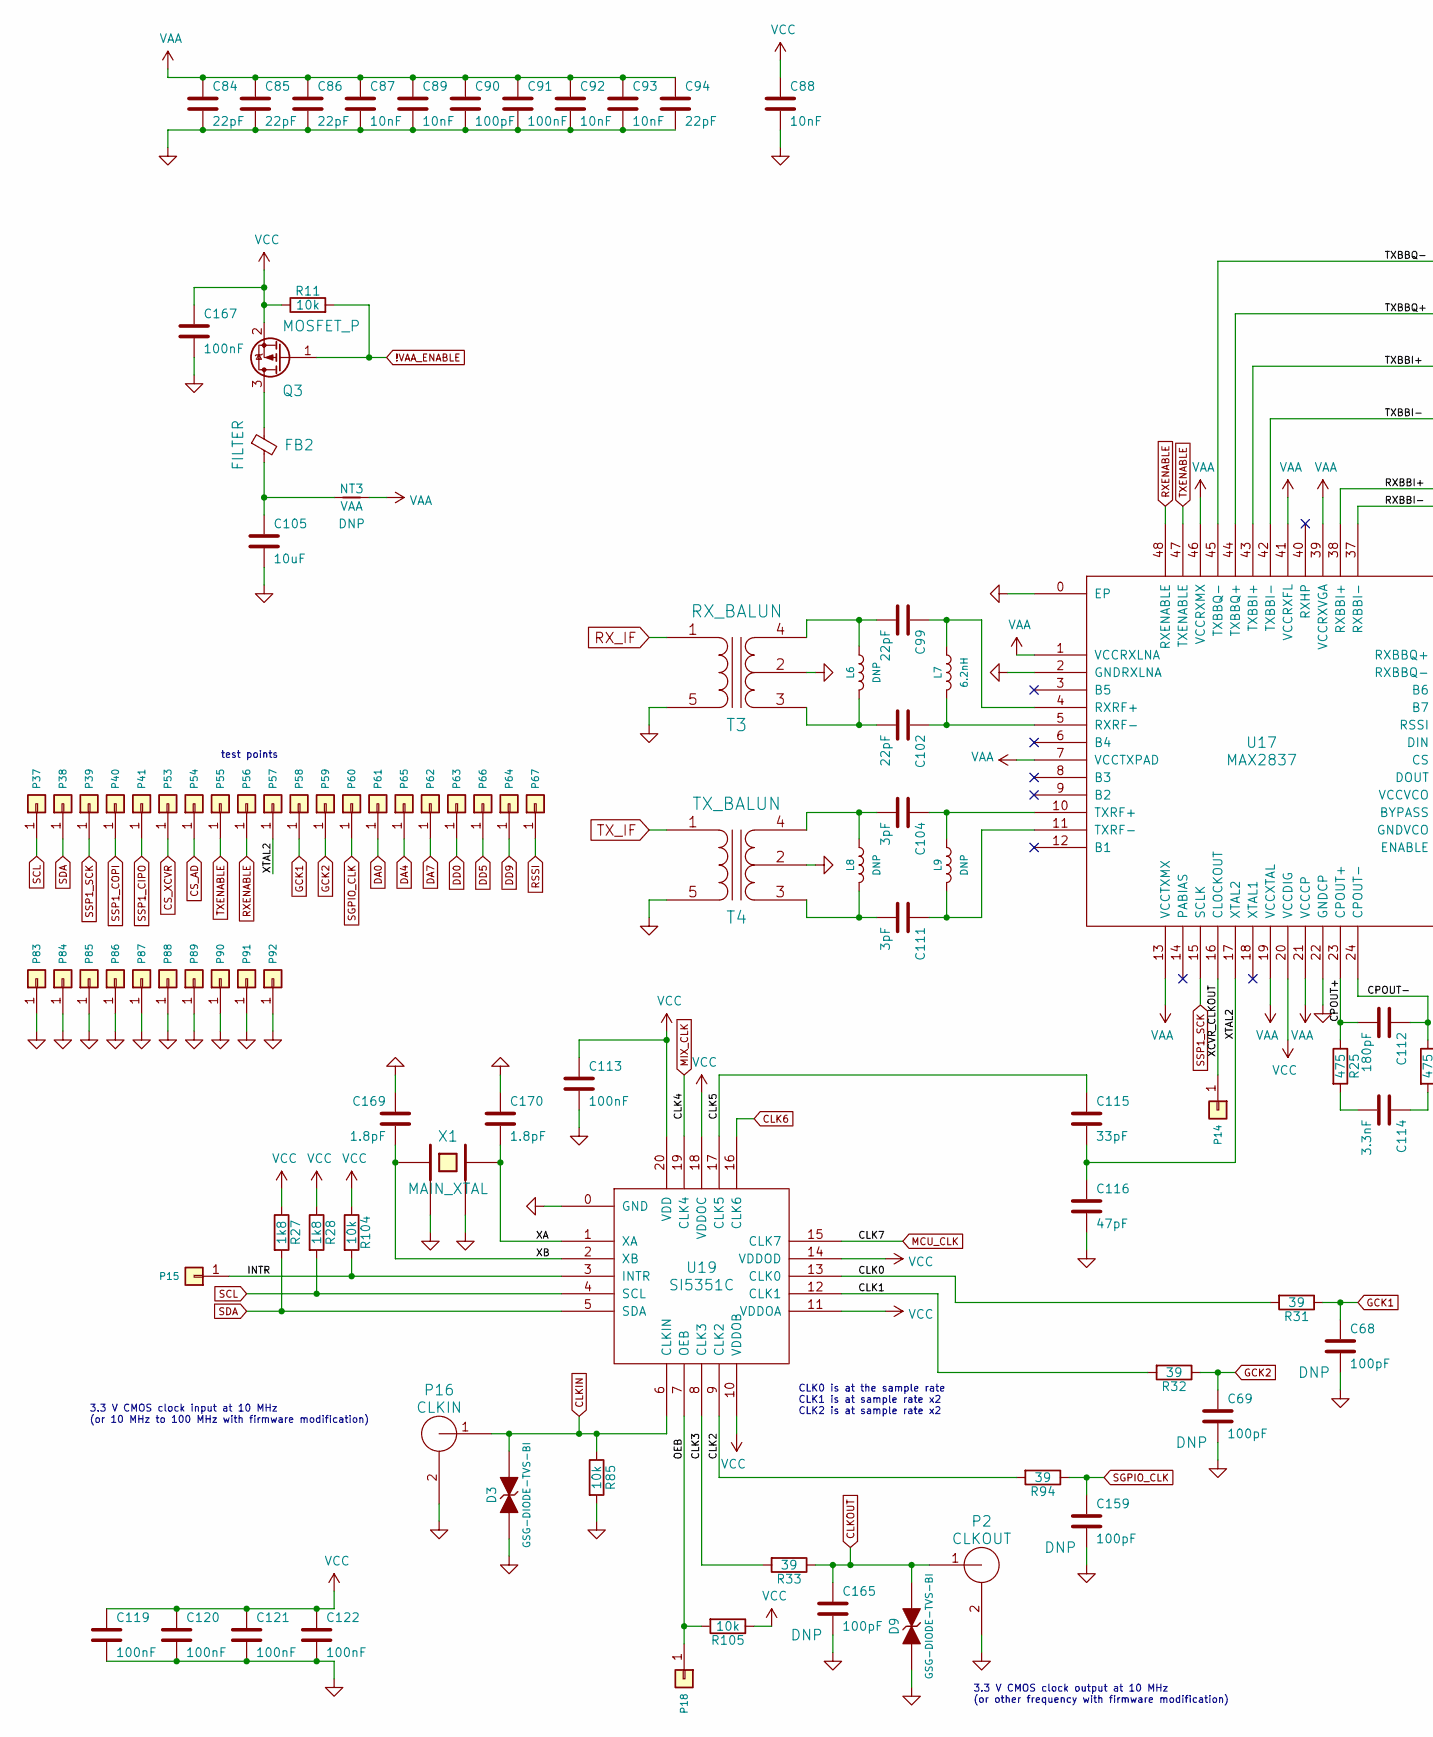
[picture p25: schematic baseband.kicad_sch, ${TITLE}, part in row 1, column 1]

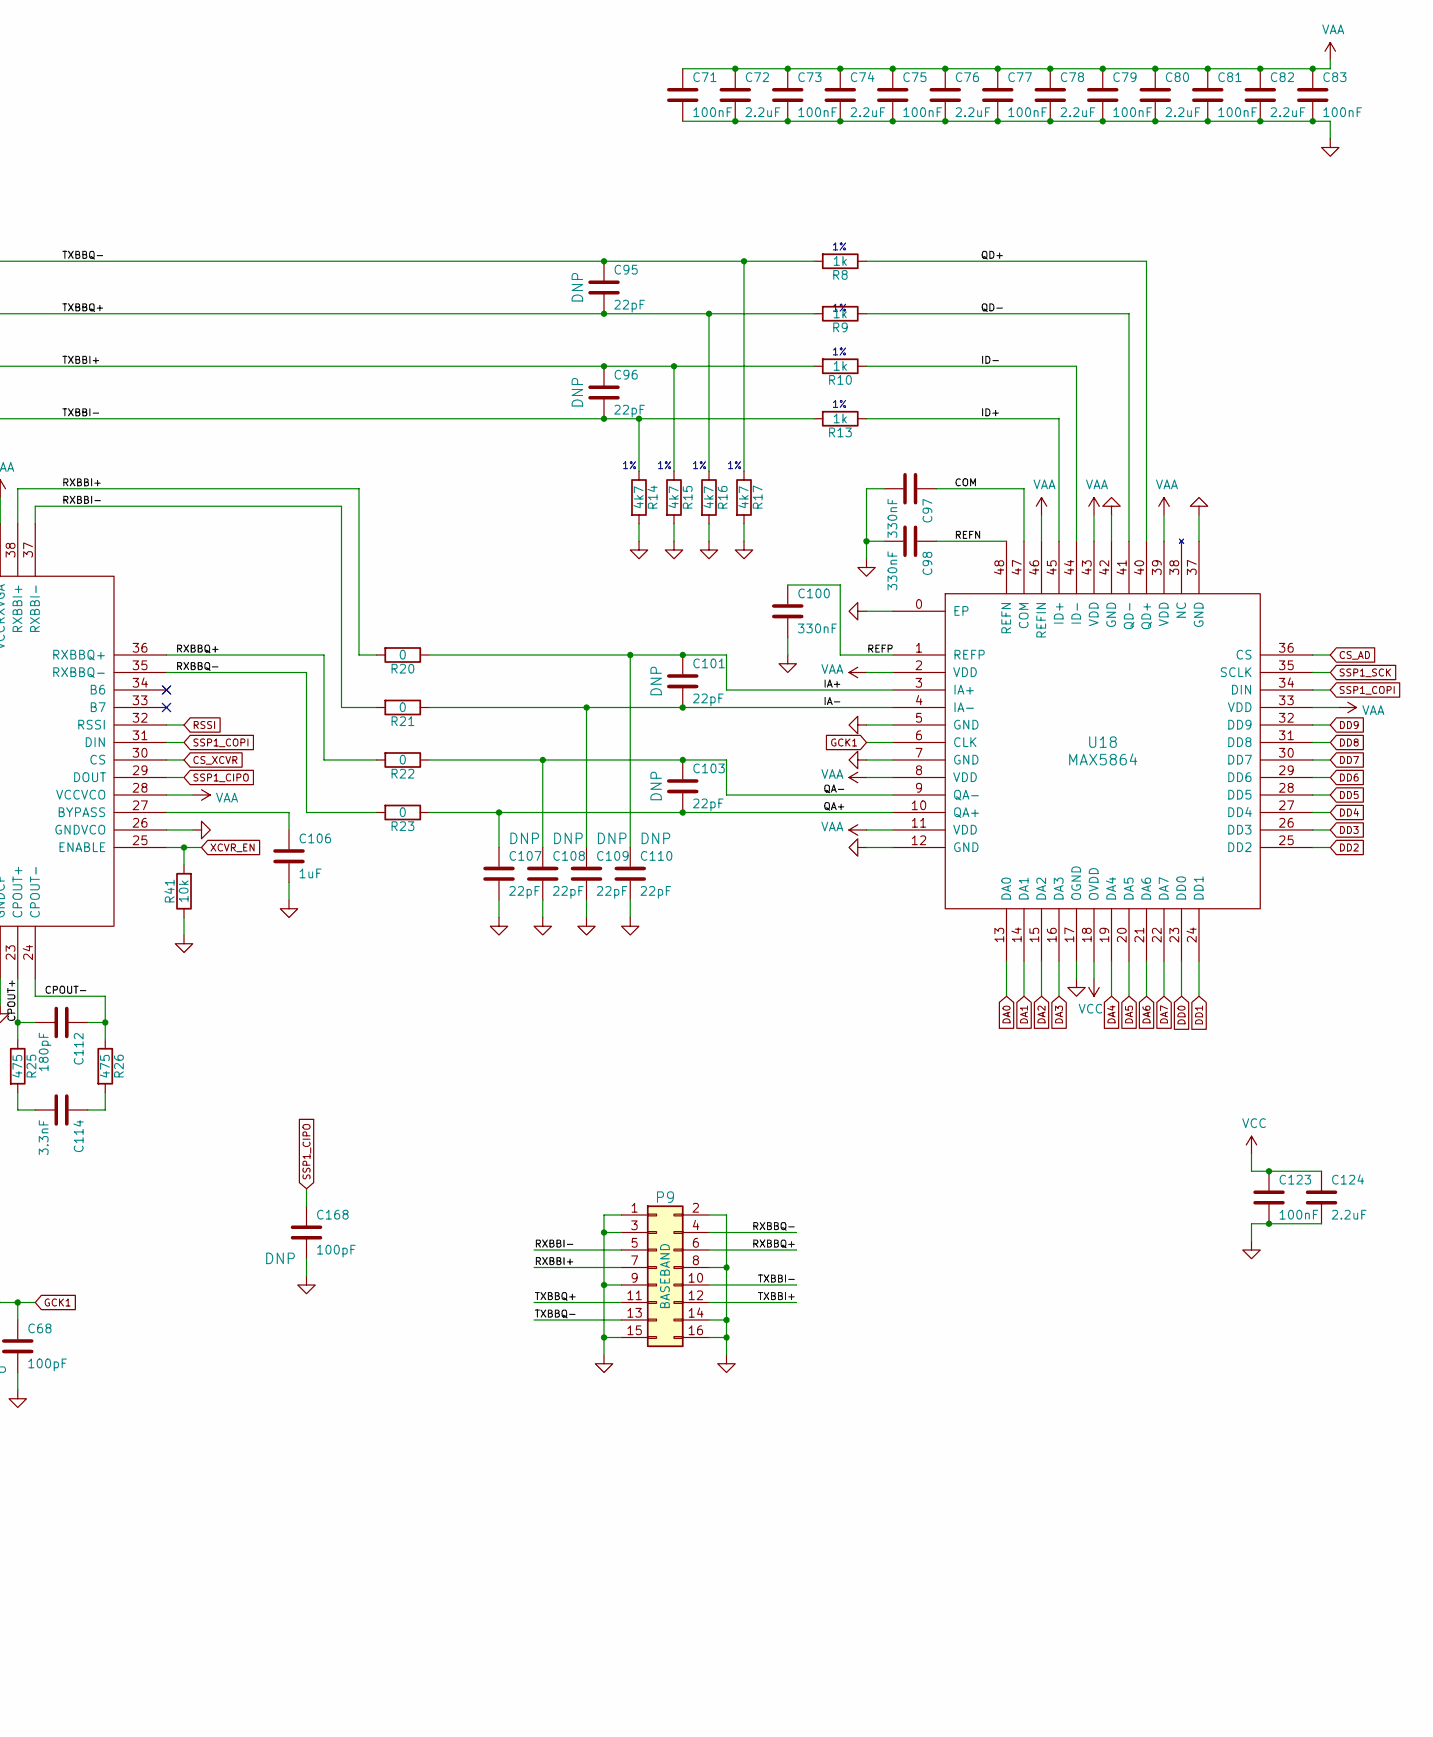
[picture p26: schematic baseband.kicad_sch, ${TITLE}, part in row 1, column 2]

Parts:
C68, C69, C90, C159, C165, C168: 100pF; GSG-0402; Part Number CL05C101JB5NNNC
C71, C73, C75, C77, C79, C81, C83, C91, C113, C119, C120, C121, C122, C123, C167: 100nF; GSG-0402; Part Number CL05A104KA5NNNC
C72, C74, C76, C78, C80, C82, C124: 2.2uF; GSG-0402; Part Number LMK105BJ225MV-F
C84, C85, C86, C94, C95, C96, C99, C101, C102, C103, C107, C108, C109, C110: 22pF; GSG-0402; Part Number CL05C220JB5NNNC
C87, C88, C89, C92, C93: 10nF; GSG-0402; Part Number CL05B103KB5NNNC
C97, C98, C100: 330nF; GSG-0402; Part Number CC0402KRX5R6BB334
C104, C111: 3pF; GSG-0402; Part Number GCM1555C1H3R0CA16D
C105: 10uF; GSG-0805; Part Number CL21A106KOQNNNE
C106: 1uF; GSG-0402; Part Number CL05A105KP5NNNC
C112: 180pF; GSG-0402; Part Number CC0402JRNPO9BN181
C114: 3.3nF; GSG-0402; Part Number CC0402KRX7R9BB332
C115: 33pF; GSG-0402; Part Number CL05C330JB5NNNC
C116: 47pF; GSG-0402; Part Number CL05C470JB5NNNC
C169, C170: 1.8pF; GSG-0402; Part Number CC0402CRNPO9BN1R8
D3, D9: GSG-DIODE-TVS-BI; GSG-0402; Part Number LXES15AAA1-100
FB2: FILTER; GSG-0805; Part Number BLM21PG221SN1D
L6, L8, L9: DNP; GSG-0402
L7: 6.2nH; GSG-0402; Part Number LQG15HS6N2S02D
NT3: VAA; HEADER-1x2-SHORTED
P2: CLKOUT; GSG-SMA-73251-2120; Part Number 73251-2121
P9: BASEBAND; GSG-HEADER-2x8; Part Number PPPC082LFBN-RC
P14: XCVR_CLKOUT; GSG-TESTPOINT-50MIL
P15: INTR; GSG-TESTPOINT-50MIL
P16: CLKIN; GSG-SMA-73251-2120; Part Number 73251-2121
P18: OEB; GSG-TESTPOINT-50MIL
P37: SCL; GSG-TESTPOINT-50MIL
P38: SDA; GSG-TESTPOINT-50MIL
P39: SSP1_SCK; GSG-TESTPOINT-50MIL
P40: SSP1_COPI; GSG-TESTPOINT-50MIL
P41: SSP1_CIPO; GSG-TESTPOINT-50MIL
P53: CS_XCVR; GSG-TESTPOINT-50MIL
P54: CS_AD; GSG-TESTPOINT-50MIL
P55: TXENABLE; GSG-TESTPOINT-50MIL
P56: RXENABLE; GSG-TESTPOINT-50MIL
P57: XTAL2; GSG-TESTPOINT-50MIL
P58: GCK1; GSG-TESTPOINT-50MIL
P59: GCK2; GSG-TESTPOINT-50MIL
P60: SGPIO_CLK; GSG-TESTPOINT-50MIL
P61: DA0; GSG-TESTPOINT-50MIL
P62: DA7; GSG-TESTPOINT-50MIL
P63: DD0; GSG-TESTPOINT-50MIL
P64: DD9; GSG-TESTPOINT-50MIL
P65: DA4; GSG-TESTPOINT-50MIL
P66: DD5; GSG-TESTPOINT-50MIL
P67: RSSI; GSG-TESTPOINT-50MIL
P83, P84, P85, P86, P87, P88, P89, P90, P91, P92: GND; GSG-TESTPOINT-50MIL
Q3: MOSFET_P; SOT23-3; Part Number YJL2301C
R8, R9, R10, R13: 1k; GSG-0402; Part Number RMCF0402FT1K00
R11, R41, R85, R104, R105: 10k; GSG-0402; Part Number RMCF0402JT10K0
R14, R15, R16, R17: 4k7; GSG-0402; Part Number RMCF0402FT4K70
R20, R21, R22, R23: 0; GSG-0402; Part Number RMCF0402ZT0R00
R25, R26: 475; GSG-0402; Part Number RMCF0402JT470R
R27, R28: 1k8; GSG-0402; Part Number RMCF0402JT1K80
R31, R32, R33, R94: 39; GSG-0402; Part Number RMCF0402JT39R0
T3: RX_BALUN; GSG-2500BL14M100; Part Number 2500BL14M100T
T4: TX_BALUN; GSG-2500BL14M100; Part Number 2500BL14M100T
U17: MAX2837; GSG-QFN48-6; Part Number MAX2837ETM+T
U18: MAX5864; GSG-QFN48-7; Part Number MAX5864ETM+T
U19: SI5351C; GSG-QFN20-4; Part Number SI5351C-B-GM
X1: MAIN_XTAL; GSG-XTAL3.2x2.5mm; Part Number ABM8-25.000MHZ-10-D1G-T

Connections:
!VAA_ENABLE: Q3.1 (G), R11.2; also elsewhere on the board
/baseband/CLK0: R31.2, U19.13 (CLK0)
/baseband/CLK1: R32.2, U19.12 (CLK1)
/baseband/CLK2: R94.2, U19.9 (CLK2)
/baseband/CLK3: R33.2, U19.8 (CLK3)
/baseband/CLK5: C115.1, U19.17 (CLK5)
/baseband/COM: C97.1, U18.47 (COM)
/baseband/CPOUT+: C112.2, R25.1, U17.23 (CPOUT+)
/baseband/CPOUT-: C112.1, R26.1, U17.24 (CPOUT-)
/baseband/IA+: C101.1, C110.1, R20.1, U18.3 (IA+)
/baseband/IA-: C101.2, C109.1, R21.1, U18.4 (IA-)
/baseband/ID+: R13.1, U18.45 (ID+)
/baseband/ID-: R10.1, U18.44 (ID-)
/baseband/INTR: P15.1, R104.2, U19.3 (INTR)
/baseband/OEB: P18.1, R105.2, U19.7 (OEB)
/baseband/QA+: C103.2, C107.1, R23.1, U18.10 (QA+)
/baseband/QA-: C103.1, C108.1, R22.1, U18.9 (QA-)
/baseband/QD+: R8.1, U18.40 (QD+)
/baseband/QD-: R9.1, U18.41 (QD-)
/baseband/REFN: C98.1, U18.48 (REFN)
/baseband/REFP: C100.1, U18.1 (REFP)
/baseband/RXBBI+: P9.7, R20.2, U17.38 (RXBBI+)
/baseband/RXBBI-: P9.5, R21.2, U17.37 (RXBBI-)
/baseband/RXBBQ+: P9.6, R22.2, U17.36 (RXBBQ+)
/baseband/RXBBQ-: P9.4, R23.2, U17.35 (RXBBQ-)
/baseband/TXBBI+: C96.1, P9.12, R10.2, R15.1, U17.43 (TXBBI+)
/baseband/TXBBI-: C96.2, P9.10, R13.2, R14.1, U17.42 (TXBBI-)
/baseband/TXBBQ+: C95.2, P9.11, R9.2, R16.1, U17.44 (TXBBQ+)
/baseband/TXBBQ-: C95.1, P9.13, R8.2, R17.1, U17.45 (TXBBQ-)
/baseband/XA: C170.2, U19.1 (XA), X1.3
/baseband/XB: C169.2, U19.2 (XB), X1.1
/baseband/XCVR_CLKOUT: P14.1, U17.16 (CLOCKOUT)
/baseband/XTAL2: C115.2, C116.1, P57.1, U17.17 (XTAL2)
CLK6: U19.16 (CLK6); also elsewhere on the board
CLKIN: D3.2 (K), P16.1 (RF), R85.1, U19.6 (CLKIN); also elsewhere on the board
CLKOUT: C165.1, D9.2 (K), P2.1 (RF), R33.1; also elsewhere on the board
CS_AD: P54.1, U18.36 (CS); also elsewhere on the board
CS_XCVR: P53.1, U17.30 (CS); also elsewhere on the board
DA0: P61.1, U18.13 (DA0); also elsewhere on the board
DA1: U18.14 (DA1); also elsewhere on the board
DA2: U18.15 (DA2); also elsewhere on the board
DA3: U18.16 (DA3); also elsewhere on the board
DA4: P65.1, U18.19 (DA4); also elsewhere on the board
DA5: U18.20 (DA5); also elsewhere on the board
DA6: U18.21 (DA6); also elsewhere on the board
DA7: P62.1, U18.22 (DA7); also elsewhere on the board
DD0: P63.1, U18.23 (DD0); also elsewhere on the board
DD1: U18.24 (DD1); also elsewhere on the board
DD2: U18.25 (DD2); also elsewhere on the board
DD3: U18.26 (DD3); also elsewhere on the board
DD4: U18.27 (DD4); also elsewhere on the board
DD5: P66.1, U18.28 (DD5); also elsewhere on the board
DD6: U18.29 (DD6); also elsewhere on the board
DD7: U18.30 (DD7); also elsewhere on the board
DD8: U18.31 (DD8); also elsewhere on the board
DD9: P64.1, U18.32 (DD9); also elsewhere on the board
GCK1: C68.1, P58.1, R31.1, U18.6 (CLK); also elsewhere on the board
GCK2: C69.1, P59.1, R32.1; also elsewhere on the board
GND: C68.2, C69.2, C71.2, C72.2, C73.2, C74.2, C75.2, C76.2, C77.2, C78.2, C79.2, C80.2, C81.2, C82.2, C83.2, C84.2, C85.2, C86.2, C87.2, C88.2, C89.2, C90.2, C91.2, C92.2, C93.2, C94.2, C97.2, C98.2, C100.2, C105.2, C106.2, C107.2, C108.2, C109.2, C110.2, C113.2, C116.2, C119.2, C120.2, C121.2, C122.2, C123.2, C124.2, C159.2, C165.2, C167.2, C168.2, C169.1, C170.1, D3.1 (A), D9.1 (A), P2.2 (GND), P9.1, P9.2, P9.3, P9.8, P9.9, P9.14, P9.15, P9.16, P16.2 (GND), P83.1, P84.1, P85.1, P86.1, P87.1, P88.1, P89.1, P90.1, P91.1, P92.1, R14.2, R15.2, R16.2, R17.2, R41.1, R85.2, T3.2 (PC), T3.5 (S2), T4.2 (PC), T4.5 (S2), U17.0 (EP), U17.2 (GNDRXLNA), U17.22 (GNDCP), U17.26 (GNDVCO), U18.0 (EP), U18.5 (GND), U18.7 (GND), U18.12 (GND), U18.17 (OGND), U18.37 (GND), U18.42 (GND), U19.0 (GND), X1.2, X1.4; also elsewhere on the board
MCU_CLK: U19.15 (CLK7); also elsewhere on the board
MIX_CLK: U19.19 (CLK4); also elsewhere on the board
unnamed: C99.1, L7.1, U17.4 (RXRF+)
unnamed: C99.2, L6.1, T3.4 (PR2)
unnamed: C102.1, L7.2, U17.5 (RXRF-)
unnamed: C102.2, L6.2, T3.3 (PR1)
unnamed: C104.1, L9.1, U17.10 (TXRF+)
unnamed: C104.2, L8.1, T4.4 (PR2)
unnamed: C105.1, FB2.2, NT3.2
unnamed: C106.1, U17.27 (BYPASS)
unnamed: C111.1, L9.2, U17.11 (TXRF-)
unnamed: C111.2, L8.2, T4.3 (PR1)
unnamed: C114.1, R26.2
unnamed: C114.2, R25.2
unnamed: FB2.1, Q3.3 (D)
RSSI: P67.1, U17.32 (RSSI); also elsewhere on the board
RXENABLE: P56.1, U17.48 (RXENABLE); also elsewhere on the board
RX_IF: T3.1 (S1); also elsewhere on the board
SCL: P37.1, R28.2, U19.4 (SCL); also elsewhere on the board
SDA: P38.1, R27.2, U19.5 (SDA); also elsewhere on the board
SGPIO_CLK: C159.1, P60.1, R94.1; also elsewhere on the board
SSP1_CIPO: C168.1, P41.1, U17.29 (DOUT); also elsewhere on the board
SSP1_COPI: P40.1, U17.31 (DIN), U18.34 (DIN); also elsewhere on the board
SSP1_SCK: P39.1, U17.15 (SCLK), U18.35 (SCLK); also elsewhere on the board
TXENABLE: P55.1, U17.47 (TXENABLE); also elsewhere on the board
TX_IF: T4.1 (S1); also elsewhere on the board
VAA: C71.1, C72.1, C73.1, C74.1, C75.1, C76.1, C77.1, C78.1, C79.1, C80.1, C81.1, C82.1, C83.1, C84.1, C85.1, C86.1, C87.1, C89.1, C90.1, C91.1, C92.1, C93.1, C94.1, NT3.1, U17.1 (VCCRXLNA), U17.7 (VCCTXPAD), U17.13 (VCCTXMX), U17.19 (VCCXTAL), U17.21 (VCCCP), U17.28 (VCCVCO), U17.39 (VCCRXVGA), U17.41 (VCCRXFL), U17.46 (VCCRXMX), U18.2 (VDD), U18.8 (VDD), U18.11 (VDD), U18.33 (VDD), U18.39 (VDD), U18.43 (VDD), U18.46 (REFIN); also elsewhere on the board
VCC: C88.1, C113.1, C119.1, C120.1, C121.1, C122.1, C123.1, C124.1, C167.1, Q3.2 (S), R11.1, R27.1, R28.1, R104.1, R105.1, U17.20 (VCCDIG), U18.18 (OVDD), U19.10 (VDDOB), U19.11 (VDDOA), U19.14 (VDDOD), U19.18 (VDDOC), U19.20 (VDD); also elsewhere on the board
XCVR_EN: R41.2, U17.25 (ENABLE); also elsewhere on the board

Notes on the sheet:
3.3 V CMOS clock input at 10 MHz (or 10 MHz to 100 MHz with firmware modification)
CLK0 is at the sample rate CLK1 is at sample rate x2 CLK2 is at sample rate x2
test points
3.3 V CMOS clock output at 10 MHz (or other frequency with firmware modification)

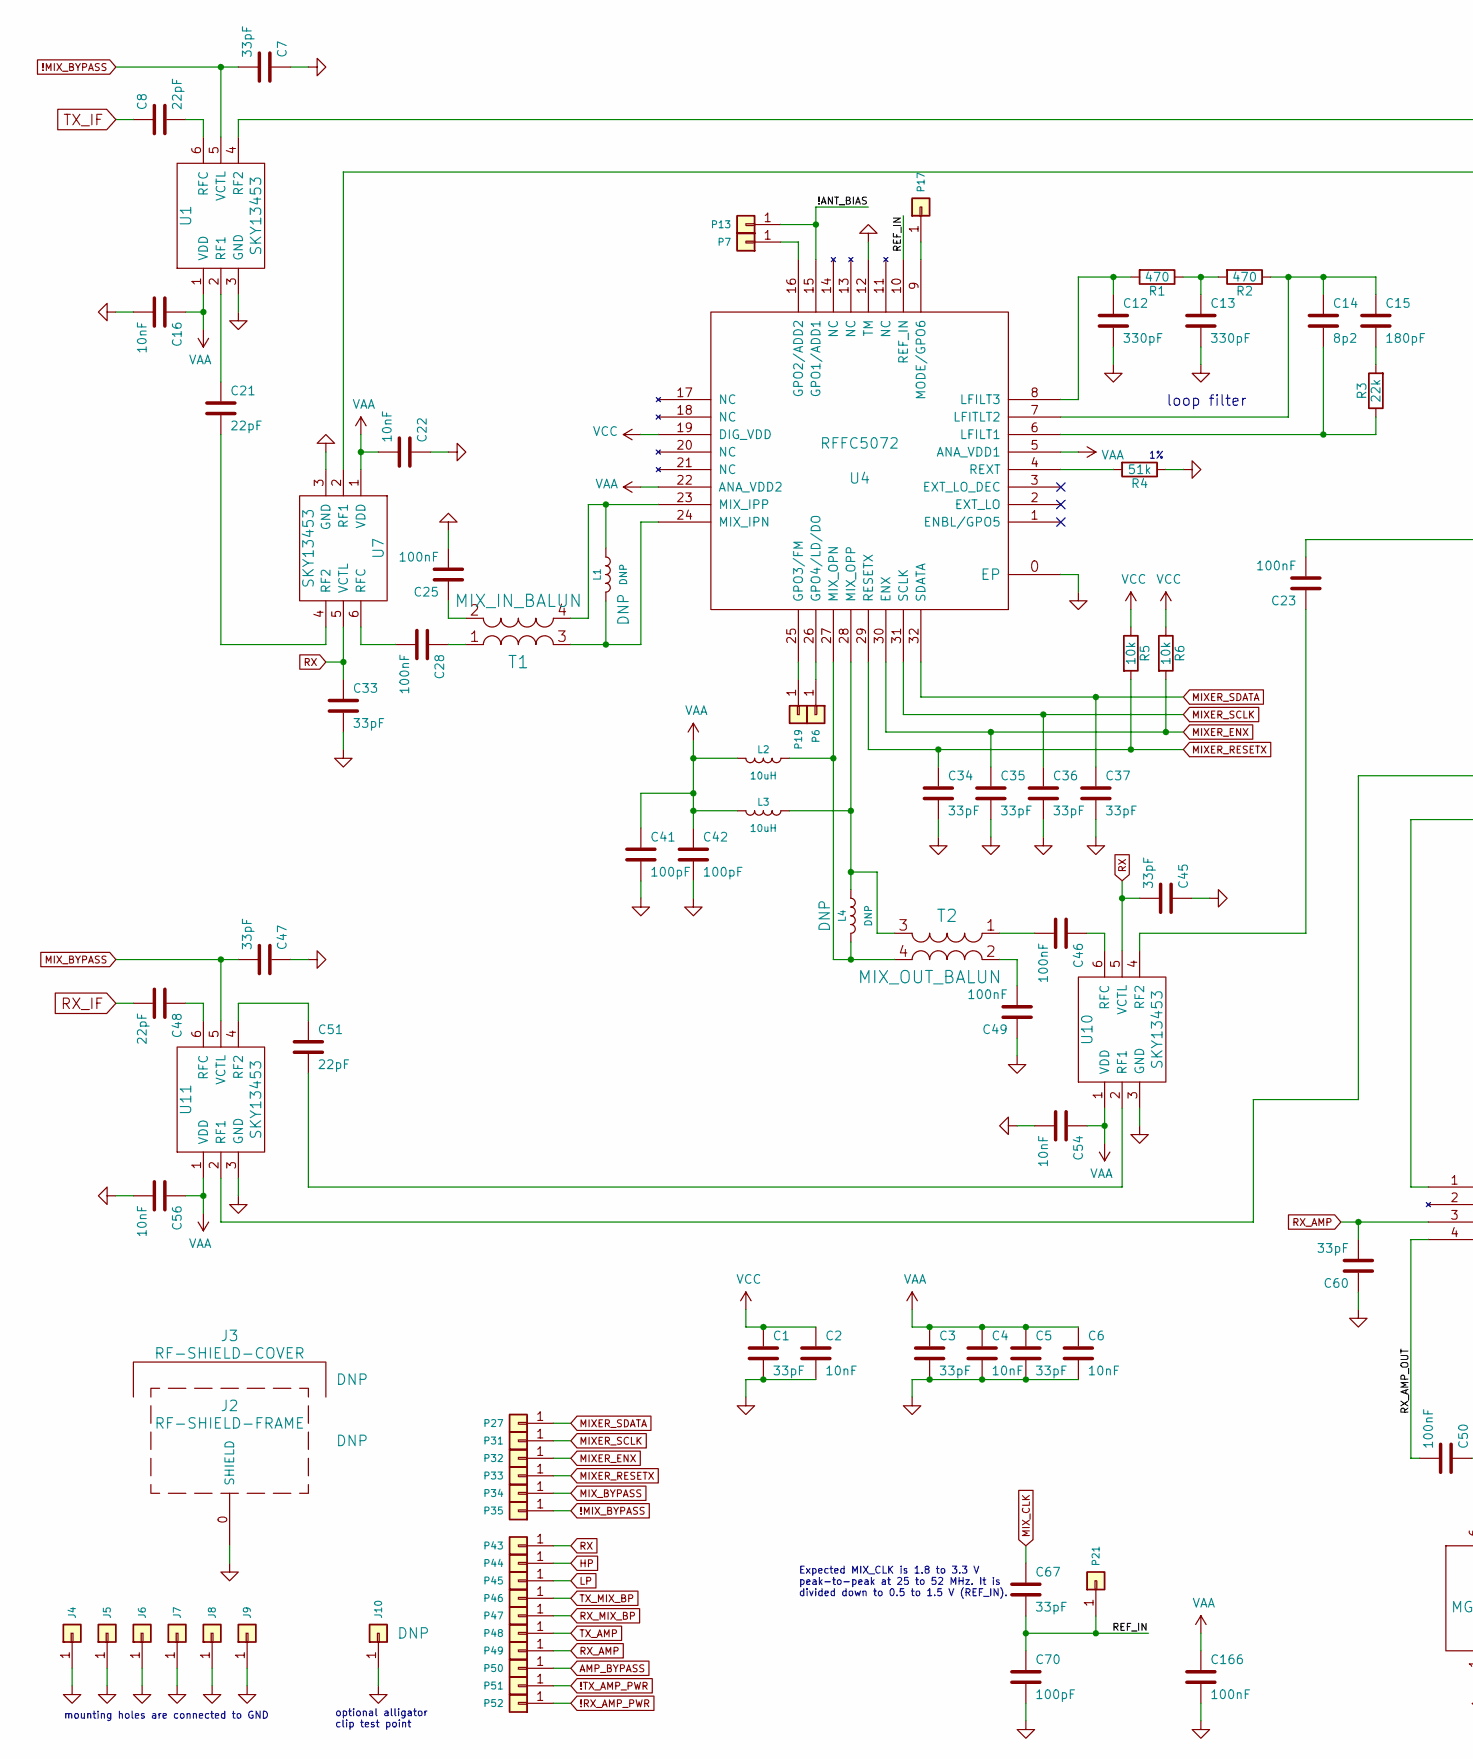
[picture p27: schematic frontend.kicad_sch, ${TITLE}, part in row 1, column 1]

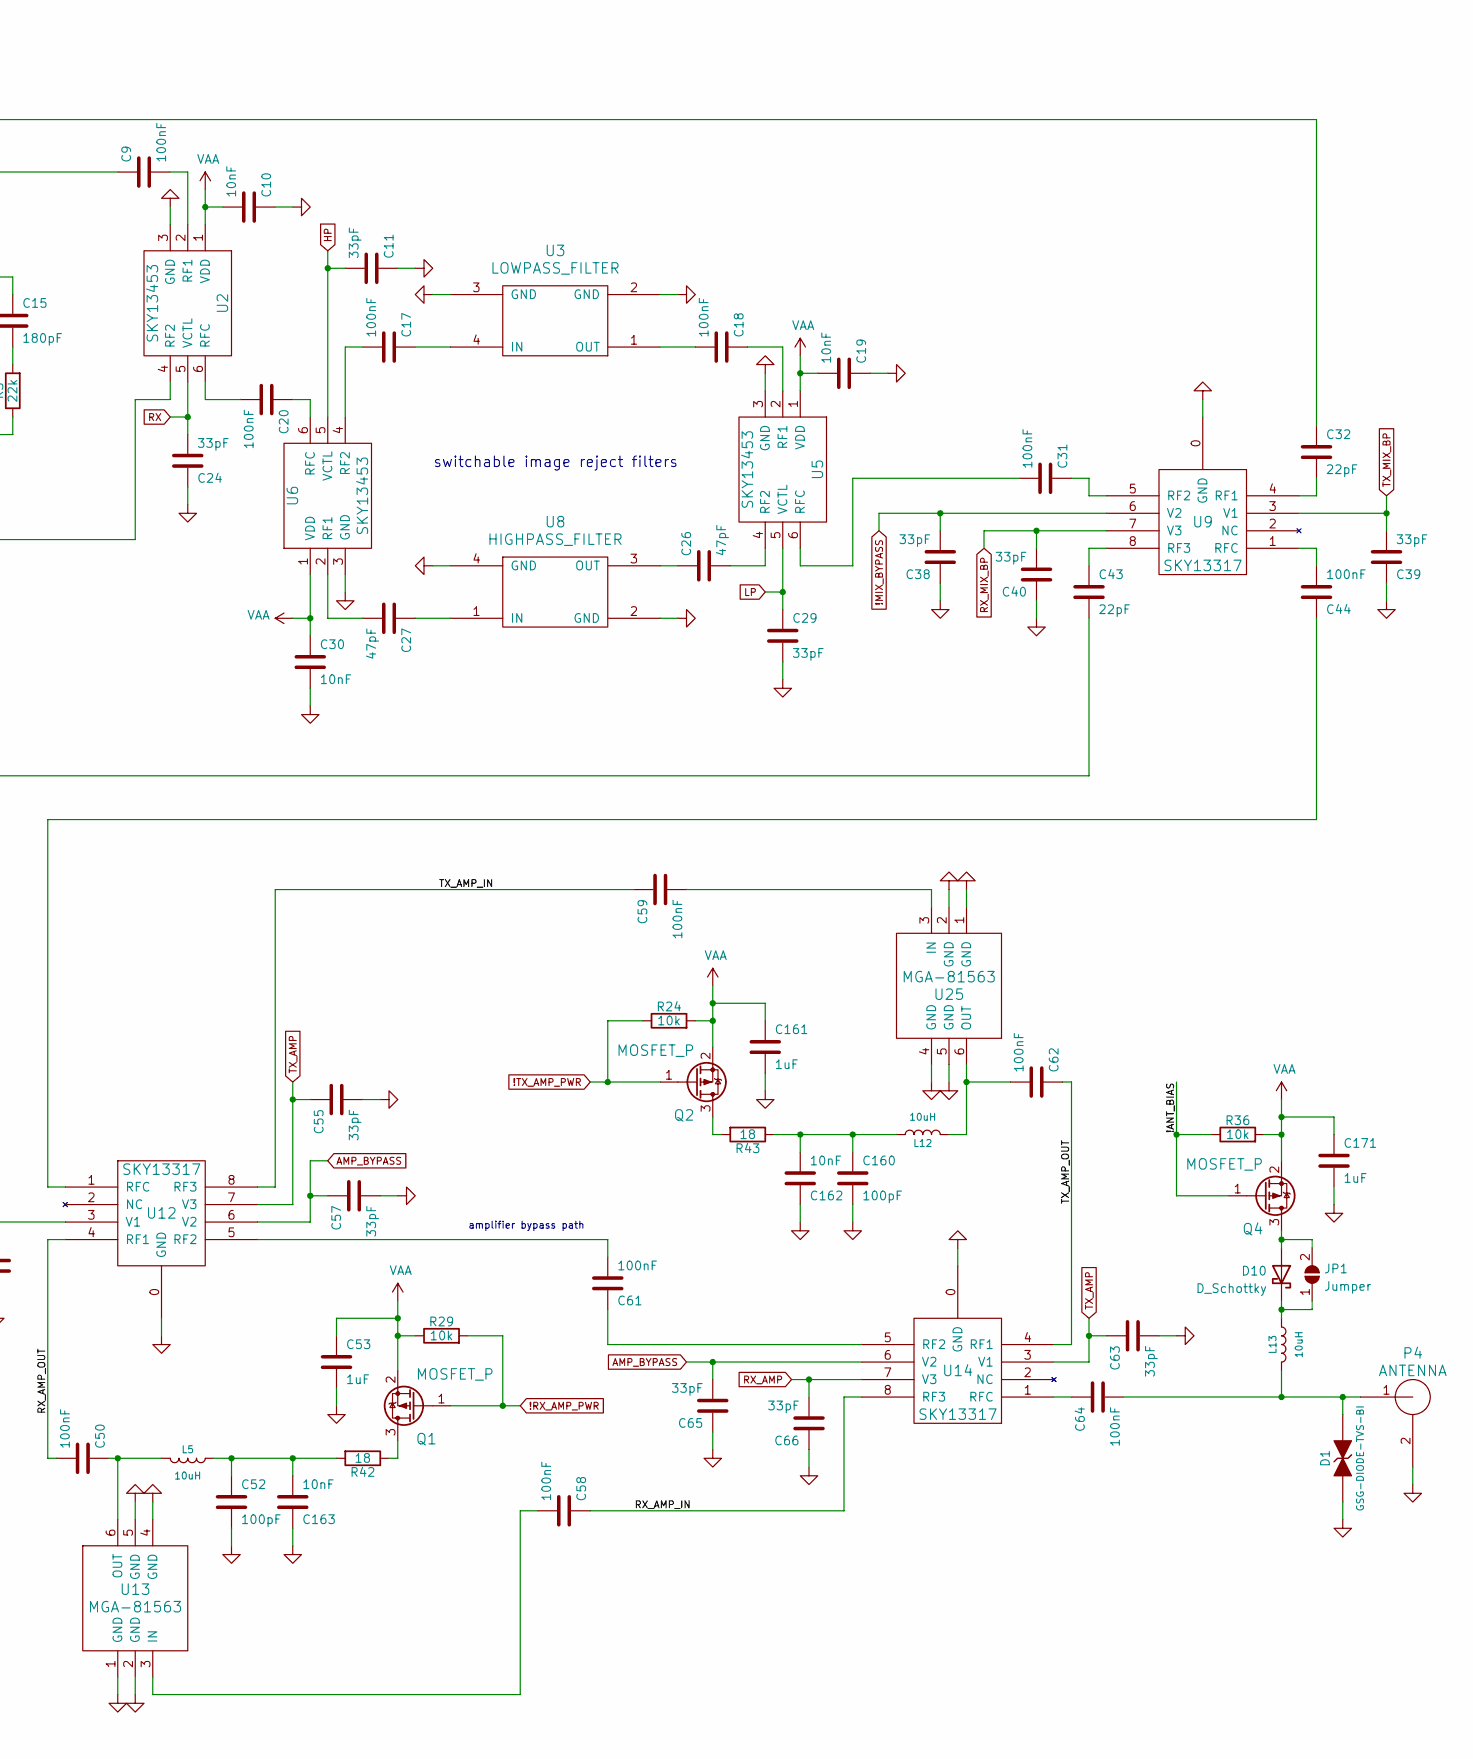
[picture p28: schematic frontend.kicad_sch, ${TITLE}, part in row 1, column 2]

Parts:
C1, C3, C5, C7, C11, C24, C29, C33, C34, C35, C36, C37, C38, C39, C40, C45, C47, C55, C57, C60, C63, C65, C66, C67: 33pF; GSG-0402; Part Number CL05C330JB5NNNC
C2, C4, C6, C10, C16, C19, C22, C30, C54, C56, C162, C163: 10nF; GSG-0402; Part Number CL05B103KB5NNNC
C8, C21, C32, C43, C48, C51: 22pF; GSG-0402; Part Number CL05C220JB5NNNC
C9, C17, C18, C20, C23, C25, C28, C31, C44, C46, C49, C50, C58, C59, C61, C62, C64, C166: 100nF; GSG-0402; Part Number CL05A104KA5NNNC
C12, C13: 330pF; GSG-0402; Part Number CL05C331JB5NNNC
C14: 8p2; GSG-0402; Part Number CC0402CRNPO9BN8R2
C15: 180pF; GSG-0402; Part Number CC0402JRNPO9BN181
C26, C27: 47pF; GSG-0402; Part Number CL05C470JB5NNNC
C41, C42, C52, C70, C160: 100pF; GSG-0402; Part Number CL05C101JB5NNNC
C53, C161, C171: 1uF; GSG-0402; Part Number CL05A105KP5NNNC
D1: GSG-DIODE-TVS-BI; GSG-0402; Part Number LXES15AAA1-100
D10: D_Schottky; DSN1006-2; Part Number PMEG4010ESBYL
J2: RF-SHIELD-FRAME; GSG-SHIELD-BMI-S-230; Part Number BMI-S-230-F-R
J3: RF-SHIELD-COVER; Part Number BMI-S-230-C
J4, J5, J6, J7, J8, J9: MOUNTING_HOLE; GSG-HOLE126MIL-COPPER
J10: GND_CLIP; GSG-TEST-POINT-S1751-46R; Part Number S1751-46R
JP1: Jumper; 0603-JUMPER
L1, L4: DNP; GSG-0402
L2, L3, L5, L12, L13: 10uH; GSG-0603; Part Number BRL1608T100M
P4: ANTENNA; GSG-SMA-73251-2120; Part Number 73251-2121
P6: GPO4; GSG-TESTPOINT-50MIL
P7: GPO2; GSG-TESTPOINT-50MIL
P13: GPO1; GSG-TESTPOINT-50MIL
P17: GPO6; GSG-TESTPOINT-50MIL
P19: GPO3; GSG-TESTPOINT-50MIL
P21: REF_IN; GSG-TESTPOINT-50MIL
P27: MIXER_SDATA; GSG-TESTPOINT-50MIL
P31: MIXER_SCLK; GSG-TESTPOINT-50MIL
P32: MIXER_ENX; GSG-TESTPOINT-50MIL
P33: MIXER_RESETX; GSG-TESTPOINT-50MIL
P34: MIX_BYPASS; GSG-TESTPOINT-50MIL
P35: !MIX_BYPASS; GSG-TESTPOINT-50MIL
P43: RX; GSG-TESTPOINT-50MIL
P44: HP; GSG-TESTPOINT-50MIL
P45: LP; GSG-TESTPOINT-50MIL
P46: TX_MIX_BP; GSG-TESTPOINT-50MIL
P47: RX_MIX_BP; GSG-TESTPOINT-50MIL
P48: TX_AMP; GSG-TESTPOINT-50MIL
P49: RX_AMP; GSG-TESTPOINT-50MIL
P50: AMP_BYPASS; GSG-TESTPOINT-50MIL
P51: !TX_AMP_PWR; GSG-TESTPOINT-50MIL
P52: !RX_AMP_PWR; GSG-TESTPOINT-50MIL
Q1, Q2, Q4: MOSFET_P; SOT23-3; Part Number YJL2301C
R1, R2: 470; GSG-0402; Part Number RMCF0402JT470R
R3: 22k; GSG-0402; Part Number ERJ-2GEJ223X
R4: 51k; GSG-0402; Part Number RMCF0402FT51K0
R5, R6, R24, R29, R36: 10k; GSG-0402; Part Number RMCF0402JT10K0
R42, R43: 18; GSG-0402; Part Number RC0402JR-0718RL
T1: MIX_IN_BALUN; GSG-B0310J50100AHF; Part Number B0310J50100AHF
T2: MIX_OUT_BALUN; GSG-B0310J50100AHF; Part Number B0310J50100AHF
U1, U2, U5, U6, U7, U10, U11: SKY13453; SKY13350-385LF; Part Number SKY13453-385LF
U3: LOWPASS_FILTER; GSG-LP0603; Part Number LP0603A1880ANTR
U4: RFFC5072; GSG-QFN32; Part Number RFFC5072TR7
U8: HIGHPASS_FILTER; GSG-HP-DEA; Part Number DEA162400HT-8004B1
U9, U12, U14: SKY13317; GSG-SKY13317-373LF; Part Number SKY13317-373LF
U13, U25: MGA-81563; GSG-SOT363; Part Number MGA-81563-TR1G

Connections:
!MIX_BYPASS: C7.2, C38.2, P35.1, U1.5 (VCTL), U9.6 (V2); also elsewhere on the board
!RX_AMP_PWR: P52.1, Q1.1 (G), R29.2; also elsewhere on the board
!TX_AMP_PWR: P51.1, Q2.1 (G), R24.1; also elsewhere on the board
/frontend/!ANT_BIAS: P13.1, Q4.1 (G), R36.1, U4.15 (GPO1/ADD1)
/frontend/REF_IN: C67.2, C70.1, P21.1, U4.10 (REF_IN)
/frontend/RX_AMP_IN: C58.1, U14.8 (RF3)
/frontend/RX_AMP_OUT: C50.2, U12.4 (RF1)
/frontend/TX_AMP_IN: C59.1, U12.8 (RF3)
/frontend/TX_AMP_OUT: C62.1, U14.4 (RF1)
AMP_BYPASS: C57.1, C65.2, P50.1, U12.6 (V2), U14.6 (V2); also elsewhere on the board
GND: C1.2, C2.2, C3.2, C4.2, C5.2, C6.2, C7.1, C10.1, C11.1, C12.2, C13.2, C16.2, C19.1, C22.1, C24.1, C25.2, C29.2, C30.2, C33.2, C34.2, C35.2, C36.2, C37.2, C38.1, C39.1, C40.1, C41.2, C42.2, C45.1, C47.1, C49.1, C52.2, C53.2, C54.2, C55.2, C56.2, C57.2, C60.1, C63.2, C65.1, C66.1, C70.2, C160.2, C161.2, C162.1, C163.1, C166.2, C171.2, D1.1 (A), J2.0 (SHIELD), J4.1, J5.1, J6.1, J7.1, J8.1, J9.1, J10.1, P4.2 (GND), R4.1, U1.3 (GND), U2.3 (GND), U3.2 (GND), U3.3 (GND), U4.0 (EP), U4.12 (TM), U5.3 (GND), U6.3 (GND), U7.3 (GND), U8.2 (GND), U8.4 (GND), U9.0 (GND), U10.3 (GND), U11.3 (GND), U12.0 (GND), U13.1 (GND), U13.2 (GND), U13.4 (GND), U13.5 (GND), U14.0 (GND), U25.1 (GND), U25.2 (GND), U25.4 (GND), U25.5 (GND); also elsewhere on the board
HP: C11.2, P44.1, U6.5 (VCTL); also elsewhere on the board
LP: C29.1, P45.1, U5.5 (VCTL); also elsewhere on the board
MIXER_ENX: C35.1, P32.1, R6.2, U4.30 (ENX); also elsewhere on the board
MIXER_RESETX: C34.1, P33.1, R5.2, U4.29 (RESETX); also elsewhere on the board
MIXER_SCLK: C36.1, P31.1, U4.31 (SCLK); also elsewhere on the board
MIXER_SDATA: C37.1, P27.1, U4.32 (SDATA); also elsewhere on the board
MIX_BYPASS: C47.2, P34.1, U11.5 (VCTL); also elsewhere on the board
MIX_CLK: C67.1; also elsewhere on the board
unnamed: C8.2, U1.6 (RFC)
unnamed: C9.1, U7.2 (RF1)
unnamed: C9.2, U2.2 (RF1)
unnamed: C12.1, R1.2, U4.8 (LFILT3)
unnamed: C13.1, R1.1, R2.2
unnamed: C14.1, C15.1, R2.1, U4.7 (LFITLT2)
unnamed: C14.2, R3.1, U4.6 (LFILT1)
unnamed: C15.2, R3.2
unnamed: C17.1, U3.4 (IN)
unnamed: C17.2, U6.4 (RF2)
unnamed: C18.1, U5.2 (RF1)
unnamed: C18.2, U3.1 (OUT)
unnamed: C20.1, U6.6 (RFC)
unnamed: C20.2, U2.6 (RFC)
unnamed: C21.1, U1.2 (RF1)
unnamed: C21.2, U7.4 (RF2)
unnamed: C23.1, U10.4 (RF2)
unnamed: C23.2, U2.4 (RF2)
unnamed: C25.1, T1.2 (S2)
unnamed: C26.1, U8.3 (OUT)
unnamed: C26.2, U5.4 (RF2)
unnamed: C27.1, U8.1 (IN)
unnamed: C27.2, U6.2 (RF1)
unnamed: C28.1, T1.1 (S1)
unnamed: C28.2, U7.6 (RFC)
unnamed: C31.1, U9.5 (RF2)
unnamed: C31.2, U5.6 (RFC)
unnamed: C32.1, U1.4 (RF2)
unnamed: C32.2, U9.4 (RF1)
unnamed: C43.1, U9.8 (RF3)
unnamed: C43.2, U11.2 (RF1)
unnamed: C44.1, U12.1 (RFC)
unnamed: C44.2, U9.1 (RFC)
unnamed: C46.1, U10.6 (RFC)
unnamed: C46.2, T2.1 (S1)
unnamed: C48.1, U11.6 (RFC)
unnamed: C49.2, T2.2 (S2)
unnamed: C50.1, L5.2, U13.6 (OUT)
unnamed: C51.1, U11.4 (RF2)
unnamed: C51.2, U10.2 (RF1)
unnamed: C58.2, U13.3 (IN)
unnamed: C59.2, U25.3 (IN)
unnamed: C61.1, U14.5 (RF2)
unnamed: C61.2, U12.5 (RF2)
unnamed: C62.2, L12.2, U25.6 (OUT)
unnamed: C64.1, U14.1 (RFC)
unnamed: C64.2, D1.2 (K), L13.2, P4.1 (RF)
unnamed: C160.1, C162.2, L12.1, R43.1
unnamed: C52.1, C163.2, L5.1, R42.2
unnamed: D10.1 (K), JP1.1 (A), L13.1
unnamed: D10.2 (A), JP1.2 (B), Q4.3 (D)
unnamed: L1.1, T1.4 (PR2), U4.23 (MIX_IPP)
unnamed: L1.2, T1.3 (PR1), U4.24 (MIX_IPN)
unnamed: L2.1, L4.2, T2.4 (PR2), U4.27 (MIX_OPN)
unnamed: L3.1, L4.1, T2.3 (PR1), U4.28 (MIX_OPP)
unnamed: P6.1, U4.26 (GPO4/LD/DO)
unnamed: P7.1, U4.16 (GPO2/ADD2)
unnamed: P17.1, U4.9 (MODE/GPO6)
unnamed: P19.1, U4.25 (GPO3/FM)
unnamed: Q1.3 (D), R42.1
unnamed: Q2.3 (D), R43.2
unnamed: R4.2, U4.4 (REXT)
RX: C24.2, C33.1, C45.2, P43.1, U2.5 (VCTL), U7.5 (VCTL), U10.5 (VCTL); also elsewhere on the board
RX_AMP: C60.2, C66.2, P49.1, U12.3 (V1), U14.7 (V3); also elsewhere on the board
RX_IF: C48.2; also elsewhere on the board
RX_MIX_BP: C40.2, P47.1, U9.7 (V3); also elsewhere on the board
TX_AMP: C55.1, C63.1, P48.1, U12.7 (V3), U14.3 (V1); also elsewhere on the board
TX_IF: C8.1; also elsewhere on the board
TX_MIX_BP: C39.2, P46.1, U9.3 (V1); also elsewhere on the board
VAA: C3.1, C4.1, C5.1, C6.1, C10.2, C16.1, C19.2, C22.2, C30.1, C41.1, C42.1, C53.1, C54.1, C56.1, C161.1, C166.1, C171.1, L2.2, L3.2, Q1.2 (S), Q2.2 (S), Q4.2 (S), R24.2, R29.1, R36.2, U1.1 (VDD), U2.1 (VDD), U4.5 (ANA_VDD1), U4.22 (ANA_VDD2), U5.1 (VDD), U6.1 (VDD), U7.1 (VDD), U10.1 (VDD), U11.1 (VDD); also elsewhere on the board
VCC: C1.1, C2.1, R5.1, R6.1, U4.19 (DIG_VDD); also elsewhere on the board

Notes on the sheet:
optional alligator clip test point
mounting holes are connected to GND
Expected MIX_CLK is 1.8 to 3.3 V peak-to-peak at 25 to 52 MHz. It is divided down to 0.5 to 1.5 V (REF_IN).
switchable image reject filters
amplifier bypass path
loop filter

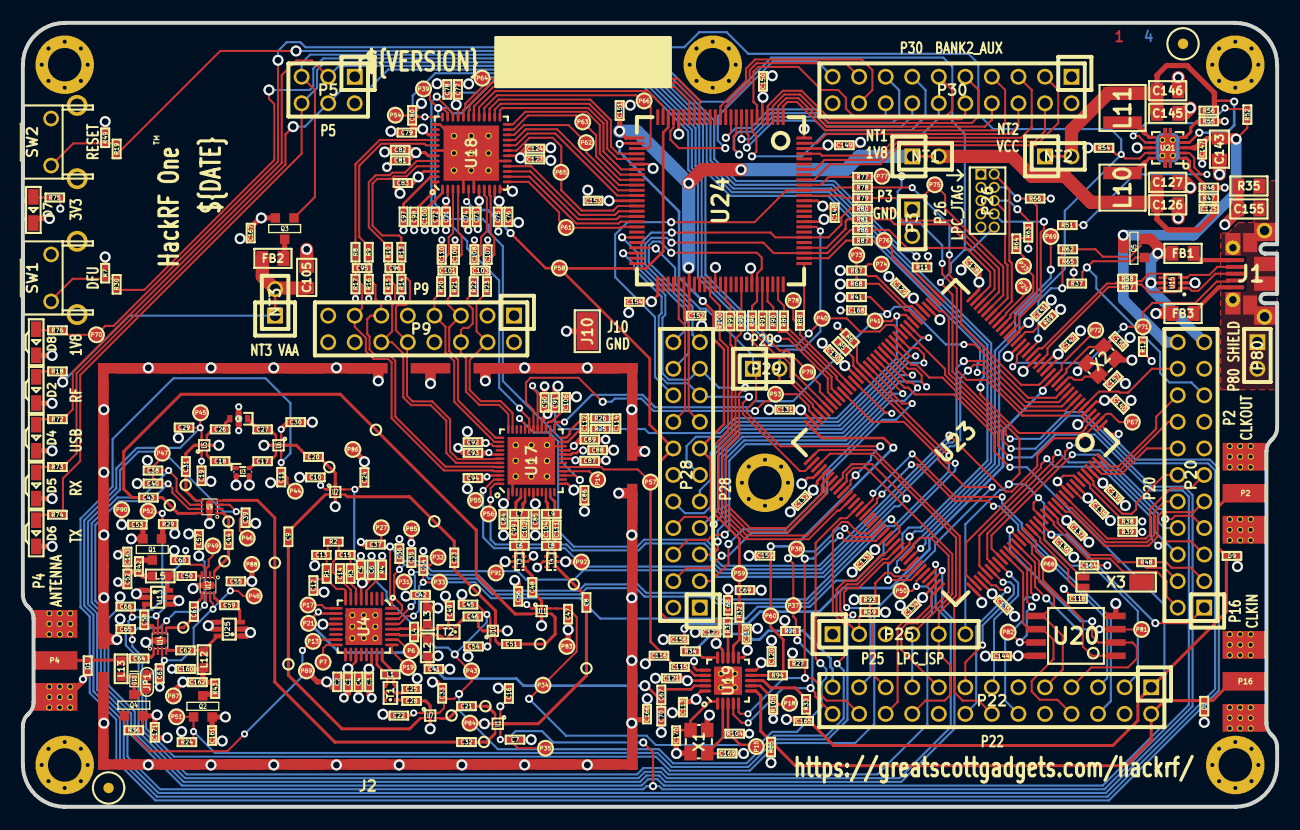
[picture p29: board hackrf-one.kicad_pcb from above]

Board: 4 copper layers, 120.0 x 75.0 mm, 437 parts (0 on the bottom side), 319 nets.

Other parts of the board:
FID1, FID2: FIDUCIAL; GSG-MARK1MM
TESTPOINT-30MIL-MASKONLY, TESTPOINT-30MIL-MASKONLY#2, TESTPOINT-30MIL-MASKONLY#3, TESTPOINT-30MIL-MASKONLY#4, TESTPOINT-30MIL-MASKONLY#5, TESTPOINT-30MIL-MASKONLY#6, TESTPOINT-30MIL-MASKONLY#7, TESTPOINT-30MIL-MASKONLY#8, TESTPOINT-30MIL-MASKONLY#9, TESTPOINT-30MIL-MASKONLY#10, TESTPOINT-30MIL-MASKONLY#11, TESTPOINT-30MIL-MASKONLY#12, TESTPOINT-30MIL-MASKONLY#13, TESTPOINT-30MIL-MASKONLY#14, TESTPOINT-30MIL-MASKONLY#15, TESTPOINT-30MIL-MASKONLY#16, TESTPOINT-30MIL-MASKONLY#17: VAL**; GSG-TESTPOINT-30MIL-MASKONLY

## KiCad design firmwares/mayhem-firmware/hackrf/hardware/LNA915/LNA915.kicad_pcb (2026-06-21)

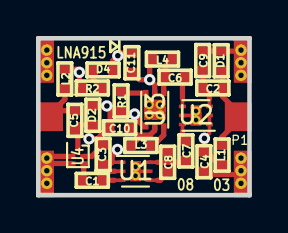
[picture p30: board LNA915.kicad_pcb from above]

Board: 4 copper layers, 11.7 x 8.7 mm, 25 parts (0 on the bottom side), 17 nets.

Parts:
C1, C2, C3, C4, C5, C6, C7, C8: 100pF; 0402
C9: 1 pF; 0402
C10, C11: 1uF; 0402
D1, D2: D_TVS; 0402
D4: LNALED; 0402
L1, L2, L3, L4: 39nH; 0402
P1: SMA-KIT-1.5MF
R1: 3k; 0402
R2: 470; 0402
U1, U2: SWITCH; GRF6011
U3: LNA; TSLP-7-1
U4: SAW; F5Q

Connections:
GND: C3.1, C4.1, C9.2, C10.1, C11.1, D1.1, D2.1, D4.1, P1.2, P1.4, U1.5, U1.7, U2.5, U2.7, U3.7, U4.2, U4.3, U4.5
unnamed: C1.1, U4.4
unnamed: C1.2, U1.3
unnamed: C2.1, C9.1, U2.3
unnamed: C2.2, D1.2, L1.1, P1.1
unnamed: C5.1, L2.1, P1.3
unnamed: C5.2, D2.2, U4.1
unnamed: C6.1, L4.2, U3.4
unnamed: C6.2, U2.4
unnamed: C7.1, U1.6
unnamed: C7.2, U2.6
unnamed: C8.1, U1.4
unnamed: C8.2, L3.1, U3.3
unnamed: C10.2, L3.2, U3.2
unnamed: D4.2, R2.2
unnamed: R1.2, U3.6
VCC: C3.2, C4.2, C11.2, L1.2, L2.2, L4.1, R1.1, R2.1, U1.1, U1.2, U2.1, U2.2, U3.1, U3.5

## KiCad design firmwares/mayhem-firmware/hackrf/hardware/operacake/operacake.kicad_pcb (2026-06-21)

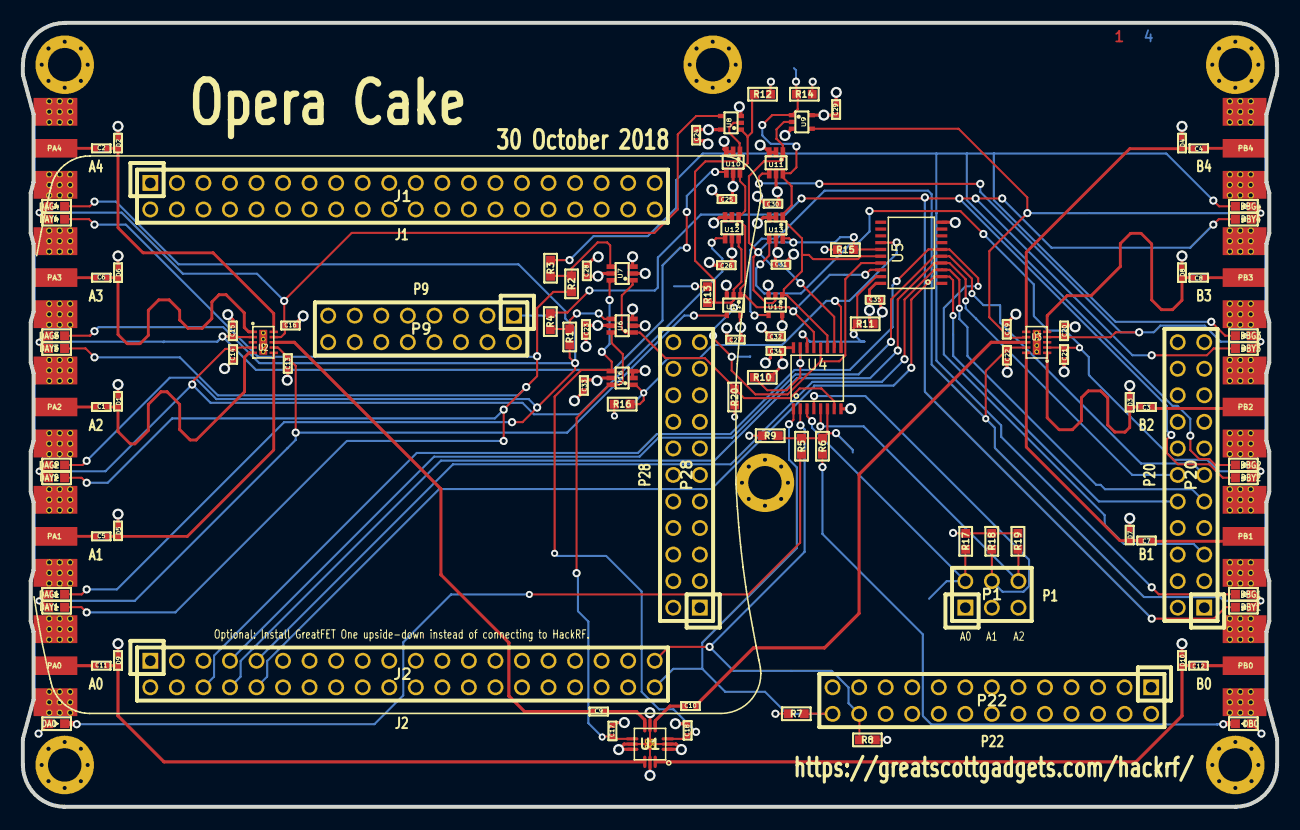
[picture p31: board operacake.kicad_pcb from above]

Board: 4 copper layers, 120.0 x 75.0 mm, 152 parts (0 on the bottom side), 63 nets.

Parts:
C1, C2, C3, C4, C5, C6, C7, C8, C9, C10, C11, C12, C23, C24, C25, C26, C27, C28, C29, C30, C31, C32, C33, C34, C35: 100nF; 0402
C13, C14, C15, C16, C17, C18, C19, C20, C21, C22: 33pF; 0402
D1, D2, D3, D4, D5, D6, D7, D8, D9, D10: GSG-DIODE-TVS-BI; 0402
DA0: LED; 0603D
DAG1, DAG2, DAG3, DAG4: LED; 0603D
DAY1, DAY2, DAY3, DAY4: LED; 0603D
DB0: LED; 0603D
DBG1, DBG2, DBG3, DBG4: LED; 0603D
DBY1, DBY2, DBY3, DBY4: LED; 0603D
J1, J2: CONN_02X20; HEADER-2x20-REVERSE
MH1, MH2, MH3, MH4, MH5, MH6: MOUNTING_HOLE; HOLE126MIL-COPPER
P1: ADDRESS; HEADER-2x3
P9: BASEBAND; HEADER-2x8
P20: GPIO; HEADER-2x11
P22: I2S; HEADER-2x13
P28: SD; HEADER-2x11
PA0, PA1, PA2, PA3, PA4: GSG-RF-CONN; GSG-SMA-73251-2120
PB0, PB1, PB2, PB3, PB4: GSG-RF-CONN; GSG-SMA-73251-2120
R1, R2, R3, R4, R5, R6: 330; 0603
R7, R8: 1k8; 0603
R9, R10, R11, R12, R13, R14, R15, R16, R17, R18, R19, R20: 10k; 0603
TP1, TP2, TP3, TP4, TP5, TP6, TP7, TP8, TP9, TP10, TP11, TP12, TP13, TP14, TP15, TP16, TP17, TP18, TP19, TP20, TP21, TP22, TP23, TP24, TP25, TP26, TP27, TP28, TP29, TP30: CONN_1; TESTPOINT-50MIL
U1: MASWSS0129; QFN12-3
U2, U3: SKY13322; SKY13322-375LF
U4: PCA9557; TSSOP16
U5: TC7MBL3245CFT; TSSOP20
U6, U7, U10, U11, U12, U13: 74LVC1G58; SOT363
U8, U9: 74AHC1G08; SOT353-1
U14, U15: 74AHC1G02; SOT353-1
U16: 74LVC1G19; SOT363

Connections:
/!LED_EN: R5.2, R6.2, R9.2, TP6.1, U4.6
/!OE: R11.1, TP8.1, U4.14, U5.19
/!RESET: R10.1, TP7.1, U4.15
/A0: P1.2, R17.1, TP28.1, U4.3
/A1: P1.4, R18.1, TP29.1, U4.4
/A2: P1.6, R19.1, TP30.1, U4.5
/EXT_U1CTRL: J2.6, P20.5, TP5.1, U5.6
/EXT_U2CTRL0: J2.9, P20.9, TP2.1, U5.3
/EXT_U2CTRL1: J2.10, P20.10, TP1.1, U5.2
/EXT_U3CTRL0: J2.7, P20.11, TP4.1, U5.5
/EXT_U3CTRL1: J2.8, P20.12, TP3.1, U5.4
/LED_EN2: R20.1, U4.7, U6.1, U7.1
/SCL: J2.40, P22.26, R7.2, TP27.1, U4.1
/SDA: J2.39, P22.24, R8.2, TP26.1, U4.2
/U1CTRL: R16.1, TP9.1, U4.9, U5.14, U16.1
/U1VC1: C18.2, TP16.1, U1.3, U7.6, U16.4
/U1VC2: C17.2, TP17.1, U1.7, U6.6, U16.6
/U2CTRL0: R13.1, TP10.1, U4.12, U5.17, U8.2, U10.1, U12.6, U14.2
/U2CTRL1: R12.1, TP11.1, U4.13, U5.18, U8.1, U10.6, U12.1, U14.1
/U2V1: C14.1, DAG2.2, DAY2.2, TP18.1, U2.4, U12.4
/U2V2: C15.2, DAG3.2, DAY3.2, TP19.1, U2.2, U10.4
/U2V3: C13.1, DAG1.2, DAY1.2, TP20.1, U2.7, U14.4
/U2V4: C16.2, DAG4.2, DAY4.2, TP21.1, U2.9, U8.4
/U3CTRL0: R15.1, TP12.1, U4.10, U5.15, U9.2, U11.1, U13.6, U15.2
/U3CTRL1: R14.1, TP13.1, U4.11, U5.16, U9.1, U11.6, U13.1, U15.1
/U3V1: C20.1, DBG3.2, DBY3.2, TP22.1, U3.4, U11.4
/U3V2: C21.2, DBG2.2, DBY2.2, TP23.1, U3.2, U13.4
/U3V3: C19.1, DBG4.2, DBY4.2, TP24.1, U3.7, U9.4
/U3V4: C22.2, DBG1.2, DBY1.2, TP25.1, U3.9, U15.4
GND: C13.2, C14.2, C15.1, C16.1, C17.1, C18.1, C19.2, C20.2, C21.1, C22.1, C23.1, C24.1, C25.1, C26.1, C27.1, C28.1, C29.1, C30.1, C31.1, C32.1, C33.1, C34.1, C35.1, D1.2, D2.2, D3.2, D4.2, D5.2, D6.2, D7.2, D8.2, D9.2, D10.2, J1.1, J2.1, MH1.1, MH2.1, MH3.1, MH4.1, MH5.1, MH6.1, P9.1, P9.2, P9.3, P9.8, P9.9, P9.14, P9.15, P9.16, P20.15, P20.19, P22.4, P22.10, P22.18, P28.2, P28.12, PA0.2, PA1.2, PA2.2, PA3.2, PA4.2, PB0.2, PB1.2, PB2.2, PB3.2, PB4.2, R17.2, R18.2, R19.2, R20.2, TP14.1, U1.0, U1.1, U1.2, U1.5, U1.8, U1.9, U1.11, U2.0, U3.0, U4.8, U5.10, U6.2, U7.2, U8.3, U9.3, U10.2, U10.3, U11.2, U11.3, U12.2, U12.3, U13.2, U13.3, U14.3, U15.3, U16.2, U16.3
unnamed: C1.1, D1.1, U2.5
unnamed: C1.2, PA2.1
unnamed: C2.1, D2.1, U2.10
unnamed: C2.2, PA4.1
unnamed: C3.1, D3.1, U3.1
unnamed: C3.2, PB2.1
unnamed: C4.1, D4.1, U3.6
unnamed: C4.2, PB4.1
unnamed: C5.1, D5.1, U2.6
unnamed: C5.2, PA1.1
unnamed: C6.1, D6.1, U2.1
unnamed: C6.2, PA3.1
unnamed: C7.1, D7.1, U3.10
unnamed: C7.2, PB1.1
unnamed: C8.1, D8.1, U3.5
unnamed: C8.2, PB3.1
unnamed: C9.1, U1.6
unnamed: C9.2, U2.8
unnamed: C10.1, U3.8
unnamed: C10.2, U1.4
unnamed: C11.1, D9.1, U1.10
unnamed: C11.2, PA0.1
unnamed: C12.1, D10.1, U1.12
unnamed: C12.2, PB0.1
unnamed: DA0.1, R5.1
unnamed: DAG1.1, DAG2.1, DAG3.1, DAG4.1, R1.1
unnamed: DAY1.1, DAY2.1, DAY3.1, DAY4.1, R2.1
unnamed: DB0.1, R6.1
unnamed: DBG1.1, DBG2.1, DBG3.1, DBG4.1, R3.1
unnamed: DBY1.1, DBY2.1, DBY3.1, DBY4.1, R4.1
unnamed: R1.2, R4.2, U6.4
unnamed: R2.2, R3.2, U7.4
VCC: C23.2, C24.2, C25.2, C26.2, C27.2, C28.2, C29.2, C30.2, C31.2, C32.2, C33.2, C34.2, C35.2, DA0.2, DB0.2, J1.2, P1.1, P1.3, P1.5, P20.3, P22.11, P28.1, R7.1, R8.1, R9.1, R10.2, R11.2, R12.2, R13.2, R14.2, R15.2, R16.2, TP15.1, U4.16, U5.20, U6.3, U6.5, U7.3, U7.5, U8.5, U9.5, U10.5, U11.5, U12.5, U13.5, U14.5, U15.5, U16.5

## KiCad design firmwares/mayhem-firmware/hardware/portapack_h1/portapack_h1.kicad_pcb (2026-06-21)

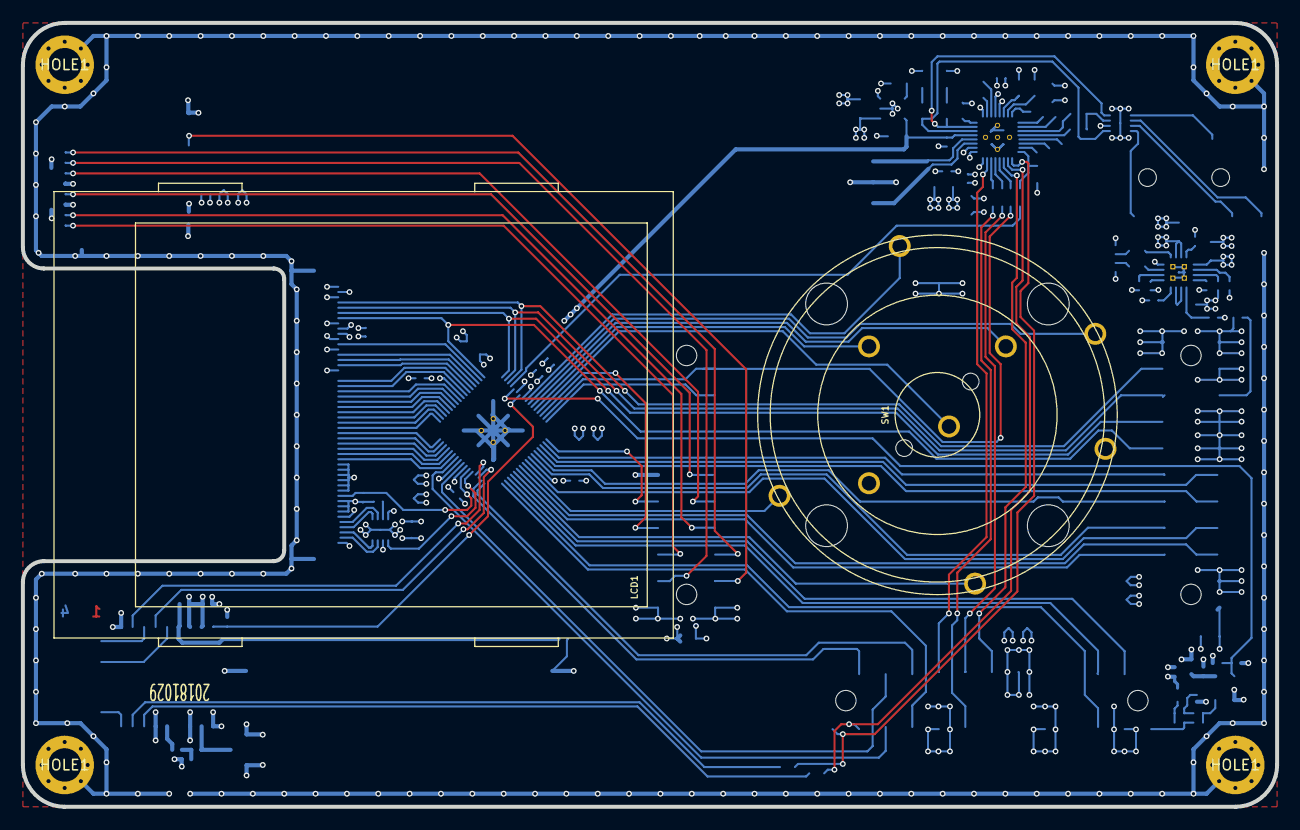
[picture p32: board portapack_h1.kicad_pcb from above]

Board: 4 copper layers, 120.0 x 75.0 mm, 111 parts (0 on the bottom side), 139 nets.

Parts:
BT1: BATTERY; MPD_BU2032SM-BT-G
C1: 1U; IPC_CAPC200X125X135L45N
C2, C3, C4, C5, C9, C18, C20, C27, C28, C29, C30, C31, C33, C35: 100N; IPC_CAPC100X50X55L25N
C6, C8, C10, C12: 2U2; IPC_CAPC160X80X90L35N
C7, C11, C13, C26, C32, C34, C36, C37, C38, C40, C41, C42, C43: 10U; IPC_CAPC200X125X135L45N
C14, C25: 1U; IPC_CAPC160X80X90L35N
C15, C16: 4U7; IPC_CAPC200X125X135L45N
C17: 1N; IPC_CAPC100X50X55L25N
C19: 10N; IPC_CAPC100X50X55L25N
C22, C23: 220N; IPC_CAPC160X80X90L35N
C39: R; IPC_CAPC160X80X90L35N
D1: LED 0603 green; IPC_LEDC1608X90L40N
D2: LED 0603 yellow; IPC_LEDC1608X90L40N
FB1, FB2, FB3: FBEAD; IPC_BEADC160X80X95L40N
FID1, FID2, FID3: FIDUCIAL; FIDUCIAL_65MIL
H2, H3, H4, H5: HOLE1; HOLE_3200UM_VIAS
J1: HEADER_1X3; JST_S3B-PH-SM4-TB
J2: MICROSD_DETSW; ALPS_SCHA4B0419
J3: ER-TFT024-3_FPC; ER-CON50HT-1
J4: HEADER_1X2; JST_S2B-PH-SM4-TB
L1: 27N; IPC_INDC100X50X60L20N
LCD1: ER-TFT024-3_PANEL; ER-TFT024-3
P1: CONN_COAX; 1909763-1
P2: TRRS_SW_JACK; CUI_SJ-43516-SMT
P20: HACKRF_ONE_P20; HEADER_11X2_REV_SM_254_AP
P22: HACKRF_ONE_P22; HEADER_13X2_REV_SM_254_AP
P28: HACKRF_ONE_P28; HEADER_11X2_REV_SM_254_AP
R1: R; IPC_RESC100X50X40L25N
R2: 10K; IPC_RESC160X80X55L25N
R3, R5: 1K5; IPC_RESC100X50X40L25N
R4: 1K91; IPC_RESC100X50X40L25N
R6: 1K8; IPC_RESC100X50X40L25N
R7, R23, R24: 0R; IPC_RESC100X50X40L25N
R8, R9, R10, R13, R14, R15, R16, R19: 10K; IPC_RESC100X50X40L25N
R11, R12: 33R; IPC_RESC160X80X55L25N
R17: 1M; IPC_RESC100X50X40L25N
R18: 2K2; IPC_RESC160X80X55L25N
R20: 3K9; IPC_RESC100X50X40L25N
R21: 100R; IPC_RESC100X50X40L25N
R22: 33R; IPC_RESC100X50X40L25N
R25: 100K; IPC_RESC100X50X40L25N
R26: 10R; IPC_RESC100X50X40L25N
RP1: 220R; IPC_RESCAXS8P80_320X160X60L30X45N
SW1: CK_TSWB-3N-CB; CK_TSWB-3N-CB222_LFS
TP1, TP2, TP3, TP4, TP5, TP6, TP7, TP8, TP9: TP; TP_1MM
U1: AK4951EN; IPC_QFN33P40_400X400X80L35X20T280N
U2: TCR2EF18,LM(CT; IPC_SOT23-5P95_275X135L40X40N
U3: 5M40ZE64; IPC_QFP65P40_900X900X120L60X18T450N
U4: CAT4004[_AB]; IPC_SON9P50_200X200X55L32X24T90X160N
U5: NUF4220MN; IPC_SON9P50_200X200X100L30X25T80X120N
U6: BQ24075RGT; IPC_QFN17P50_300X300X100L40X25T160N
U7: 74HC1G04GW; IPC_SOT23-5P65_212X110L33X22N
U8: MAX-M8
X1: 10.00000M; IPC_OSCCC320X250X110L75X100N

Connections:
+1V8: C3.1, C29.1, C31.1, C33.1, C35.1, C36.1, C37.1, C40.1, J3.6, J3.40, J3.41, U1.21, U2.5, U3.8, U3.39, U3.41, U3.57
+3V3: C2.1, C4.1, C7.1, C11.1, C14.1, C18.1, C20.1, C26.1, C27.1, C28.1, C30.1, C32.1, C34.1, C38.1, C42.1, C43.1, FB2.1, J2.4, J3.1, J3.42, P20.3, P22.11, P28.1, R15.1, R23.2, U1.16, U1.28, U2.1, U2.3, U3.6, U3.23, U4.8, U7.5, U8.7, U8.8
/audio/BICK: P22.16, RP1.8
/audio/BICK_R: RP1.1, U1.14
/audio/CN: C6.2, U1.27
/audio/CP: C6.1, U1.26
/audio/GND_X: P2.4, U5.7
/audio/LHPOUT: C22.1, U1.22, U5.1
/audio/LHPOUT_X: P2.2, U5.8
/audio/LRCK_R: RP1.2, U1.13
/audio/MIC: C25.2, R18.2, U5.3
/audio/MIC_X: P2.1, U5.6
/audio/PDN#_R: R2.1, RP1.4, U1.8
/audio/REGFIL: C12.2, U1.31
/audio/RHPOUT: C23.1, U1.23, U5.4
/audio/RHPOUT_X: P2.3, U5.5
/audio/SCL: FB3.1, P22.26, U1.9
/audio/SDA: FB1.1, P22.24, U1.10
/audio/SDTO_R: RP1.3, U1.12
/audio/SPN: J1.1, U1.19
/audio/SPP: J1.3, U1.20
/audio/VCOM: C10.2, U1.30
/audio/VEE: C8.1, U1.24
/hackrf_if/AUDIO_RESET#: RP1.5, U3.4
/hackrf_if/CLKIN: P22.2, R21.1, R22.1
/hackrf_if/GPS_RESET#: R25.1, U3.7, U8.9
/hackrf_if/GPS_TIMEPULSE: U3.35, U8.4
/hackrf_if/GPS_TX_READY: U3.36, U8.2
/hackrf_if/H1_CPLD_TCK: P28.17, U3.16
/hackrf_if/I2S0_MCLK: P22.17, U1.15
/hackrf_if/I2S0_RX_SDA: P28.19, RP1.6, U3.15
/hackrf_if/I2S0_TX_SDA: P22.13, U1.11
/hackrf_if/I2S0_WS: P22.15, RP1.7
/hackrf_if/LCD_BACKLIGHT: U3.37, U4.1
/hackrf_if/LCD_DB0: J3.32, U3.59
/hackrf_if/LCD_DB1: J3.31, U3.58
/hackrf_if/LCD_DB2: J3.30, U3.56
/hackrf_if/LCD_DB3: J3.29, U3.55
/hackrf_if/LCD_DB4: J3.28, U3.54
/hackrf_if/LCD_DB5: J3.27, U3.53
/hackrf_if/LCD_DB6: J3.26, U3.52
/hackrf_if/LCD_DB7: J3.25, U3.51
/hackrf_if/LCD_DB8: J3.24, U3.50
/hackrf_if/LCD_DB9: J3.23, U3.49
/hackrf_if/LCD_DB10: J3.22, U3.48
/hackrf_if/LCD_DB11: J3.21, U3.47
/hackrf_if/LCD_DB12: J3.20, U3.46
/hackrf_if/LCD_DB13: J3.19, U3.45
/hackrf_if/LCD_DB14: J3.18, U3.44
/hackrf_if/LCD_DB15: J3.17, U3.43
/hackrf_if/LCD_RD#: J3.35, U3.60
/hackrf_if/LCD_RESET#: J3.10, R19.1, U3.38
/hackrf_if/LCD_RS: J3.37, U3.62
/hackrf_if/LCD_TE: J3.39, U3.63
/hackrf_if/LCD_WR#: J3.36, U3.61
/hackrf_if/MCU_ADDR: P22.19, U3.33
/hackrf_if/MCU_D0: P20.5, U3.26
/hackrf_if/MCU_D1: P20.6, U3.27
/hackrf_if/MCU_D2: P20.7, U3.24
/hackrf_if/MCU_D3: P20.8, U3.22
/hackrf_if/MCU_D4: P20.9, U3.20
/hackrf_if/MCU_D5: P20.10, U3.21
/hackrf_if/MCU_D6: P20.11, U3.19
/hackrf_if/MCU_D7: P20.12, U3.18
/hackrf_if/MCU_DIR: P22.22, U3.42
/hackrf_if/MCU_IO_STBX: P22.20, U3.32
/hackrf_if/MCU_LCD_RD: P22.5, U3.30
/hackrf_if/MCU_LCD_TE: P22.6, U3.31
/hackrf_if/MCU_LCD_WR: P22.21, U3.40
/hackrf_if/P2_8: P22.23, U3.34
/hackrf_if/PP_CPLD_TDO: P28.10, U3.17
/hackrf_if/PP_CPLD_TMS: P28.8, U3.14
/hackrf_if/REF_EN: R15.2, R16.1, U3.5, X1.1
/hackrf_if/RESET#: P22.3, U3.29
/hackrf_if/SD_CD: J2.B, P28.3
/hackrf_if/SD_CLK: J2.5, P28.11
/hackrf_if/SD_CMD: J2.3, P28.9
/hackrf_if/SD_DAT0: J2.7, P28.7
/hackrf_if/SD_DAT1: J2.8, P28.6
/hackrf_if/SD_DAT2: J2.1, P28.5
/hackrf_if/SD_DAT3: J2.2, P28.4
/hackrf_if/SW_D: SW1.S2, U3.10
/hackrf_if/SW_L: SW1.S5, U3.28
/hackrf_if/SW_R: SW1.S3, U3.9
/hackrf_if/SW_ROT_A: SW1.A, U3.11
/hackrf_if/SW_ROT_B: SW1.B, U3.12
/hackrf_if/SW_SEL: SW1.S1, U3.13
/hackrf_if/SW_U: SW1.S4, U3.25
/hackrf_if/TP_D: J3.45, P20.16, U3.1
/hackrf_if/TP_L: J3.46, P20.18, U3.2
/hackrf_if/TP_R: J3.44, P20.14, U3.64
/hackrf_if/TP_U: J3.47, P20.20, U3.3
/hackrf_if/VBAT: BT1.1, C41.1, P20.1, R24.1
/hackrf_if/VBUS: C1.1, P20.21, R7.1, U6.13
/hackrf_if/VBUSCTRL: P20.17, R7.2
/lcd_sw_sd/LEDK1: J3.2, U4.3
/lcd_sw_sd/LEDK2: J3.3, U4.4
/lcd_sw_sd/LEDK3: J3.4, U4.5
/lcd_sw_sd/LEDK4: J3.5, U4.6
/power/AUDIO_SVDD: C5.1, C13.1, C16.1, P20.22, R3.1, R5.1, R13.1, U1.18, U6.10, U6.11
/power/BBAT: C15.1, J4.1, U6.2, U6.3
GND: BT1.2, C1.2, C2.2, C3.2, C4.2, C5.2, C7.2, C8.2, C9.2, C10.1, C11.2, C12.1, C13.2, C14.2, C15.2, C16.2, C18.2, C19.2, C20.2, C26.2, C27.2, C28.2, C29.2, C30.2, C31.2, C32.2, C33.2, C34.2, C35.2, C36.2, C37.2, C38.2, C39.2, C40.2, C41.2, C42.2, C43.2, H2.1, H3.1, H4.1, H5.1, J1.2, J2.0, J2.6, J2.A, J2.SH, J3.7, J3.8, J3.9, J3.11, J3.12, J3.13, J3.14, J3.15, J3.16, J3.34, J3.38, J3.43, J3.48, J3.49, J3.50, J3.SHLD, J4.2, P1.2, P20.13, P20.15, P20.19, P22.4, P22.10, P22.18, P28.2, P28.12, R1.2, R2.2, R4.2, R6.2, R8.2, R9.2, R10.2, R11.2, R12.2, R14.2, R16.2, R19.2, R20.2, R25.2, SW1.CA, SW1.CB, U1.17, U1.25, U1.29, U1.33, U2.2, U3.65, U4.2, U4.9, U5.2, U5.9, U6.8, U6.17, U7.3, U8.1, U8.10, U8.12, U8.15, X1.2
unnamed: C9.1, FB2.2, X1.4
unnamed: C17.1, R21.2, X1.3
unnamed: C17.2, R17.2, U7.2
unnamed: C19.1, L1.2, R26.2
unnamed: C22.2, R11.1
unnamed: C23.2, R12.1
unnamed: C25.1, U1.3
unnamed: C39.1, U2.4
unnamed: D1.A, R3.2
unnamed: D1.C, U6.7
unnamed: D2.A, R5.2
unnamed: D2.C, U6.9
unnamed: FB1.2, U8.16
unnamed: FB3.2, U8.17
unnamed: L1.1, P1.1, U8.11
unnamed: R1.1, U6.14
unnamed: R4.1, U6.12
unnamed: R6.1, U6.16
unnamed: R8.1, U6.1
unnamed: R9.1, U6.4
unnamed: R10.1, U6.15
unnamed: R13.2, U6.6
unnamed: R14.1, U6.5
unnamed: R17.1, R22.2, U7.4
unnamed: R18.1, U1.4
unnamed: R20.1, U4.7
unnamed: R23.1, R24.2, U8.6
unnamed: R26.1, U8.14
unnamed: TP1.1, U1.32
unnamed: TP2.1, U1.1
unnamed: TP3.1, U1.2
unnamed: TP4.1, U1.5
unnamed: TP5.1, U1.6
unnamed: TP6.1, U1.7
unnamed: TP7.1, U8.18
unnamed: TP8.1, U8.5
unnamed: TP9.1, U8.3

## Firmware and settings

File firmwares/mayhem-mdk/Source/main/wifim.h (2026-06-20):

/*
 * Copyright (C) 2024 HTotoo
 *
 * This file is part of ESP32-Portapack.
 *
 * For additional license information, see the LICENSE file.
 */

#ifndef WIFIM_H
#define WIFIM_H

// no need to change, just connect to the AP, and change in the settings.
#define DEFAULT_WIFI_HOSTNAME "ESP32PP"
#define DEFAULT_WIFI_AP "ESP32PP"
#define DEFAULT_WIFI_PASS "12345678"
#define DEFAULT_WIFI_STA "-"

#include <string.h>
#include "esp_event.h"
#include "esp_log.h"
#include "nvs_flash.h"
#include "string.h"
#include "esp_system.h"
#include "esp_wifi.h"
#include "esp_netif.h"
#include "freertos/FreeRTOS.h"
#include "freertos/event_groups.h"
#include "esp_netif_ip_addr.h"

#include "freertos/task.h"
#include "mdns.h"
#include <string>

#define CONFIG_AP_MAX_STA_CONN 4
#define WIFI_CLIENR_RC_TIME 35000

// wifi config from companion app
typedef struct wifi_config_comp_t {
    char ssid[30];
    char password[30];
} wifi_config_comp_t;

typedef struct wifi_current_data_t {
    uint8_t ip[4];
    char sta_ssid[30];
    char sta_password[30];
    char ap_ssid[30];
    char ap_password[30];
} wifi_current_data_t;

class WifiM {
   public:
    static void set_airplane_mode(uint8_t mode);
    static bool getWifiStaStatus();
    static void wifi_loop(uint32_t millis);
    static bool config_wifi_apsta();
    static void initialise_wifi(void);
    static void event_handler(void* arg, esp_event_base_t event_base, int32_t event_id, void* event_data);
    static void initialise_mdns(void);
    static int getWifiApClientNum();
    static void save_config_wifi();
    static void load_config_wifi();
    static std::string getStaIp();
    static std::string getApIp();
    static void copyIpToArray(uint8_t* arr);

    static char wifiAPSSID[64];
    static char wifiAPPASS[64];
    static char wifiStaSSID[64];
    static char wifiStaPASS[64];
    static char wifiHostName[64];

   private:
    static int ap_client_num;
    static uint8_t currIp[4];

    static uint32_t last_wifi_conntry;
    static bool wifi_sta_ok;

    static uint8_t mode;  // 1 off, 2 on //airplane mode
    static esp_netif_t* esp_netif_ap;
    static esp_netif_t* esp_netif_sta;
};

#endif

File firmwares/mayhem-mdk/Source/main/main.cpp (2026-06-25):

/*
 * Copyright (C) 2025 HTotoo
 *
 * This file is part of ESP32-Portapack.
 *
 * For additional license information, see the LICENSE file.
 */

// todo save hmc calibration, and load and use, and recalibrate on the fly

// todo add an option to disable rtc set (bc utc only)
// todo add +- time (timezones)
// todo move sattrack to EP_App format
// todo add application start / stop commands to i2c app manager part
// todo add custom wifi ap spam options
// todo add wifispam + app to pp.
// todo add dyn pin configuration options, and save them to nvs. when not set, show the webpage to set it. allow vendor preset on compile, to default to that, not to not set
// todo wifi spam rework. send multiple different at once, so it is faster, and needs less frequent caling

#include <inttypes.h>
#include "pinconfig.h"
#ifndef HW_VARIANT_SELECTED
// !!!!!!!!!!!!!!!!!!!!!!!!!!!!!!!!!!!!!!!!!!!!!!!!!!!!!!!!!!!!!!!!!!!!!!!!!!!!!!!!!!!!!!!!!!!!!!!!!!!!!!!!!!!!!!!!!!!!!!!!!!!!!!!!!!!!!!!!!!!!!!!!!!!!!!!!!
// YOU CAN SET HERE THE DEFAULT PINS FOR YOUR BUILD! IF you don't select any, the pin configiguration webpage will be shown to you. (NIY, SO SELECT ONE!)
// !!!!!!!!!!!!!!!!!!!!!!!!!!!!!!!!!!!!!!!!!!!!!!!!!!!!!!!!!!!!!!!!!!!!!!!!!!!!!!!!!!!!!!!!!!!!!!!!!!!!!!!!!!!!!!!!!!!!!!!!!!!!!!!!!!!!!!!!!!!!!!!!!!!!!!!!!

// select this if you want to let user choose pin config from the web ui
#define HW_VARIANT_SELECTED HW_VARIANT_CUSTOM

// select this if you have OSDR AI EXTENSION BOARD
// #define HW_VARIANT_SELECTED HW_VARIANT_PRFAI

// select this if you have built yourself one based on this project's first pinout config (from the wiki)
// #define HW_VARIANT_SELECTED HW_VARIANT_ESP32PP

// select this, if you have MDK board
// #define HW_VARIANT_SELECTED HW_VARIANT_MDK_BOARD

// select this for Meshtonic H4M Companion v2 (shared I2C 5/6 + GPS on UART1 RX GPIO7)
// #define HW_VARIANT_SELECTED HW_VARIANT_MESHTONIC_H4M

// !!!!!!!!!!!!!!!!!!!!!!!!!!!!!!!!!!!!!!!!!!!!!!!!!!!!!!!!!!!!!!!!!!!!!!!!!!!!!!!!!!!!!!!!!!!!!!!!!!!!!!!!!!!!!!!!!!!!!!!!!!!!!!!!!!!!!!!!!!!!!!!!!!!!!!!!
#endif
#include <stdio.h>
#include <string.h>
#include <iostream>
#include <fstream>
#include <vector>
#include "wifihack.hpp"
#include "esp_err.h"
#include "esp_log.h"
#include "esp_system.h"
#include "esp_timer.h"
#include "esp_task_wdt.h"
#include "freertos/FreeRTOS.h"
#include "freertos/semphr.h"
#include "freertos/task.h"
#include "configuration.h"
#include "esp_spiffs.h"
#include "esp_http_client.h"
#include "esp_sntp.h"

#include "sensordb.h"

#include <driver/temperature_sensor.h>
#include "apps/appmanager.hpp"

bool gpsDebug = false;  // set to false, and give it an ui to be able to turn it on / off
uint8_t gps_debug_limiter = 0;
#include "webserver.h"

#include "nmea_parser.h"
#include "wifim.h"
#include "ppshellcomm.h"
#include "orientation.h"
#include "environment.h"
#include "drivers/tca9548a.h"
#include "drivers/mcp23017.h"
#include "meshtonic_board.h"
#include <driver/i2c.h>
#include <driver/gpio.h>
#include "sx_manager.hpp"

#include "tir.h"

#include "ppi2c/pp_handler.hpp"
#include "pp_commands.hpp"

uint8_t time_method = 0;  // 0 = no valid, 1 = gps, 2 = ntp

uint8_t airplane_mode = 1;      // 1 off, 2 on. 0 query
uint8_t airplane_mode_new = 0;  // 0 no change, other: new value

uint8_t shutdown_countdown = 0;  // when it is 1, init a shutdown. if >1 decrease it in every loop. if 0, ignore it. when the callback hits, set it to 10, so i2c reply can go through, and then shut down.

#include "sgp4/Sgp4.h"
#include "../extapps/sattrack.h"
#include "../extapps/wifisettings.h"
#include "../extapps/tirapp.h"
#include "../extapps/espmanager.h"
#include "../extapps/espapps.h"
#include "../extapps/meshtonic_lora.h"  // Meshtonic LoRa rich UI binary placeholder (apps over I2C)
#include "lora_bands.h"  // for LoraBandPreset + g_lora_presets in rich I2C PRESETS handler
#include "lora_decoder_feed.h"  // rich I2C accessors (packets, status, apply) for apps-over-I2C UI

#include "display/displaymanager.hpp"

#define TAG "ESP32PP"

#ifndef HW_VARIANT_SELECTED
#define HW_VARIANT_SELECTED HW_VARIANT_CUSTOM
#endif
PinConfig pinConfig(HW_VARIANT_SELECTED);

DisplayManager displayManager;

// Meshtonic H4M board devices (initialized when profile == MESHTONIC_H4M)
 // (see meshtonic_board.{h,c} for the g_ globals and helpers)
SXRadioManager sxManager;
Sgp4 sat;

static void IRAM_ATTR meshtonicMcpIntaIsrThunk(void*) {
    sxManager.serviceInterruptsFromIsr();
}
TIR tir;

typedef enum TimerEntry {
    TimerEntry_SENSORGET,
    TimerEntry_REPORTPPGPS,
    TimerEntry_REPORTPPORI,
    TimerEntry_REPORTPPENVI,
    TimerEntry_REPORTPPTIME,
    TimerEntry_REPORTWEB,
    TimerEntry_REPORTSTATES,
    TimerEntry_SATTRACK,
    TimerEntry_SATDOWN,
    TimerEntry_MAX
} TimerEntry;
uint32_t time_millis = 0;  // current time in millis
uint32_t last_millis[TimerEntry_MAX] = {0};
// ______________________________________SEN    GPS  ORI    ENV   TIME        WEB   RGB   SAT    DOWN
uint32_t timer_millis[TimerEntry_MAX] = {2000, 2000, 1000, 2000, 60000 * 10, 2000, 1000, 2000, 20000};

// default sensor values and declaration
orientation_t orientation{400.0, 0.0};
environment_t environment{0.0, 0.0, 0.0};  // temperature, humidity, pressure
float temperatureEsp = 0.0;
uint16_t light = 0;
ppgpssmall_t gpsdata{200, 200, 0, 0, 0, 0, {}, {}};
ir_data_t last_rcvd_ir{UNK, 0, 0};

bool gotAnyGps = false;

bool downloadedTLE = false;
uint16_t lastReportedMxS = 0;  // gps last reported gps time mix to see if it is changed. if not changes, it stuck (bad signal, no update), so won't update PP based on it
uint32_t gps_baud = 9600;
uint32_t i2c_pp_last_comm_time = 0;  // when is it connected last time (last query from pp).
bool i2p_pp_conn_state = false;      // to save and check if i need to send a message to web

typedef struct
{
    float lat;
    float lon;
} sat_mgps_t;

sattrackdata_t sattrackdata;
uint8_t sattrack_task = 0;  // this will set to the main thread what is the current task. 0 = none, 1 = update db, 2 = change sat. each task needs to reset it.
uint8_t sattrack_task_last_error = 0;
std::string sat_to_track = "ISS";
std::string sat_to_track_new = "";
bool sat_data_loaded = false;

bool wifi_config_changed = false;  // if wifi config changed from pp. (irq, so need to save and apply elsewhere)

#include "led.h"

void SetDisplayDirtyMain() {
    displayManager.setDirty();
}

#include "esp_sleep.h"
#include "driver/rtc_io.h"

void shutdownme() {
    ESP_LOGI(TAG, "Shutting down...");
    LedFeedback::rgb_set(0, 0, 0);  // turn off led
    // todo power off other pheriphrals.
    for (int gpio = 0; gpio < GPIO_NUM_MAX; gpio++) {
        // CRITICAL: Skip internal SPI Flash and PSRAM pins.  Without these, the ESP32-S3 cannot read its own code.
        if (gpio >= 26 && gpio <= 37) {
            continue;
        }
        // Check if the pin actually exists on this hardware
        if (GPIO_IS_VALID_GPIO(gpio)) {
            // Attempt to isolate. Non-RTC pins will return an error, which is safely ignored.
            rtc_gpio_isolate((gpio_num_t)gpio);
        }
    }

    esp_deep_sleep_start();
}

static void i2c_scan(int sda, int scl) {
    if (sda < 0 || scl < 0) {
        ESP_LOGW(TAG, "I2C pins not set. Skipping I2C scan.");
        return;
    }
    vTaskDelay(50 / portTICK_PERIOD_MS);  // wait till devs wake up
    esp_err_t res;
    printf("i2c scan: \n");
    i2c_dev_t dev = {};
    dev.cfg.sda_io_num = sda;
    dev.cfg.scl_io_num = scl;
    dev.cfg.master.clk_speed = 400000;
    for (uint8_t i = 1; i < 127; i++) {
        dev.addr = i;
        res = i2c_dev_probe(&dev, I2C_DEV_WRITE);
        if (res == 0) {
            printf("Found device at: 0x%2x\n", i);
            foundI2CDev(i);
        }
    }
}

ChipFeatures chipFeatures{};
void update_features() {
    chipFeatures.reset();
    if (is_environment_light_sensor_present())
        chipFeatures.enableFeature(SupportedFeatures::FEAT_LIGHT);
    if (is_environment_sensor_present())
        chipFeatures.enableFeature(SupportedFeatures::FEAT_ENVIRONMENT);
    if (is_orientation_sensor_present())
        chipFeatures.enableFeature(SupportedFeatures::FEAT_ORIENTATION);
    if (gotAnyGps || pinConfig.hasGPS())
        chipFeatures.enableFeature(SupportedFeatures::FEAT_GPS);
    if (PPHandler::get_appCount() > 0)
        chipFeatures.enableFeature(SupportedFeatures::FEAT_EXT_APP);
    // uart is not present
    if (displayManager.getDisplayCount() > 0)
        chipFeatures.enableFeature(SupportedFeatures::FEAT_DISPLAY);
    chipFeatures.enableFeature(SupportedFeatures::FEAT_SHELL);

    if (pinConfig.getProfile() == PinConfig::BoardProfile::MESHTONIC_H4M)
        chipFeatures.enableFeature(SupportedFeatures::FEAT_MESHTONIC);
}

esp_err_t init_spiffs(void) {
    // Configuration settings for SPIFFS
    esp_vfs_spiffs_conf_t conf = {
        .base_path = "/spiffs",         // Mount point for the file system
        .partition_label = NULL,        // Use default partition
        .max_files = 5,                 // Maximum number of open files
        .format_if_mount_failed = true  // Don't format on mount failure automatically
    };

    // Initialize SPIFFS with the configuration
    esp_err_t ret = esp_vfs_spiffs_register(&conf);

    // Check if SPIFFS was mounted successfully
    if (ret == ESP_OK) {
        ESP_LOGI(TAG, "SPIFFS mounted successfully.");
    } else if (ret == ESP_FAIL) {
        ESP_LOGE(TAG, "Failed to mount SPIFFS, attempting to format...");

        // Try formatting SPIFFS
        ret = esp_spiffs_format(NULL);  // Pass partition label if needed
        if (ret == ESP_OK) {
            ESP_LOGI(TAG, "SPIFFS formatted successfully, retrying mount...");

            // Retry mounting after format
            ret = esp_vfs_spiffs_register(&conf);
            if (ret == ESP_OK) {
                ESP_LOGI(TAG, "SPIFFS mounted successfully after format.");
            } else {
                ESP_LOGE(TAG, "Failed to mount SPIFFS after formatting.");
            }
        } else {
            ESP_LOGE(TAG, "SPIFFS format failed.");
        }
    } else {
        ESP_LOGE(TAG, "Failed to initialize SPIFFS (%s)", esp_err_to_name(ret));
    }

    // Check the SPIFFS partition size and used space
    size_t total = 0, used = 0;
    ret = esp_spiffs_info(NULL, &total, &used);
    if (ret == ESP_OK) {
        ESP_LOGI(TAG, "SPIFFS: total: %d bytes, used: %d bytes", total, used);
    } else {
        ESP_LOGE(TAG, "Failed to get SPIFFS partition information (%s)", esp_err_to_name(ret));
    }

    return ret;
}

/**
 * @brief HTTP event handler to handle HTTP client events during the download.
 *
 * @param evt HTTP client event.
 * @return esp_err_t Returns ESP_OK to continue the operation, or an error code to abort.
 */
esp_err_t http_event_handler_tledata(esp_http_client_event_t* evt) {
    static FILE* file = NULL;

    switch (evt->event_id) {
        case HTTP_EVENT_ON_DATA:
            if (!file) {
                // Open the file for writing when the first data chunk is received
                file = fopen("/spiffs/mini.tle", "w");
                if (file == NULL) {
                    ESP_LOGE(TAG, "Failed to open file for writing");
                    return ESP_FAIL;
                }
            }

            // Write the data chunk to the file
            if (fwrite(evt->data, 1, evt->data_len, file) != evt->data_len) {
                ESP_LOGE(TAG, "File write failed!");
                fclose(file);
                file = NULL;
                return ESP_FAIL;
            }
            break;

        case HTTP_EVENT_ON_FINISH:
            if (file) {
                fclose(file);
                file = NULL;
                ESP_LOGI(TAG, "File download completed");
            }
            break;

        case HTTP_EVENT_ERROR:
            ESP_LOGE(TAG, "HTTP event error");
            if (file) {
                fclose(file);
                file = NULL;
            }
            break;

        default:
            break;
    }
    return ESP_OK;
}
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
void app_main(void) {
    esp_err_t err = nvs_flash_init();
    if (err == ESP_ERR_NVS_NO_FREE_PAGES || err == ESP_ERR_NVS_NEW_VERSION_FOUND) {
        ESP_ERROR_CHECK(nvs_flash_erase());
        err = nvs_flash_init();
    }
    ESP_ERROR_CHECK(err);
    // load prev settings
    WifiM::load_config_wifi();

    ESP_LOGI(TAG, "Loading saved PinConfig.");
    pinConfig.loadFromNvs();

    // Auto-apply typed Meshtonic H4M profile when pins match the preset (or variant was selected at build)
    {
        bool matchesMeshtonic =
            (pinConfig.I2cSdaPin() == 5 && pinConfig.I2cSclPin() == 6 &&
             pinConfig.GpsRxPin() == 7 &&
             pinConfig.I2cSdaSlavePin() == 5 && pinConfig.I2cSclSlavePin() == 6);
        if (matchesMeshtonic || pinConfig.getProfile() == PinConfig::BoardProfile::MESHTONIC_H4M) {
            if (pinConfig.getProfile() != PinConfig::BoardProfile::MESHTONIC_H4M) {
                pinConfig.setProfile(PinConfig::BoardProfile::MESHTONIC_H4M);
            }
            if (pinConfig.getRadioCount() <= 0) pinConfig.setRadioCount(1);
            // sensor mask can be set by sensor init later; default leave as loaded or 0
        }
    }

    load_config_misc();

    init_spiffs();
    sat.site(0, 0, 34);
    sat_data_loaded = (load_satellite_tle(sat_to_track) == ESP_OK);

    // end config load
    i2cdev_init();
    // i2c scanner
    i2c_scan(pinConfig.I2cSdaPin(), pinConfig.I2cSclPin());

    // Meshtonic H4M specific expanders (TCA + MCP) when profile active
    if (pinConfig.getProfile() == PinConfig::BoardProfile::MESHTONIC_H4M) {
        int sda = pinConfig.I2cSdaPin();
        int scl = pinConfig.I2cSclPin();
        if (sda >= 0 && scl >= 0) {
            // TCA9548A at 0x70 (A0..A2 = 0)
            if (tca9548a_init_desc(&g_tca, TCA9548A_ADDR_BASE, I2C_NUM_0, (gpio_num_t)sda, (gpio_num_t)scl) == ESP_OK) {
                if (tca9548a_select(&g_tca, 0) == ESP_OK) {
                    g_tca_ready = true;
                    ESP_LOGI(TAG, "TCA9548A ready (Meshtonic)");
                }
            } else {
                ESP_LOGW(TAG, "TCA9548A init failed");
            }
            // MCP23017 at 0x20
            if (mcp23017_init_desc(&g_mcp, MCP23017_ADDR_BASE, I2C_NUM_0, (gpio_num_t)sda, (gpio_num_t)scl) == ESP_OK) {
                // Compute radio count early for pin direction setup
                int rc = pinConfig.getRadioCount();
                if (rc <= 0) rc = 1;
                sxManager.setRadioCount(rc);

                // v2 map: chip-selects are native ESP32-S3 GPIOs (configured in
                // sxManager.init), so the MCP only carries per-radio status inputs +
                // shared control outputs. BUSY (all slots) = MCP input; DIO1 for slots
                // 1-3 = MCP input+pullup+INT (WIO1 DIO1 is a native GPIO, handled below).
                for (int s = 0; s < rc; s++) {
                    int bu = sxManager.getBusyMcpPin(s);
                    if (bu >= 0 && bu < 16) {
                        mcp23017_set_pin_direction(&g_mcp, (uint8_t)bu, true); // input
                    }
                    if (!sxManager.isDio1Native(s)) {
                        int di = sxManager.getDio1McpPin(s);
                        if (di >= 0 && di < 16) {
                            mcp23017_set_pin_direction(&g_mcp, (uint8_t)di, true); // input
                            mcp23017_set_pullup(&g_mcp, (uint8_t)di, true);
                            mcp23017_set_interrupt(&g_mcp, (uint8_t)di, true);
                        }
                    }
                }
                g_mcp_ready = true;

                // Shared control lines on the MCP GPB bank: LORA_RST (GPB4) idle high,
                // RF switch enable (GPB0) disabled until a radio arms RX.
                mcp23017_set_pin_direction(&g_mcp, (uint8_t)sxManager.getSharedRstMcpPin(), false);
                meshtonic_mcp_write_pin((uint8_t)sxManager.getSharedRstMcpPin(), true);
                mcp23017_set_pin_direction(&g_mcp, (uint8_t)sxManager.getRfSwEnMcpPin(), false);
                meshtonic_mcp_write_pin((uint8_t)sxManager.getRfSwEnMcpPin(), false);
                ESP_LOGI(TAG, "MCP23017 ready (Meshtonic v2, %d radios, BUSY/DIO1 inputs + shared RST/RFSW set)", rc);

                // WIO1 DIO1 is a native ESP32-S3 GPIO (not on the MCP) — configure as input.
                gpio_config_t d1 = {};
                d1.pin_bit_mask = (1ULL << sxManager.getDio1Gpio(0));
                d1.mode = GPIO_MODE_INPUT;
                d1.pull_up_en = GPIO_PULLUP_DISABLE;
                d1.pull_down_en = GPIO_PULLDOWN_DISABLE;
                d1.intr_type = GPIO_INTR_DISABLE;
                gpio_config(&d1);

                // MCP INTA is wired to native GPIO44 (D7) on v2 (was GPIO10 on v1;
                // GPIO10 is now CS_WIO3). Configure as input + pullup so it can be sensed.
                const int intaGpio = sxManager.getMcpIntaGpio();
                gpio_config_t ina = {};
                ina.pin_bit_mask = (1ULL << intaGpio);
                ina.mode = GPIO_MODE_INPUT;
                ina.pull_up_en = GPIO_PULLUP_ENABLE;
                ina.pull_down_en = GPIO_PULLDOWN_DISABLE;
                ina.intr_type = GPIO_INTR_DISABLE; // will be set to edge when ISR registered in phase 2
                gpio_config(&ina);

                // Install ISR service (idempotent if called multiple) and attach handler for INTA
                static bool isrServiceInstalled = false;
                if (!isrServiceInstalled) {
                    gpio_install_isr_service(0);
                    isrServiceInstalled = true;
                }
                // Attach falling edge (MCP INTA active low on event)
                gpio_set_intr_type((gpio_num_t)intaGpio, GPIO_INTR_NEGEDGE);
                gpio_isr_handler_add((gpio_num_t)intaGpio, meshtonicMcpIntaIsrThunk, nullptr);
                ESP_LOGI(TAG, "MCP INTA ISR attached on GPIO%d", intaGpio);
            } else {
                ESP_LOGW(TAG, "MCP23017 init failed");
            }

            // Meshtonic TCA discovery pass for full sensor inventory (populates sensordb + channel map)
            if (g_tca_ready) {
                for (uint8_t ch = 0; ch < 4; ch++) {
                    if (meshtonic_tca_select(ch) == ESP_OK) {
                        // probe common Meshtonic addresses on this channel
                        for (uint8_t a : {0x10u,0x11u,0x12u,0x13u, 0x36u, 0x44u,0x45u, 0x68u,0x69u, 0x76u,0x77u}) {
                            i2c_dev_t p = {};
                            p.port = I2C_NUM_0;
                            p.addr = a;
                            p.cfg.sda_io_num = (gpio_num_t)sda;
                            p.cfg.scl_io_num = (gpio_num_t)scl;
                            p.cfg.master.clk_speed = 400000;
                            if (i2c_dev_probe(&p, I2C_DEV_WRITE) == ESP_OK) {
                                foundI2CDevOnChannel(a, ch);
                            }
                        }
                    }
                }
                meshtonic_tca_select(0xFF);
                ESP_LOGI(TAG, "Meshtonic TCA sensor discovery done");
            }

            // Initialize radio slot manager for 1-4 Wio SX1262
            int rc = pinConfig.getRadioCount();
            if (rc <= 0) rc = 1;
            sxManager.init(rc);

            // Standalone field use: LoRa decoder runs on boot (no host PC).
            AppManager::startApp(AppList::LORADECODER);
            ESP_LOGI(TAG, "Meshtonic H4M: LoRa Decoder auto-started");
        }
    }

    ESP_ERROR_CHECK(esp_event_loop_create_default());
    PPShellComm::init();

    WifiM::initialise_wifi();
    WifiM::config_wifi_apsta();
    esp_sntp_setoperatingmode(ESP_SNTP_OPMODE_POLL);
    esp_sntp_setservername(0, "pool.ntp.org");
    esp_sntp_init();
    sntp_set_time_sync_notification_cb(time_sync_notification_cb);

    init_httpd();
    nmea_parser_config_t nmeaconfig = NMEA_PARSER_CONFIG_DEFAULT();
    nmeaconfig.uart.baud_rate = gps_baud;
    nmeaconfig.uart.rx_pin = pinConfig.GpsRxPin();
    if (nmeaconfig.uart.rx_pin == 256) {
        ESP_LOGW(TAG, "GPS Rx pin not set. GPS disabled.");
    } else {
        nmea_parser_handle_t nmea_hdl = nmea_parser_init(&nmeaconfig);
        nmea_parser_add_handler(nmea_hdl, gps_event_handler, NULL);
    }
    esp_task_wdt_deinit();
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

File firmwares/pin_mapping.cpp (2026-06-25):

// Seeed XIAO ESP32-S3 Plus — Meshtonic H4M v2 Pinout
//
// Verified against pcb/meshtonic_h4m_v2.kicad_pcb netlist and the official
// Espressif XIAO_ESP32S3_Plus D->GPIO mapping (arduino-esp32 pins_arduino.h /
// Seeed wiki). NOTE: on the Plus, Dn != GPIOn above D5 — the mapping is
// irregular (D11=GPIO38 ... D19=GPIO11), so these constants are the REAL
// silicon GPIO numbers, not the D-label numbers.
//
// Strategy: one shared SPI bus (CLK/MOSI/MISO via the ESP32-S3 GPIO matrix) with
// a separate native-GPIO chip-select per Wio-SX1262 shield, so up to 4 radios
// share SPI2/FSPI. Per-radio BUSY/DIO1 that don't fit on native pins are read
// back through an MCP23017 I2C expander.

// UART0 (freed: console runs on USB-Serial-JTAG)
#define UART0_TX    1   // D0
#define UART0_RX    2   // D1

// Wio-SX1262 chip-selects — native ESP32-S3 GPIO (shared SPI bus)
#define CS_WIO1     3   // D2  (NOTE: GPIO3 is a strapping pin / JTAG sel — output, idle high)
#define CS_WIO2     4   // D3
#define CS_WIO3     10  // D16
#define CS_WIO4     13  // D17

// I2C (native — sensors via TCA9548A, MCP23017, AS5600)
#define I2C_SDA     5   // D4
#define I2C_SCL     6   // D5

// Shared SPI bus (Wio-SX1262 x4 + ILI9341 + microSD), routed via GPIO matrix
#define SPI_MOSI    38  // D11
#define SPI_MISO    39  // D12 (JTAG MTCK — fine without a HW debug probe)
#define SPI_CLK     40  // D13 (JTAG MTDO)

// UART1 (GPS NEO-6M / external)
#define UART1_RX    7   // D8
#define UART1_TX    8   // D9

// TFT (ILI9341) control
#define TFT_DC      43  // D6  (UART0 TXD repurposed)
#define TFT_RST     9   // D10
#define TFT_CS      11  // D19
#define MCP_INT     44  // D7  (UART0 RXD repurposed — MCP23017 INTA to ESP)

// Misc native
#define WIO1_DIO1   12  // D18 (slot-0 DIO1 is native; WIO2..4 DIO1 are on the MCP23017)
#define CS_SD       42  // D15 (JTAG MTMS)
#define ADC_LIGHT   41  // D14 (JTAG MTDI — digital only, NOT ADC-capable: read as GPIO or defer)

// MCP23017 @ 0x20 — GPA bank = per-radio status, GPB bank = shared control + LEDs
// GPA0..3 = WIO1..4 BUSY
// GPA4..6 = WIO2..4 DIO1   (WIO1 DIO1 is native GPIO12 above)
// GPB0    = WIO_RF_SW_EN
// GPB1    = CS_GROVE
// GPB4    = LORA_RST (shared across all 4 radios)
// GPB5..7 = LED_WIO1..3
#define MCP23017_ADDR    0x20
#define MCP_BUSY_WIO1    0   // GPA0
#define MCP_BUSY_WIO2    1   // GPA1
#define MCP_BUSY_WIO3    2   // GPA2
#define MCP_BUSY_WIO4    3   // GPA3
#define MCP_DIO1_WIO2    4   // GPA4
#define MCP_DIO1_WIO3    5   // GPA5
#define MCP_DIO1_WIO4    6   // GPA6
#define MCP_RF_SW_EN     8   // GPB0
#define MCP_LORA_RST     12  // GPB4 (shared)
#define MCP_LED_WIO1     13  // GPB5
#define MCP_LED_WIO2     14  // GPB6
#define MCP_LED_WIO3     15  // GPB7

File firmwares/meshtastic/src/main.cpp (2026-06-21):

#include "configuration.h"
#if defined(MESHTONIC_H4M)
#include "meshtonic_board.h"
#endif
#if !MESHTASTIC_EXCLUDE_GPS
#include "GPS.h"
#endif
#if !MESHTASTIC_EXCLUDE_INPUTBROKER
#include "input/InputBroker.h"
#endif
#include "MeshRadio.h"
#include "MeshService.h"
#include "NodeDB.h"
#include "PowerFSM.h"
#include "PowerMon.h"
#include "RadioLibInterface.h"
#include "ReliableRouter.h"
#include "TransmitHistory.h"
#include "airtime.h"
#include "buzz.h"
#include "power/PowerHAL.h"

#include "FSCommon.h"
#include "RTC.h"
#include "SPILock.h"
#include "Throttle.h"
#include "concurrency/OSThread.h"
#include "concurrency/Periodic.h"
#include "detect/ScanI2C.h"
#include "error.h"
#include "power.h"

#if !MESHTASTIC_EXCLUDE_I2C
#include "detect/ScanI2CConsumer.h"
#include "detect/ScanI2CTwoWire.h"
#include <Wire.h>
#endif
#include "detect/einkScan.h"
#include "graphics/Screen.h"
#include "main.h"
#include "mesh/generated/meshtastic/config.pb.h"
#include "meshUtils.h"
#include "modules/Modules.h"
#include "sleep.h"
#include "target_specific.h"
#include <memory>
#include <utility>
#if HAS_SCREEN
#include "MessageStore.h"
#endif

#ifdef ARCH_ESP32
#include "freertosinc.h"
#if !MESHTASTIC_EXCLUDE_WEBSERVER
#include "mesh/http/WebServer.h"
#endif
#if !MESHTASTIC_EXCLUDE_BLUETOOTH
#include "nimble/NimbleBluetooth.h"
NimbleBluetooth *nimbleBluetooth = nullptr;
#endif
#endif

#ifdef ARCH_NRF52
#include "NRF52Bluetooth.h"
NRF52Bluetooth *nrf52Bluetooth = nullptr;
#endif

#ifdef ARCH_NRF54L15
void nrf54l15Setup();
void nrf54l15Loop();
NRF54L15Bluetooth *nrf54l15Bluetooth = nullptr;
#endif

#ifdef MESHTASTIC_ENABLE_APPROTECT
#include "security/APProtect.h"
#endif
#ifdef MESHTASTIC_ENCRYPTED_STORAGE
#include "security/EncryptedStorage.h"
#endif
#ifdef MESHTASTIC_PHONEAPI_ACCESS_CONTROL
#include "mesh/PhoneAPI.h"
#endif
#ifdef MESHTASTIC_LOCKDOWN
#include "security/LockdownDisplay.h"
#endif

#if HAS_WIFI || defined(USE_WS5500) || defined(USE_CH390D)
#include "mesh/api/WiFiServerAPI.h"
#include "mesh/wifi/WiFiAPClient.h"
#endif

#if HAS_ETHERNET && !defined(USE_WS5500) && !defined(USE_CH390D)
#include "mesh/api/ethServerAPI.h"
#include "mesh/eth/ethClient.h"
#endif

#if !MESHTASTIC_EXCLUDE_MQTT
#include "mqtt/MQTT.h"
#endif

#ifdef ARCH_PORTDUINO
#include "linux/LinuxHardwareI2C.h"
#include "mesh/raspihttp/PiWebServer.h"
#include "platform/portduino/PortduinoGlue.h"
#include <cstdlib>
#include <fstream>
#include <iostream>
#include <string>
#endif

#ifdef ARCH_ESP32
#ifdef DEBUG_PARTITION_TABLE
#include "esp_partition.h"

void printPartitionTable()
{
    printf("\n--- Partition Table ---\n");
    // Print Column Headers
    printf("| %-16s | %-4s | %-7s | %-10s | %-10s |\n", "Label", "Type", "Subtype", "Offset", "Size");
    printf("|------------------|------|---------|------------|------------|\n");

    // Create an iterator to find ALL partitions (Type ANY, Subtype ANY)
    esp_partition_iterator_t it = esp_partition_find(ESP_PARTITION_TYPE_ANY, ESP_PARTITION_SUBTYPE_ANY, NULL);

    // Loop through the iterator
    if (it != NULL) {
        do {
            const esp_partition_t *part = esp_partition_get(it);

            // Print details: Label, Type (Hex), Subtype (Hex), Offset (Hex), Size (Hex)
            printf("| %-16s | 0x%02x | 0x%02x    | 0x%08x | 0x%08x |\n", part->label, part->type, part->subtype, part->address,
                   part->size);

            // Move to next partition
            it = esp_partition_next(it);
        } while (it != NULL);

        // Release the iterator memory
        esp_partition_iterator_release(it);
    } else {
        printf("No partitions found.\n");
    }
    printf("-----------------------\n");
}
#endif // DEBUG_PARTITION_TABLE
#endif // ARCH_ESP32

#include "AmbientLightingThread.h"
#include "PowerFSMThread.h"

#if !defined(ARCH_STM32WL) && !MESHTASTIC_EXCLUDE_I2C && !MESHTASTIC_EXCLUDE_ACCELEROMETER
#include "motion/AccelerometerThread.h"
AccelerometerThread *accelerometerThread = nullptr;
#endif
#if !defined(ARCH_STM32WL) && !MESHTASTIC_EXCLUDE_I2C && !MESHTASTIC_EXCLUDE_MAGNETOMETER
#include "motion/MagnetometerThread.h"
MagnetometerThread *magnetometerThread = nullptr;
#endif

#ifdef HAS_I2S
#include "AudioThread.h"
AudioThread *audioThread = nullptr;
#endif

#ifdef USE_XL9555
#include "ExtensionIOXL9555.hpp"
ExtensionIOXL9555 io;
#endif

#if HAS_TFT
extern void tftSetup(void);
#endif

#ifdef HAS_UDP_MULTICAST
#include "mesh/udp/UdpMulticastHandler.h"
UdpMulticastHandler *udpHandler = nullptr;
#endif

#if defined(TCXO_OPTIONAL)
float tcxoVoltage = SX126X_DIO3_TCXO_VOLTAGE; // if TCXO is optional, put this here so it can be changed further down.
#endif

#ifdef MESHTASTIC_INCLUDE_NICHE_GRAPHICS
void setupNicheGraphics();
#include "nicheGraphics.h"
#endif

#if defined(HW_SPI1_DEVICE) && defined(ARCH_ESP32)
SPIClass SPI1(HSPI);
#endif

using namespace concurrency;

volatile static const char slipstreamTZString[] = {USERPREFS_TZ_STRING};

// We always create a screen object, but we only init it if we find the hardware
graphics::Screen *screen = nullptr;

// Global power status
meshtastic::PowerStatus *powerStatus = new meshtastic::PowerStatus();

// Global GPS status
meshtastic::GPSStatus *gpsStatus = new meshtastic::GPSStatus();

// Global Node status
meshtastic::NodeStatus *nodeStatus = new meshtastic::NodeStatus();

// Global Bluetooth status
meshtastic::BluetoothStatus *bluetoothStatus = new meshtastic::BluetoothStatus();

// Scan for I2C Devices

/// The I2C address of our display (if found)
ScanI2C::DeviceAddress screen_found = ScanI2C::ADDRESS_NONE;

// The I2C address of the cardkb or RAK14004 (if found)
ScanI2C::DeviceAddress cardkb_found = ScanI2C::ADDRESS_NONE;
// 0x02 for RAK14004, 0x00 for cardkb, 0x10 for T-Deck
uint8_t kb_model;
// global bool to record that a kb is present
bool kb_found = false;
// global bool to record that on-screen keyboard (OSK) is present
bool osk_found = false;

// The I2C address of the RTC Module (if found)
ScanI2C::DeviceAddress rtc_found = ScanI2C::ADDRESS_NONE;
// The I2C address of the Accelerometer (if found)
ScanI2C::DeviceAddress accelerometer_found = ScanI2C::ADDRESS_NONE;
// The I2C address of the Magnetometer (if found)
ScanI2C::DeviceAddress magnetometer_found = ScanI2C::ADDRESS_NONE;
// The I2C address of the RGB LED (if found)
ScanI2C::FoundDevice rgb_found = ScanI2C::FoundDevice(ScanI2C::DeviceType::NONE, ScanI2C::ADDRESS_NONE);
/// The I2C address of our Air Quality Indicator (if found)
ScanI2C::DeviceAddress aqi_found = ScanI2C::ADDRESS_NONE;
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

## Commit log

2026-06-07 share init for seeedstudio init
    [.kicad_sch, .kicad_sch.kicad_sch, Breakout_GPIO.kicad_sch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]
2026-06-07 adds silkscreens init
    [meshtonic.kicad_pcb]
2026-06-14 adds meshtonic board
    [.kicad_sch, .kicad_sch.kicad_sch, Breakout_GPIO.kicad_sch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]
2026-06-20 adds meshtastic firmware
    [.kicad_sch, .kicad_sch.kicad_sch, Breakout_GPIO.kicad_sch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]
2026-06-20 adds meshtonic support to esp32PP firmware
    [configuration.h, partitions.csv]
2026-06-21 Vendor meshtastic and mayhem-firmware as tracked sources
    [.isort.cfg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]
2026-06-23 adds enclosure
    [enclosure_base_65x140x32.stl, enclosure_lid_65x140.stl]
2026-06-25 fixes SCL to SDA on J_AS1
    [Sensors.kicad_sch, meshtonic.csv, meshtonic.kicad_pcb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]
2026-06-25 adds grove connectors fix and rerouting
    [MDK_Interface.kicad_sch, meshtonic_h4m_v2.kicad_pcb]
2026-06-26 adds micro vias and solves some issues
    [meshtonic_h4m_v2-CuBottom.gbr, meshtonic_h4m_v2-CuIn1.gbr, meshtonic_h4m_v2-CuIn2.gbr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]
2026-06-26 solves some issues
    [meshtonic_h4m_v2-CuBottom.gbr, meshtonic_h4m_v2-CuIn1.gbr, meshtonic_h4m_v2-CuIn2.gbr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]
2026-07-08 adds a resistor between TMP and GND in Power sheet to allow battery charging
    [Power.kicad_sch, meshtonic_h4m_v2.kicad_pcb]
2026-07-08 solves no more direct-to-pin vias and routings
    [H4M_Connector.kicad_sch, meshtonic_h4m_v2.kicad_pcb]
2026-08-04 adds licences, top level readme
    [Periferals.kicad_sch, Power.kicad_sch, meshtonic_h4m_v2.csv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]

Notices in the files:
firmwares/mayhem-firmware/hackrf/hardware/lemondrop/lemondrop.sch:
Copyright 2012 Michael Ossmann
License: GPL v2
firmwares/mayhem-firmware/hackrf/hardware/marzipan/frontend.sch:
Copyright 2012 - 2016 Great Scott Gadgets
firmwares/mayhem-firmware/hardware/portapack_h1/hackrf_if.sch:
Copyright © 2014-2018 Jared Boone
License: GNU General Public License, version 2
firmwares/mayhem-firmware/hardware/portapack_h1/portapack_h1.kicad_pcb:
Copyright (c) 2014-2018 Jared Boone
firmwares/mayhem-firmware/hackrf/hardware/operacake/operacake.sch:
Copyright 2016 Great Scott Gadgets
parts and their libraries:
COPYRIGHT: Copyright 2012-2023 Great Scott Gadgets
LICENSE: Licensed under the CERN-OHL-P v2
